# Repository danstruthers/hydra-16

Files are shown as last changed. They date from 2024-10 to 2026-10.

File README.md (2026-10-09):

## **Hydra 16**

A multitasking 65C02 computer and its operating system, HydraOS.

The Hydra-16's hardware gives each of 16 tasks its own 32K of RAM, zero page and stack included, with its own RAM and ROM bank selections, so a task switch is one register write.  HydraOS runs on it, Plan 9's way:
* **One kernel** in the BIOS ROM: a preemptive scheduler, one interrupt path, notes, memory and banks, and a jump table made from a specification.  Everything else is a module of the paged ROM, run in place in a task of its own.
* **A base to build on:** the kernel, a serial console driver, the kernel's devices and Woz's monitor are the base (`base/`), which HydraOS is built on and which boots on its own: [write an OS of your own](base/docs/os.md) on it.
* **Everything a file:** devices are file servers (the console's windows, the disks and HydraFS, sound, GPIO and I2C, the clock, the Vera X, and `/pc`, a folder on the PC over the serial line), and each task has a namespace of its own, built by binds and mounts.
* **Shells and languages:** rc, Plan 9's shell, and the core tools; HyForth (Forth 2012), the login shell; hylang (danlang, a lisp); BASIC (Microsoft's); SDKs for C (cc65) and assembly, and `as`, an assembler on the Hydra itself.
* **Tools:** a screen editor (`edit`), a debugger (`db`), a song player that plays ZSM songs and compiles scores as it plays.

The code is built with **cc65** (https://cc65.github.io/), and the board is designed in **KiCad 9** (https://www.kicad.org).

### **Quick start**

```
cd base
node build.js                      the base alone: the kernel, ser, kdev, the monitor (bin/bios.bin, bin/prom0.bin)
node sim/run.js -i                 its monitor in your terminal (Ctrl-A x quits)

cd ../reborn
node build.js                      build HydraOS (needs Node.js and cc65): bin/bios.bin, bin/prom0.bin ...
node sim/run.js -i                 use the Hydra in your terminal, in the emulator (Ctrl-A x quits)
node sim/web.js                    the emulator in a browser: one file, obj/web/hydra-16.html, to open
node sim/test.js                   the regression tests
```

The ROM images are in Git (`reborn/bin/`) and on each GitHub release, so the chips can be programmed without a toolchain.

### **Documentation**

| | |
| :-- | :-- |
| [The guide](reborn/docs/hydra-16.md) | The whole system in one place, hardware and software, with links to the rest ([as a PDF](reborn/docs/hydra-16.pdf): the guide, the tutorial, the guides, the programmer's guide and the hardware reference as one book, to print) |
| [The base](base/README.md) | The kernel, its console and devices, the monitor: building, running and testing it, [the monitor](base/docs/monitor.md), [writing an OS on it](base/docs/os.md) |
| [HydraOS](reborn/README.md) | Building, running and testing it, and its tree |
| [The first hour](reborn/docs/tutorial.md) | A tutorial: switching it on, the shell, files, windows, the languages, sound, a program of your own |
| [The guides](reborn/docs/using/README.md) | rc, the tools, HyForth, hylang, BASIC |
| [The programmer's guide](reborn/docs/programming/README.md) | Calls, memory, tasks and notes, files and namespaces, servers and drivers, modules, video |
| [Status](reborn/docs/status.md) | Where it stands, what was measured, what's next |
| [The hardware reference](reborn/docs/hardware.md) | The board (V1), its cards and the Vera X, in detail |
| [The plan and the design notes](reborn/docs/design/README.md) | How HydraOS was designed, and the plans |

### **Repository**

| Folder | What |
| :----- | :--- |
| `base/` | The base: the kernel (the BIOS ROM), the system calls' specification, the console driver `ser`, the kernel's devices `kdev`, the monitor `wozmon`, the assembly SDK's core, the board's emulator and the tests' runner |
| `reborn/` | HydraOS, on the base: its modules, the SDKs, the ROM disk, its tests, and every document (`reborn/docs`: the guide, the hardware reference, the plan and the design notes) |
| `board/` | KiCad schematics and PCBs: main board, memory daughter card, bus breakout card |
| `old/` | The old system (the 1.8C line: `os_rom/`, its programs, emulator, build and documents), frozen at HydraOS 1.0; `node old/build.js test` still builds and tests it |

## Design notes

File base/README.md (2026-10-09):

## **The Hydra-16 base**

The base is the part of the Hydra-16's software that every system on the board shares: the kernel in the BIOS ROM and
its system calls, the IRQ handling, a serial console driver, the kernel's device server, and a monitor.  It is the
base HydraOS 1.0 runs on (`../reborn`, which builds on this folder), and it is enough to write an operating system of
your own on: [writing an OS on the base](docs/os.md).

Booted on its own, it is three tasks and a monitor:

| Task | Module | What it is |
| :--- | :----- | :--- |
| 0 | the kernel | The BIOS ROM (`bin/bios.bin`, `kernel/`): the boot and POST, the scheduler and the tick, tasks, memory and banks, semaphores, shared segments, notes, the clock, files and the server protocol, namespaces, the loader; 192 system call slots at `$F800` |
| F | `ser` | The console driver: the serial port (`#c`: `cons`, `consctl`, `ser`, `serctl`), on the serial layer HydraOS's console shares (`lib/serial.inc`) |
| E | `kdev` | The kernel's devices: the modules (`#m`, which `SPAWN` reads), null and the kernel's messages (`#n`), the tasks (`#p`), pipes (`#|`), the environment (`#e`), named shared segments (`#s`), the ticks (`#t`), raw RAM (`#r`) |
| 1 | `wozmon` | The monitor, as init: [Woz's Apple 1 monitor](docs/monitor.md), with a disassembler |

The rest of the tasks, 2 to D, are free for whatever runs on it.

```
Hydra-16: kernel 0.1, ABI 1
POST ZP:0 ST:0 OS:0 HI:0 SH:S W:0
RAM U:0 F0:0/00/0000 F4:0/00/0000 F8:0/00/0000 FC:0/00/0000 00:0/00/0000 10:0/00/0000
POST ok
RAM modules: 02
task F: ser
task E: kdev
task 1: wozmon

Hydra-16 monitor (Woz's): XXXX examine, XXXX.YYYY a block, XXXX: BB store, XXXXR run;
L instructions, K bytes; Escape the line, Ctrl-C back here.
T1 00>
```

### **Building, running and testing it**

With Node.js 18 or later and cc65 (`ca65`, `ld65`: `$CC65_BIN`, `$CC65_HOME/bin`, `C:\source\cc65\win64_snapshot\bin`, or
the PATH):

```
node build.js            the kernel (bin/bios.bin), the modules (ser, kdev, wozmon), the paged ROM (bin/prom0.bin),
                         the assembly SDK's hydra.inc (sdk/asm), the budgets
node sim/run.js -i       the base in the emulator, its serial console in your terminal (Ctrl-A x quits, Ctrl-A h helps)
node sim/test.js         the base's tests (the boot, the monitor, the kernel's own tests)
```

The images are in Git (`bin/`), so `node sim/run.js -i` works without cc65.  On the board, `bin/bios.bin` goes into
the BIOS ROM's socket and `bin/prom0.bin` into the first paged ROM socket (U31), as for HydraOS (its BIOS ROM is this
one, byte for byte); a terminal at 9600 baud on the serial port is the console.  `node ../reborn/build.js` builds this
first, then HydraOS on it.

### **The tree**

| Folder | What's there |
| :----- | :--- |
| `kernel/` | The kernel: the BIOS ROM's 16 pages (`bios.cfg`), the reset stub and vectors on each, the COMMON block (the IRQ entry and exit, the far call), the scheduler, tasks, memory, semaphores, notes, the clock, files, namespaces, the loader, POST |
| `include/` | `hw.inc`, the board as the software sees it; `layout.inc`, where every piece of the kernel's state is |
| `spec/` | `api.def` (the system calls: the jump table, `hydra.inc` and the reference are made from it) and `errors.def` (the error codes and their texts) |
| `modules/` | The base's modules, a folder each: `ser`, `kdev`, `wozmon`; `rom.txt`, the paged ROM's list and its init; `module.cfg` ... `module8.cfg`, a module's link (one bank to eight) |
| `lib/` | Sources shared with HydraOS's modules: `serial.inc` (the serial port's layer: `ser`'s and `cons`'s), `dis.inc` and `w65c02.inc` (the disassembler and the W65C02S's instructions: `wozmon`'s and HydraOS's asm library's) |
| `sdk/asm/` | The assembly SDK's core: `hyx2.inc` and `hyx2.cfg` (a module's or a RAM program's header and link), `macros.inc`, `srvlib.inc` and `srvlib.s` (the server library a driver is built on), and `hydra.inc` (the calls, the error codes and the constants: made from `spec/` by the build, and in Git, so a program can be built against it without one) |
| `tools/` | `apigen.js` (the spec into the jump table, the error texts, `hydra.inc`, `api.json`), `romimg.js` (a paged ROM image: the module directory, the hardware test, the modules), `check.js` (only the kernel writes `T`, `V`, `W`), `budget.js` |
| `sim/` | The board's emulator, cycle by cycle (`lib/`: the W65C02S, `T`/`U`/`V`/`W`, the ACIA, the VIA, the YM2151, the DS1747, a Vera X card, SD cards), `run.js` (any system's images, live or for a while; the monitor, breaks, the call trace), `view.js` (the screen and sound in a browser), `test.js` (the tests' runner, HydraOS's too) |
| `tests/` | `tests.js`, the base's tests; `mod/`, their modules (and `testlib.inc`, HydraOS's test modules' too) |
| `bin/` | The images (in Git): `bios.bin`, `prom0.bin` |
| `docs/` | [The monitor](docs/monitor.md); [writing an OS on the base](docs/os.md) |

The bank-1 hardware test is the old system's, unchanged (`../old/os_rom/bin/paged_rom_C02.bin`'s bank 1); POST starts
it if T is typed during the boot.  The kernel's design and its calls are documented with HydraOS: [the
conventions](../reborn/docs/conventions.md), [calling the system](../reborn/docs/programming/calls.md), [modules and
servers](../reborn/docs/programming/modules.md), [the hardware reference](../reborn/docs/hardware.md); the plan for
this folder is [BASE.md](../reborn/docs/design/plans/BASE.md).

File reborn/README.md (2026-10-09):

# HydraOS

HydraOS is the Hydra-16's operating system, rebuilt from the ground up by the plan in
[docs/design/reimplementation-from-scratch.md](docs/design/reimplementation-from-scratch.md): one kernel in the BIOS ROM,
everything else modules in the paged ROM run in place in tasks of their own, one way to call the system (a
jump table made from a specification), one interrupt path, and every performance-critical mechanism measured
in the emulator before anything depends on it.  Its first release, 1.0, is the plan's parity release (October 2026);
the old system is beside it in [../old](../old), frozen since (`old/os_rom/`, its programs, emulator and documents).

The whole system, hardware and software, in one place: [docs/hydra-16.md](docs/hydra-16.md), the guide (and
[docs/hydra-16.pdf](docs/hydra-16.pdf), the guide, the tutorial, the guides, the programmer's guide and the hardware reference as one book, to print).  The board in full:
[docs/hardware.md](docs/hardware.md).  How it was designed: [docs/design](docs/design/README.md), the plan and the notes.
Where it stands, step by step against the plan, and the spikes' measurements: [docs/status.md](docs/status.md);
HyForth's, from step 6.6 on: [docs/forth-status.md](docs/forth-status.md).
Using it: [docs/tutorial.md](docs/tutorial.md) (the first hour) and [docs/using](docs/using/README.md) (rc, the tools,
HyForth, hylang, BASIC); writing for it: [docs/programming](docs/programming/README.md), the programmer's guide.
The rules every source here follows: [docs/conventions.md](docs/conventions.md).

## Build, run, test

Node.js 18 or later, and cc65 (`ca65`, `ld65`, and for the C programs `cc65`, `ar65` and its `include`, `asminc` and
`lib`): `$CC65_BIN`, `$CC65_HOME/bin`, `C:\source\cc65\win64_snapshot\bin`, or the PATH.

```
node build.js                       the BIOS ROM (bin/bios.bin), the paged ROM (bin/prom0.bin, prom1.bin ...: a 512K
                                    image for each socket it fills; the modules, the old hardware test in bank 1, the
                                    ROM disk), the budget report
node sim/run.js                     boot them in the emulator for a while, then report (the output, the tasks)
node sim/run.js -i                  the Hydra's serial console, live (Ctrl-A x quits, Ctrl-A h helps)
node sim/run.js -i --sd card.img    the same with a card in SD device 0 (an image: sim/tools/hydrafs.js)
node sim/run.js -i --sound          the same, its sound heard in a browser (http://localhost:8016, its Sound
                                    button: the YM2151, and with --vera the Vera X's PSG and PCM); --wav FILE
                                    keeps it in a file
node sim/run.js -i --pc-dir DIR     the same with the folder DIR at /pc (the emulator plays the PC tool:
                                    sim/tools/hydrapc.js on a real PC)
node sim/web.js                     the emulator in a browser: obj/web/hydra-16.html, one file with the page, the
                                    emulator and the images in it, to open in Chrome, Edge, Firefox or Safari (or
                                    --serve: at http://localhost:8017).  The serial console is a terminal in the
                                    page; the Vera X's screen, keyboard and mouse, the sound, the clock chip, the RAM
                                    modules and SD cards (kept in the browser) its Setup.  --check boots it in Node
node sim/run.js --trace-calls       each system call a program makes, by name, and what it gives back; --break K_OPEN
                                    (or rc:main ...) stops there; with -i, Ctrl-A b is a monitor (step, registers,
                                    memory, breaks, watches): the top of sim/run.js has them all
danlang sim/dl/run.dl -i            the serial console in the danlang emulator (Ctrl-] x quits, Ctrl-] h helps;
                                    Ctrl-C is the Hydra's); --input "\phylang\r" starts hylang at the first prompt
node build.js prog DIR              a program of your own, DIR/*.s into DIR/NAME.hyx (sdk/asm/README.md), or
                                    DIR/*.c (and *.s), a C program (sdk/c/README.md)
node sim/test.js                    the regression tests, with their time budgets: as many at a time as the CPU has
                                    cores, each in a process of its own (-j N: N at a time; -j 1, one after another)
node sim/test.js irq -v             one test, with its output
node sim/test.js --dl               the same tests in the danlang emulator (sim/dl: danlang's Release build, ../danlang
                                    or $DANLANG), judged the same way
node tools/docpdf.js                docs/hydra-16.pdf, the documents as one book to print (Edge or Chrome prints it):
                                    after changing one of them, made again and committed with it
```

`build.js --clock 2` builds for a 7.16 MHz board (jumper J8); `--acia wdc` for a WDC W65C51N in the serial
port.  The ROM images in `bin/` (`bios.bin`, `prom0.bin` ...) are in Git, for programming the chips without a
toolchain: rebuild and commit them with a change to what's in them (and a merge's conflict in one: rebuild).  The
rest of `bin/`, and `obj/`, are the build's (`bin/sdk/asm` and `bin/sdk/c` are the SDKs, whole, to take away).

## The tree

| Folder | What's there |
|---|---|
| `../base/` | The base HydraOS is built on ([its README](../base/README.md)): the kernel (`kernel/`), `include/` (`hw.inc`, `layout.inc`), `spec/api.def` and `errors.def`, the console driver `ser` and the kernel's devices `kdev` (`modules/`), `lib/serial.inc` (`cons`'s serial layer), `lib/dis.inc` and `w65c02.inc` (the asm library's), the assembly SDK's core (`hyx2.inc`, `hyx2.cfg`, `macros.inc`, `srvlib`), the modules' links (`module*.cfg`), `tools/` (`apigen.js`'s kernel half, `romimg.js`, `check.js`, `budget.js`), the board's emulator (`sim/lib`, `run.js`, `view.js`, `test.js`) and the kernel's tests.  `build.js` runs its build first, and its BIOS ROM is ours |
| `spec/` | `numbers.def` and `asm.def` (the libraries' entries); and, in `../base/spec`, `api.def`, the system calls (each call's group, slot, registers, errors and words), and `errors.def`, the error codes: the one source for the jump table, `hydra.inc`, the reference and the emulator's names; `numbers.def` and `asm.def`, the libraries' calls (their jump tables, `numbers.inc` and `asmlib.inc`, C's `numdefs.h` and `asmdefs.h`) |
| `include/` | `hw.inc`, the board as the software sees it (facts only); `layout.inc`, where every piece of the kernel's state lives |
| `kernel/` | The kernel: the BIOS ROM's 16 pages (`bios.cfg`), the reset stub and vectors on each, the COMMON block (and the far call), interrupts, the scheduler, calls between tasks and kcopy, tasks and modules, notes, the console calls (to fds 0 and 1, or the bring-up console), the small calls (page 0); the kernel task's side of tasks, the boot, memory, TASKINFO, TASKREAD and TASKMEM (a task's state and memory, for /proc), the clock and the DS1747 (page 1); files, names, the server calls and the environments (page 2); namespaces, `SPAWN` and the loader (page 3); POST, and the debugger's steps (`TASKSTEP`: page 4) |
| `modules/` | The paged ROM's modules, a folder each (`init`, `hello`, `cons`: the console driver and `/pc`, a module of two banks (`vt.s`: each window's screen in its RAM banks, written by a VT100), `storage`: the SPI bus, the disks and HydraFS, a module of two banks, `kdev`: the kernel's devices, `snd`: the sound driver (`#a`: the YM2151's channels 0-7, and with a Vera X its PSG's voices as 8-23), `gpio`: the VIA's port A (`#g`) and the I2C bus on it (`#i`), `vid`: the Vera X's driver (`#v`: its screen and terminal, VRAM, the palette, sprites, the font, its PSG and its PCM), `rc`: the shell, of two banks, `wstart`: the shell in each window the user asks for (`/lib/shell`'s, else rc), the core tools: `ls`, `cp`, `mv`, `rm`, `ps`, `top`, `wc`, `more` ..., and `ed`, the line editor, `as`, the assembler (the asm library's, its command line), `play`, the song player (ZSM songs, scores, WAV files), `date`, `xmodem`, `forth`, HyForth's core (and a shell: `forth -l`, the login shell), `basic`, BASIC, `hylang`, the lisp, `hysnap`, hylang's start-up snapshot, and the libraries: `numbers` and `math`, the number system, and `asm`, the W65C02S's instructions as `as` writes them, its assembler as's and BASIC's ASM blocks', its disassembler db's, HyForth's and dis's, one table for both); `module.cfg`, their link (`module2.cfg` to `module8.cfg`, a module of two to eight banks; a folder's own `NAME.cfg`, for one with library modules of its own); `rom.txt`, which go in the ROM and which is init |
| `forthlib/` | HyForth's libraries, a word set each (`NAME.s`, built into `/lib/forth/NAME.fl` on the ROM disk), and `forthlib.inc` and `forthlib.cfg`, a library's definitions and its link |
| `programs/` | The ROM disk's programs (`/rom/bin`: RAM programs, a folder each: `mkfs`, `fsck`, `label`, and `grep`, `sort`, `db`, the debugger, `dis`, the disassembler, and `edit`, the screen editor, in C), and `diskctl.s`, what the disk tools share |
| `sdcard/` | The SD card's files (`bin/sdcard.img`, `tools/sdcard.js` makes it: a 16 MB HydraFS in a partition): `sdcard.txt`, its manifest (the samples, built, and their sources; the songs; the benchmarks), `songs/` (`test.zsm`, `vera.mml`) and `bench/` (hylang's, HyForth's and BASIC's: `sim/bench.js`); in SD device 0, `/sd/0`.  `sim/tools/sdwrite.js` writes the image to a card on the PC |
| `romfs/` | The ROM disk's files (`/rom`: `README`, `lib/namespace`, `lib/profile`, `lib/shell`; the languages' and tools' files in `lib/forth`, `lib/hylang`, `lib/basic`, `lib/as`, `lib/edit` and `lib/font`; `songs/scom.zsm`; its `doc/api.md` and `bin` come from the build) and `romfs.txt`, its manifest; bytes for the Hydra, with LF line ends (`.gitattributes`: not text to Git) |
| `sdk/asm/` | For programs in assembly: `hyx2.inc` (the module header), `hyx2.cfg` (a RAM program's link), `macros.inc`, `srvlib.inc` and `srvlib.s` (the server library), `nslib.s` (a task's default namespace: Plan 9's `newns`), `toollib.inc` and `toollib.s` (what the tools share), `samples/` (on the SD card, `/sd/0/sample`: bin/sdcard.img), and `README.md`, the SDK's guide; with `obj/sdk/hydra.inc`, made from `spec/` |
| `sdk/c/` | For programs in C (cc65): `include/hydra.h`, `hydra.cfg` (the link), `lib/` (the library's sources: the start-up, files and buffered stdio, the environment, `system`, `signal`, conio ...; built with cc65's `none.lib` into `obj/sdk/c/hydra.lib`), `samples/` (`/sd/0/sample/c`, `ctest` the library's test), and `README.md`, its guide; with `obj/sdk/c/hydracalls.h`, made from `spec/` |
| `tools/` | `apigen.js` (the specification's outputs: the jump table, `hydra.inc`, the C header, the reference, HyForth's sys- words and `hydra.fs`), `decfont.js` (the DEC Special Graphics as the console's fonts' first 32 glyphs), `forthlib.js` (HyForth's libraries: the core's labels and id, each library's file), `romimg.js` (the paged ROM image), `romfs.js` (the ROM disk: its HydraFS volume, made with `sim/tools/hydrafs.js`, and its files read back from the image), `budget.js` (sizes and room left), `check.js` (only the kernel writes T, V and W), `hysnap.js` (hylang's start-up snapshot, the module `hysnap`: its heap with its library loaded, made by running hylang in the emulator), `hyvmxt.js` (hylang's native code's templates, `modules/hylang/vmxt.inc`), `docpdf.js` (`docs/hydra-16.pdf`, the documents as one book: printed by Edge or Chrome, headless) |
| `sim/` | `run.js` and `test.js` over `lib/`, `consbench.js` (the console's costs: `--vs` another tree), `lib/vt.js` (a VT100's screen, the tests' model of a terminal), the emulator (a copy of the old system's, `../old/sim/lib`, with a receive-latency counter added to the ACIA, IRQs-off stretches ended where an interrupt is taken, an I2C bus on port A: `i2c.js`, and nothing allocated for an instruction run, which makes it about six times as fast: some 20 MHz of the Hydra's cycles), `lib/pchost.js`, the PC tool's part of `/pc` (its file server: `sim/tools/pcfs.js`), `lib/vera.js` (a Vera X card), and the sound: `lib/ym2151.js` with `lib/opm.js` (ymfm's YM2151) and `lib/audio.js` (the chips' sound mixed); `view.js` (the screen and the sound in a browser: `run.js -i --view`, `--sound`), `web.js` and `web/` (the whole emulator in a browser: one HTML file, the machine in a Web Worker, `lib/vt.js` its terminal), `bench.js` (hylang's, HyForth's and BASIC's benchmarks, side by side), `speed.js` (the numbers' costs by stretch, `tests/speed/`'s programs, against another build or a table saved before); `tools/`, the PC's tools: `hydrapc.js` (the PC tool, the terminal and `/pc`'s server: `npm install` here for its serial port), `pcfs.js` (its file server), `hydrafs.js` (card images), `sdwrite.js` (an image onto a card in the PC's reader: `--list` the disks, then IMAGE DISK; it refuses the system's disk, and one that isn't removable without `--force`, and reads it back), `hysong.js` (the score language to ZSM), `numfmt.js` (the stored format of numbers, the libraries' reference: docs/design/plans/NUMBERS.md), `numref.js` (the number system in JavaScript, danlang's, the numbers library's reference), `numxcheck.js` (numref.js against danlang: random numbers and expressions), `hyxcheck.js` (hylang against danlang: random number expressions, the math functions), `nprof.js` (a profiler by stretch: a program's marks, its cycles by module and label, by library call and by routine) |
| `sim/dl/` | The emulator again, in danlang (`../danlang`, its `feature/speed` branch): `cpu.dl` (the W65C02S: its code, the ROMs' and RAM's, decoded into blocks, kept), `machine.dl` (the memory map, the IRQ lines, the run loop), `devices.dl` (the ACIA, the VIA, the YM2151), `spi.dl` (SD cards, echo devices), `i2c.dl`, `rtc.dl` (the DS1747); `hydra.dl`, a test run from the spec `bridge.js` writes (`sim/test.js --dl`: the PC's end of `/pc` and XMODEM stays in JS, over danlang's stdin and stdout; `$HYDRA_DL` runs a copy of these files); `run.dl`, a run on its own, or the serial console live (`-i`, as `run.js`'s, from danlang's `key?`, `key` and `on-note`); `image.js`, a test's paged ROM image |
| `tests/` | `tests.js`, the tests and their budgets; `mod/`, the test modules (each runs as init) and `testlib.inc`; `ram/`, the test RAM programs (put on an emulated card by the load test); `forth/`, the Forth 2012 test suite (its README); `hylang/`, danlang's regression suite, which hylang passes (the hysuite tests; its README); `hyhydra/`, hylang's own checks of its Hydra layer; `basic/`, BASIC's suite (the bsuite test) |
| `docs/` | `hydra-16.md` (the guide: the whole system in one place) and `hydra-16.pdf` (the guide, the tutorial, the guides, the programmer's guide and the hardware reference as one book, to print: `tools/docpdf.js` makes it), `hardware.md` (the board, its cards and the Vera X), `design/` (the plan HydraOS was built to, and the design notes), `tutorial.md` (the first hour), `using/` (the guides: rc, the tools, HyForth, hylang, BASIC), `programming/` (the programmer's guide: calls, memory, tasks and notes, files and namespaces, servers and drivers, modules, video), `conventions.md`, `status.md`, `hylang.md` (hylang, phase 7: the language, danlang's, and its design on the Hydra), `basic.md` (BASIC's design: its compiler, its stack machine, its banks), `hyforth.md` (HyForth's additions, 6.6-6.21: the old HyForth's pieces back, HyForth as a shell, hylang's Hydra words and device libraries, compile-only words, the word lists' index, the standard's other word sets, faster loading, the storage driver's walk cache), `forth-status.md` (where HyForth stands from 6.6 on) |

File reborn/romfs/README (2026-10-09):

The Hydra-16's ROM disk
=======================

This is /rom: files kept in the paged ROM, read only, there with no card in the
machine.  It's a HydraFS volume, as a card's is, in the paged ROM's banks after
the modules (the disk x: mount '#f' /rom x).

  README          this
  lib/namespace   the default namespace: what's bound and mounted where.
                  init runs it as it starts, and a card's /lib/namespace
                  after it
  lib/profile     what each shell runs as it starts (and a card's
                  /lib/profile after it)
  lib/forth       HyForth's libraries (REQUIRE finds them): its word sets,
                  pre-compiled (REQUIRE tools.fl): coreext.fl, exception.fl,
                  file.fl, facility.fl, string.fl, search.fl, tools.fl,
                  double.fl, and hydra.fl (the sys- words, SH, RUN, banks);
                  hydra.fs, the system's constants and error codes; and
                  startup.fs, what forth loads as it starts
  lib/hylang      hylang's library (load finds a bare name there):
                  danlang's, globals.hl (in hylang as it starts, from its
                  snapshot in the paged ROM), dice.hl and screen.hl
  doc/api.md      the system calls, their registers and their errors
  bin             programs read into RAM to run: mkfs, fsck, label, and
                  grep and sort (in C); scom, a song (an rc script); bound
                  at /bin after the RAM disks'
  songs           songs for play: ZSM files, the Commander X16's (play
                  /sd/0/songs/test.zsm)
  sample          the SDKs' samples: hi, upper and tick in assembly; in
                  sample/c, hello, upper, code, keys, tones, jukebox and
                  ctest in C

The modules in the paged ROM (the drivers, init, the programs) are under
/dev/mod (#m), a file each.  Cards are under /sd (/sd/0 ... /sd/f), the RAM
disks at /ram (each shell's own area) and /sram (shared).

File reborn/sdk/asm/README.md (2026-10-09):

# The assembly SDK

Programs for the Hydra-16 in 65C02 assembly, with the cc65 tools (`ca65`, `ld65`).  A program is a HYX2 file: a
48-byte header, then its code and data, which `SPAWN` reads into a task's RAM at `$0800` and starts.  Put it on a
card or a RAM disk, and rc runs it by its path, or by its name from `.` or `/bin`.

The SDK is this folder; `node build.js` also copies it, with the generated `hydra.inc` and the samples, to
`bin/sdk/asm`, to take elsewhere.

| File | What it is |
|---|---|
| `hydra.inc` | The system calls (their addresses in the jump table), the error codes and the constants.  In the base (`base/sdk/asm/hydra.inc`), made from `base/spec/api.def` by the build and kept in Git; never edit it |
| `hyx2.inc` | The header: `HYX2_PROGRAM "name", main` |
| `hyx2.cfg` | The link for a program in a file: header, code and data from `$0800`, the BSS after them |
| `macros.inc` | `CALL name` (a system call), `CHECK label` (on to label if the call failed), `LDR reg, value` (a call register = a 16-bit value), `MOVR to, from` (one register = another), `PRINT label` or `PRINT "text"` (a string to fd 1); `CR`, `LF`, `TAB` |
| `toollib.inc`, `toollib.s` | What the system's tools share: flags, errors and exit statuses as Plan 9's, buffered output, input a file at a time, directories, paths, numbers (the comment at its top lists them) |
| `srvlib.inc`, `srvlib.s` | A file server's library (the system's drivers use it) |
| `nslib.s` | A task's default namespace, from the namespace file (Plan 9's `newns`) |
| `numbers.inc` | The number libraries' calls (hylang's, HyForth's, BASIC's and C's numbers: exact integers of any size, fixed decimals, rationals, complex numbers; their arithmetic, text in every base, the math functions): each entry's address (`NUM_ADD`, `MATH_SQRT` ...), the constants, and the macros `NUMCALL` and `MATHCALL` that call them.  Made from `spec/numbers.def` by the build (`sdk/asm/numbers.inc`, kept in Git), whose comments say each entry's registers; never edit it |
| `numlib.s` | `num_open`: the number libraries found and readied (a RAM bank of the program's made theirs), for `NUMCALL` and `MATHCALL` |
| `asmlib.inc` | The asm library's calls (the W65C02S's instructions as `as` writes them: `ASM_DIS`, one disassembled; `ASM_FILE`, a source assembled as `as` does it; `ASM_BEGIN` ... `ASM_DONE`, a source a line at a time), its constants (`DIS_MAX`, `DF_PAD`, the kinds `DK_`, `ASM_RAM`, the flags `AF_`) and the macro `ASMCALL` (`r14` from `asm_mod`, the library's bank: `MODINFO` finds the module `asm`).  Made from `spec/asm.def` by the build (`sdk/asm/asmlib.inc`, kept in Git) |
| `samples/` | `hi` (arguments, task, directory, environment), `upper` (a filter on `toollib`), `tick` (a note handler), `counter` (a server: a driver, a module that runs in place, on `srvlib`), `nsum` (numbers: the sum of its arguments, and its square root) |

The calls are described in `/rom/doc/api.md` on the Hydra (the build's `obj/gen/api.md`), and the rules the
system keeps in `docs/conventions.md`.

The Hydra assembles the same sources itself: `as file.s` (`docs/using/tools.md`, "The assembler"), with this
folder's `.inc` and `.s` files in `/lib/as`, makes the same program ca65 and ld65 make with `hyx2.cfg`.

## A program

```
.include "hydra.inc"
.include "hyx2.inc"
.include "macros.inc"

            HYX2_PROGRAM "hello", main

.code
main:                                       ; r0: the arguments
            PRINT       "Hello"
            lda         #LF
            CALL        PUTC
            lda         #0                  ; (Returning: EXITS with code 0)
            rts
```

* `main` gets `r0` pointing at its arguments: zero-terminated strings one after another, an empty one after the
  last (`hello a b`: `"a", 0, "b", 0, 0`).  Its name is the header's (11 characters at most).
* Returning ends the task with code 0.  `EXITS` ends it with a code (`.A`) and a message (`r0`, or 0): rc's
  `$status` is the message if there is one, else the code (true is 0).
* A call is a `jsr` to its name (`CALL name` says the same).  Arguments and results are `.A`, `.X`, `.Y` and the
  call registers `r0`-`r15` (`$02`-`$21`); a call may change all of them.  C = 0 is success; C = 1 is failure,
  with the error in `.A` (`ERRSTR` gives its text: `"not found"`); `CHECK label` goes on to label on a failure.
* The program's own zero page is `$22`-`$7F` (`.zeropage`: no call touches it); its RAM is `$0800` up to its
  break (`BREAK` moves it), and pages above (`PAGES_ALLOC`), to `$7FFF`.  It has its own RAM banks at
  `$8000`-`$9FFF` too (16 a RAM module: `BANKS`), and its stack.
* Its fds 0, 1 and 2 are its window's console, or what rc gave it (`<`, `>`, `|`); `PUTC`, `PUTS` and `GETC`
  write and read them a byte or a string at a time; `OPEN`, `READ`, `WRITE` and `CLOSE` do the rest.  Names go
  through its namespace, as rc's do.
* A note (Ctrl-C at its window: `NOTE_INTERRUPT`) ends it, unless it has a handler (`NOTIFY`: `tick`).
* Its environment (`ENV_GET`, `ENV_PUT`) is a copy of rc's: rc's variables, `$window`, `$path` ...
* Numbers: `.include "numbers.inc"` at its top and `numlib.s` at its end; `num_open` readies the libraries, then
  `NUMCALL NUM_ADD` (`MATHCALL MATH_SQRT` for the math library's) is a call, its registers as `numbers.inc` says:
  the operands' addresses in `r0` and `r1`, the result's place and room in `r2` and `r3`, its length back in
  `.A`/`.X` (C = 1: `.A` an error, `NE_DIV0` ...).  A number is its bytes in the stored format (`NUM_MAX` at most);
  `NUM_PARSE` reads one from text and `NUM_DISPLAY` writes one, in the base (`NUM_SET_BASE`).  The sample `nsum`
  is one.

## Building it

In this repository, a program in a folder of its own (its `.s` files):

```
node build.js prog path/to/hello          # path/to/hello/hello.hyx
```

With the cc65 tools and `bin/sdk/asm` alone:

```
ca65 --cpu 65C02 -D HYX2_RAM -I sdk/asm -o hello.o hello.s
ld65 -C sdk/asm/hyx2.cfg -o hello.hyx hello.o
```

(`-D HYX2_RAM`: a program in a file.  Without it, `hyx2.inc` makes a module of the paged ROM, run in place, linked
with `module.cfg` (`module2.cfg` to `module8.cfg` for one of two to eight banks); those are the system's, built into the ROM with
`modules/rom.txt`.  A server is one: a
driver, `HYX2_DRIVER`, which registers a device letter and answers its clients' requests through `srvlib`.  The
sample `counter` is one; the build makes it a module, and the tools test puts it in its ROM.  A module may have
library modules of its own, `HYX2_LIBRARY`, linked by its own config: `docs/conventions.md`.)

## Running it

Copy it to a card, or to the RAM disk, and type its path (`/sd/0/hello`), or its name if it's in `.` or a `bin`
(`$path` is `(. /bin)`; a card's `/bin` is part of `/bin`).  In the emulator, from `reborn/`:

```
node sim/tools/hydrafs.js mkfs card.img 8 MINE           # an empty card image, 8 MB
node sim/tools/hydrafs.js put card.img path/to/hello/hello.hyx hello
node sim/run.js -i --sd card.img                            # then, at the % prompt: /sd/0/hello
```

The samples are on the SD card (`bin/sdcard.img`, in SD device 0): `/sd/0/sample/hi Ann Bob`, `echo hi | /sd/0/sample/upper`, `/sd/0/sample/nsum 1/3 0.5 2`, `/sd/0/sample/tick`
(Ctrl-C to stop it).

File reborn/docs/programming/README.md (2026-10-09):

# The programmer's guide

How to write programs for the rebuilt Hydra-16 (`reborn/`): what the system gives a program, how it's called, and how
the parts fit.  It's for someone who knows 65C02 assembly or C and wants to write for this system; the SDKs' guides
([../../sdk/asm/README.md](../../sdk/asm/README.md), [../../sdk/c/README.md](../../sdk/c/README.md)) cover building
and running, and `/rom/doc/api.md` on the Hydra (the build's `obj/gen/api.md`, made from `base/spec/api.def`) is every
call's reference.  The rules every part of the system keeps are [../conventions.md](../conventions.md); this guide
is the gentler way in.  The whole system in one place is [../hydra-16.md](../hydra-16.md), and the board in full
[../hardware.md](../hardware.md).

| Chapter | What it covers |
| :--- | :--- |
| [The system in one page](#the-system-in-one-page) | Below: the parts, and where a program fits |
| [calls.md](calls.md) | Calling the system: the jump table, registers, errors, the SDK's macros |
| [memory.md](memory.md) | A task's 64K, its break and pages, its banks, shared segments, semaphores |
| [tasks.md](tasks.md) | Starting and ending programs, waiting, notes (signals), time, `/proc` |
| [files.md](files.md) | Files and directories, the namespace, devices, the environment |
| [servers.md](servers.md) | Writing a server or a driver: srvlib, requests, waiting, interrupts |
| [modules.md](modules.md) | The HYX2 format, programs in RAM and in the ROM, modules of several banks, libraries and `XCALL` |
| [numbers.md](numbers.md) | The Hydra's numbers: their stored format, the number libraries and calling them, bases and text, each language's |
| [video.md](video.md) | The screen, the Vera X: `/dev/vid`'s files, the console's terminal, claiming the chip, VRAM, the registers |

## The system in one page

**The hardware a program sees.**  A 65C02 at 3.58 MHz (7.16 with a jumper).  Sixteen tasks, each with its own
`$0000-$7FFF` (zero page, stack and 32K of RAM) and its own bank registers: `$00` picks one of its RAM banks for
`$8000-$9FFF`, `$01` one of the paged ROM's banks for `$A000-$DFFF`.  `$E000-$FFFF` is the BIOS ROM, where the kernel
and the jump table live; the I/O area is `$FF00-$FFEF`, and belongs to the drivers.

**The kernel** is in the BIOS ROM, a task of its own (task 0): the scheduler (round robin, preemptive, 200 ticks a
second), the IRQ path, calls between tasks, memory, notes, files' channels and namespaces.  Its state is in task 0's
RAM, out of other tasks' reach.

**Modules** are everything else, in the paged ROM, each running in place in a task of its own: the drivers (`cons` the
console and `/pc`, `storage` the SPI bus and every disk, `kdev` the kernel's devices, `snd` the YM2151 and the Vera
X's PSG, `gpio` the VIA's port A and I2C, `vid` the Vera X: its screen, its PSG and its PCM), init, the shells and the
tools.  A program in a file (on a card, a RAM disk, `/pc`) is read into a task's RAM at `$0800` and runs there.

**Files**, Plan 9's way: every device is a file server, a tree of files; a program opens, reads and writes them with
the same calls whatever's behind them, and controls a device by writing commands to its `ctl` file.  Each task has a
namespace, the tree it sees, built from binds and mounts (`/rom/lib/namespace`), shared with its children until one
changes it.

**The console** is windows on the serial terminal, and on the Vera X's screen if there's one: each a whole console
with its own `cons`, line editor and shell.
The login shell is HyForth over rc; rc is the shell of scripts and `system()`.

```
 task 0  kernel      the scheduler, IRQs, calls, memory, notes, channels, namespaces
 task 1  init        the namespace, the RAM disks, window 0's shell, wstart
 task 2+ programs    the shells, the tools, yours: in place from the paged ROM, or in RAM from $0800
 task A  vid         #v  /dev/vid: the Vera X (with no card it ends as it starts)
 task B  gpio        #g  /dev/gpio, #i  /dev/i2c
 task C  snd         #a  /dev/snd, sndctl, bell, psg
 task D  kdev        #/ #n #t #m #p #| #e #s #r: the root, null, ticks, modules, /proc, pipes, /env, segments
 task E  storage     #S  /dev/spi, #d  /dev/sd, #f  HydraFS: /rom, /ram, /sram, /sd/N
 task F  cons        #c  /dev/cons ..., #P  /pc
```

## A first program

`sdk/asm/samples/hi/hi.s` greets its arguments and says where it runs: its arguments come at `r0`, it prints with
`PUTS` and `PUTC` (fd 1), asks the kernel its task (`GETPID`) and its directory (`GETCWD`), and reads its environment
(`ENV_GET`); returning from `main` ends it with code 0.  [calls.md](calls.md) walks through it.  Build it with `node
build.js prog DIR` (the folder of its `.s` files), and run it from a card, a RAM disk or `/pc`: [../tutorial.md](../tutorial.md),
step 8.

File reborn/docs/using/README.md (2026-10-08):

# Using the Hydra-16

The guides for using HydraOS (`reborn/`), the Hydra-16's operating system.  The first hour is [the
tutorial](../tutorial.md); the whole system, hardware and software, is [the guide](../hydra-16.md); and these are the
guides for each part:

| Guide | What it covers |
| :---- | :--- |
| [The tutorial](../tutorial.md) | Switching it on (in the emulator or on the board), the shell, files and disks, windows, the languages, a program of your own |
| [rc](rc.md) | The shell underneath everything: commands, quoting, variables, pipelines, redirection, control flow, scripts |
| [The tools](tools.md) | Every program in `/bin`: files, text, the editors, tasks, the debugger, the assembler, disks, and the rest |
| [HyForth](hyforth.md) | The Forth, and the login shell: its words, libraries, the shell rule, files, devices, sound |
| [hylang](hylang.md) | The lisp (danlang on the Hydra): its REPL and scripts, the system library, the Hydra's built-ins, devices |
| [BASIC](basic.md) | The Hydra's BASIC, in QuickBASIC's way: exact numbers in any base, procedures and records, files, sound, graphics, the system's calls, the prompt and the shell |

For writing programs: [../programming/README.md](../programming/README.md), the programmer's guide, and the SDKs'
own guides, [../../sdk/asm/README.md](../../sdk/asm/README.md) (assembly) and [../../sdk/c/README.md](../../sdk/c/README.md)
(C).  The system calls' reference is `/rom/doc/api.md` on the Hydra (made from `spec/api.def` at the build:
`obj/gen/api.md`).

## The system in a paragraph

The Hydra-16 runs 16 tasks, each with its own 32K of RAM and its own RAM banks.  The kernel is in the BIOS ROM;
everything else, the drivers and the programs, are modules in the paged ROM that run in place.  Almost everything is
a file, Plan 9's way: a device is a directory of files (the console's at `/dev`, the disks' at `/dev/sd`, the tasks'
at `/proc`), controlled by writing commands to its `ctl`.  Each task has a namespace, the tree of names it sees,
built by binds and mounts, so `/bin` is a union of the RAM disk's, the cards', the ROM disk's and the ROM's
programs.  The console is windows, rio's way on a serial terminal: each window is a whole console, shown one at a
time, in groups (a group a shell session: Ctrl-] c; Ctrl-] n and p between groups, Ctrl-] Tab between its windows,
Ctrl-] and a digit to one, Ctrl-] w a list of them; Ctrl-] s and v split one into tiles shown together; Ctrl-] [ the
scrollback, Ctrl-] y a paste of `/dev/snarf`, Ctrl-] ? the keys).  With a Vera X, they're on its screen too, and its
keyboard types into them as the serial terminal does (`echo seats >/dev/consctl` gives each its own window), and a
click of its mouse focuses one.  The login shell is HyForth over rc (`forth -l`): a line is Forth if its
first word is a Forth word or a number, else an rc command line.

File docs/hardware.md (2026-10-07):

## **Hydra-16 Hardware Reference**

This is the Hydra-16 main board (V1) as its schematic describes it (`board/hydra-16.kicad_sch` and its sheets), with the two companion cards in `board/`.  Reference designators (U25, J18, ...) are the schematic's.  For how the software uses the hardware, see the [Programmer's Guide](../old/docs/programming/README.md).

To test a board, run the [hardware test](../old/docs/using/wozmon.md#the-hardware-test) (HyForth's `hwtest`, or `T` typed during POST).

### **Contents**
1. [Overview](#overview)
2. [The CPU view: memory map](#the-cpu-view-memory-map)
3. [The pseudo-registers T, U, V, W](#the-pseudo-registers-t-u-v-w)
4. [Task RAM and the bank registers ($00, $01)](#task-ram-and-the-bank-registers)
5. [The paged RAM window ($8000-$9FFF)](#the-paged-ram-window)
6. [The paged ROM ($A000-$DFFF)](#the-paged-rom)
7. [The BIOS ROM ($E000-$FFFF)](#the-bios-rom)
8. [I/O space ($FF00-$FFFF)](#io-space)
9. [Interrupts](#interrupts)
10. [Clocks](#clocks)
11. [Reset, power and bus control](#reset-power-and-bus-control)
12. [On-board devices](#on-board-devices): VIA, ACIA (serial), YM2151 (sound), SPI
13. [Expansion slots](#expansion-slots)
14. [Companion cards](#companion-cards): the memory daughter card, the bus breakout card
15. [Connectors and jumpers](#connectors-and-jumpers)
16. [V1 errata](#v1-errata)
17. [Parts by function](#parts-by-function)

---

### **Overview**

The Hydra-16 is a W65C02S computer built for multitasking.  Its address decoding gives each of **16 tasks** its own 32K of RAM, including zero page and the stack, and its own RAM and ROM bank selections.  So switching tasks is a single write to one register, `T`.

| | |
| :-- | :-- |
| **CPU** | WDC W65C02S (U1), 3.58 MHz as built (jumper: 0.89, 1.79, 3.58 or 7.16 MHz) |
| **Task RAM** | 512K (U7, HM628512): 32K at `$0000-$7FFF` for each of 16 tasks |
| **Paged RAM** | Seen through an 8K window at `$8000-$9FFF`.  **Task banks:** up to 15 modules of 2 MB on memory daughter cards; each task sees 16 banks of 8K per module.  **Shared banks:** 2 MB on the board (U25, U27-U29), the same for all tasks: 256 banks of 8K, 16 at a time |
| **Paged ROM** | 4 MB (U30-U37, 8 x SST39SF040), seen in 16K banks at `$A000-$DFFF` |
| **BIOS ROM** | U6, SST39SF010/020/040 (128-512K): 8K pages at `$E000-$FFFF`, selected by `W` |
| **I/O** | 15 ports of 16 bytes at `$FF00-$FFEF`, plus the system port at `$FFF0-$FFFF` |
| **Interrupts** | 16 prioritised IRQ lines, each with its own vector (a 16-entry vector RAM at `$FFFE`) |
| **Devices** | 65C22 VIA (timers, SPI, I2C, GPIO), 65C51 ACIA (RS-232 on a DE-9), YM2151 + YM3012 (stereo FM sound) |
| **Expansion** | 6 slots (62-pin edge connectors, 8-bit bus), 8 SPI device headers, a GPIO/I2C header, memory card connectors |
| **Power** | ATX-24 supply (+5 V, +3.3 V, +12 V, -12 V) |

---

### **The CPU view: memory map**

What the CPU sees at each address, and what selects it:

| Addresses | What | Selected by |
| :--- | :--- | :--- |
| `$0000` | RAM bank register (writes); task RAM (reads) | per task (see below) |
| `$0001` | ROM bank register (writes); task RAM (reads) | per task |
| `$0002-$7FFF` | Task RAM (zero page, stack, program RAM) | `T` |
| `$8000-$9FFF` | Paged RAM: a task bank (`$00-$EF`) or a shared bank (`$F0-$FF`) | `$00`; `T` for task banks, `U` for shared banks |
| `$A000-$DFFF` | Paged ROM, 16K banks | `$01` |
| `$E000-$FEFF` | BIOS ROM | `W` |
| `$FF00-$FFEF` | I/O ports 0-14, 16 bytes each | |
| `$FFF0-$FFF3` | Pseudo-registers `T`, `U`, `V`, `W` | |
| `$FFF4-$FFF9` | Not decoded (reads float) | |
| `$FFFA-$FFFD` | BIOS ROM: the NMI and RESET vectors | `W` |
| `$FFFE-$FFFF` | IRQ/BRK vector RAM (16 entries) | the highest-priority active IRQ, or `V` |

Every task has its own `$0000-$7FFF` and its own `$00`/`$01` values.  All tasks share the I/O space, the shared RAM banks, the ROMs, and the pseudo-registers themselves.

---

### **The pseudo-registers T, U, V, W**
*(Sheet `FFF_Registers`)*

Four 8-bit registers in the system port.  Each is a 74F573 latch, written with the CPU's write strobe, and read back through a 74F541 buffer.  So a read gives the whole byte last written, all 8 bits.

| Address | Register | Latch / read-back | Bits used by the hardware |
| :--- | :--- | :--- | :--- |
| `$FFF0` | `T`, task | U48 / U49 | T0-T3: which task's RAM (task RAM A15-A18; the modules' task lines) |
| `$FFF1` | `U`, shared macro-page | U50 / U51 | U0-U3: shared RAM A13-A16 |
| `$FFF2` | `V`, vector select | U52 / U53 | V0-V3: the vector RAM index when no IRQ is active.  V4-V7 aren't wired: the software keeps a software interrupt number there |
| `$FFF3` | `W`, BIOS ROM page | U54 / U55 | W0-W5: BIOS ROM A13-A18 (64 pages with an SST39SF040; 16 with the '010) |

The latches have no reset, so they power up random; the reset code sets them.  Nothing on the board resets them when the reset button is pressed.  Bits 4-7 of `T` and `U`, and 6-7 of `W`, are stored but go nowhere.

---

### **Task RAM and the bank registers**

**Task RAM** is one HM628512 (U7, 512K) on the main board.  CPU A0-A14 go straight to it, CPU A15 is its chip enable (low for `$0000-$7FFF`), and `T0-T3` drive its A15-A18.  So each value of `T` selects a different 32K, and a task switch is a single write to `$FFF0`.  Zero page and the stack page are part of it, so every task has its own zero page and stack.

**A DS1747 in U7** gives the Hydra a clock that keeps the time while it's off.  The DS1747 (the 5 V part; the DS1747W is 3.3 V) is a 512K battery-backed RAM with a clock, pin compatible with the HM628512, in a 600-mil module.  Its clock registers are the chip's top 8 bytes, `$7FFF8-$7FFFF`, so they're **task F's `$7FF8-$7FFF`** (`T0-T3` reach U7's A15-A18 through U48 and U21 in order).  The ROM keeps off those bytes in every task, finds the chip at boot, and sets its clock from it ([HyForth](../old/docs/using/hyforth.md#files-and-devices)).  The rest of the chip is task RAM as before, kept while the power's off.  A new DS1747 comes with its battery disconnected until it first gets power, and its oscillator may be stopped: setting the time starts it.

**The bank registers `$00` and `$01`** *(sheet `ZPMirrorRAM`)* are four 74LS219 (16 x 4-bit RAM) chips, addressed by `T0-T3`:

| Register | Chips | Drives |
| :--- | :---- | :----- |
| `$00`: RAM bank | IC1 (bits 0-3), IC2 (bits 4-7) | `RAMB0-7`: which bank is at `$8000-$9FFF` |
| `$01`: ROM bank | IC3 (bits 0-3), IC4 (bits 4-7) | `ROMB0-7`: which paged ROM bank is at `$A000-$DFFF` |

* A write to `$0000` or `$0001` stores the byte in the current task's entry.  The address decoding (U8-U10 on sheet `AddressDecode`) spots a write to `$000x`, and U16 picks the register with A0.
* The write also goes to task RAM as usual, and a **read** of `$00`/`$01` comes from task RAM: the registers themselves are write-only, and task RAM mirrors them.
* The outputs are always enabled, so the bank lines follow `T` at once.  A task switch selects the new task's RAM bank and ROM bank without further writes.
* On V1, bits 2 and 3 of both registers are crossed on their way to the bank lines (see [V1 errata](#v1-errata)).

---

### **The paged RAM window**
*(`$8000-$9FFF`; sheets `ZPMirrorRAM`, `SharedMem`, `AddressDecode`)*

`$8000-$9FFF` shows one 8K bank.  The **bank ID** is the current task's `$00` value:

| Bank ID | What |
| :--- | :--- |
| `$m0-$mF` (m = `$0-$E`) | Task RAM module m: 16 banks for **each task** (the module's chips also get `T0-T3`) |
| `$F0-$FF` | Shared RAM: 16 banks, the same for every task, from shared macro-page `U` |

* **Module select.** The bank ID's upper nibble (`RAMB4-7`) goes to a 74LS154 (U23), qualified by the window's select (`nBRA_S`, `$8000-$9FFF` in PHI2).  Its outputs `nBRC0-nBRC14` go to the memory card connector (J1), one per module; `nBRC15` selects the shared RAM on the board.
* **Memory card connector.** The lower nibble and `T` are buffered to it by U21 (74F541), as `RAMB_M0-3` and `T_M0-3`, along with the read/write strobes (`RWB_M`, `!RWB_M`).  J2 carries D0-D7, A0-A12 and +5 V.
* **Task RAM modules** are [memory daughter cards](#memory-daughter-card): 4 x HM628512 per card, set to a module number with a jumper.  In a module:
  * `T_M0-3` go to the chips' A13-A16, so each task has its own 16 banks.
  * `RAMB_M0-1` go to A17-A18.
  * `RAMB_M2-3` pick the chip.
  * A module is 2 MB: 16 tasks x 16 banks x 8K.
* **Shared RAM** is four HM628512 on the main board: U25, U27, U28 and U29.
  * `RAMB_M2-3` pick the chip, through a 74F139 (U26) enabled by `nBRC15`.
  * `RAMB_M0-1` go to the chips' A17-A18, and `U0-U3` to A13-A16.
  * So the 16 bank IDs `$F0-$FF` are seen in 16 macro-pages (`U` = 0-F): 256 shared banks of 8K, 2 MB.
  * The software numbers them as **shared bank ID** = `U << 4 | (bank & $0F)`.

| Bank IDs (`$00`) | Shared RAM chip (V1) | Shared bank IDs |
| :--- | :--- | :--- |
| `$F0-$F3` | U25 | `$x0-$x3` for each `U` = x |
| `$F4-$F7` | U28 (V1: bits 2/3 crossed) | `$x4-$x7` |
| `$F8-$FB` | U27 (V1) | `$x8-$xB` |
| `$FC-$FF` | U29 | `$xC-$xF` |

A bank with no chip behind it (a missing module) reads whatever floats on the bus; the ROM's POST and module probe detect this.

HM628512 pins, for tracing a bad line (the POST prints bad lines by number):

| Signal | Pin | Signal | Pin |
| :----- | :-- | :----- | :-- |
| A0-A7 | 12, 11, 10, 9, 8, 7, 6, 5 | D0-D2 | 13, 14, 15 |
| A8, A9, A10, A11, A12 | 27, 26, 23, 25, 4 | D3-D7 | 17, 18, 19, 20, 21 |
| A13-A16 (`U0-U3` on shared RAM) | 28, 3, 31, 2 | ~CE, ~OE, ~WE | 22, 24, 29 |
| A17, A18 (`RAMB_M0`, `RAMB_M1`) | 30, 1 | VCC, GND | 32, 16 |

---

### **The paged ROM**
*(`$A000-$DFFF`; sheets `BankedROM`, `ZPMirrorRAM`)*

Eight SST39SF040 (512K each, U30-U37) give 4 MB, seen as 256 banks of 16K.  The bank is the current task's `$01` value:

* `ROMB0-4` go to the chips' A14-A18 (32 banks per chip).
* `ROMB5-7` pick the chip through a 74F138 (U24), qualified by the window's select (`nBRO_S`: `$A000-$DFFF` in PHI2):

| `$01` bits 5-7 | Chip | Banks |
| :--- | :--- | :---- |
| 0 | U31 | `$00-$1F` |
| 1 | U32 | `$20-$3F` |
| 2 | U34 | `$40-$5F` |
| 3 | U36 | `$60-$7F` |
| 4 | U30 | `$80-$9F` |
| 5 | U33 | `$A0-$BF` |
| 6 | U35 | `$C0-$DF` |
| 7 | U37 | `$E0-$FF` |

* **The halves are swapped.** CPU A13 goes to the chips' A13 unchanged, but in the window `$A000-$BFFF` has A13 = 1 and `$C000-$DFFF` has A13 = 0.  So CPU `$A000` reads chip offset `$2000` of the bank, and `$C000` reads offset `$0000`.  The build writes `paged_rom_C02.bin` in chip order for this, so burn it at offset 0 of U31.
* **V1: bits 2 and 3, and 6 and 7, trade places.**  On the V1 board `ROMB2`/`ROMB3` and `ROMB6`/`ROMB7` are swapped on their way to the chips (as are the RAM bank bits; the schematic shows the board as built), so the bank the CPU selects as `b` is the chips' bank `swap(b)`.  Banks whose two bits match (`$00-$03`, `$0C-$0F`, ...) aren't affected.  The build writes the image in the chips' order (`sim/tools/mkromdisk.js`), and the emulator reads it that way.
* **`nBROMD`** (a slot pin, pulled up) disables the whole paged ROM when a card pulls it low, so the card can answer `$A000-$DFFF` itself.
* The chips' ~OE is the inverted R/W; there's no write path in circuit (program the chips in a programmer).

---

### **The BIOS ROM**
*(U6, root sheet)*

An SST39SF0x0 in a 32-pin socket: the '010 (128K, 16 pages), '020 (256K, 32 pages) or '040 (512K, 64 pages).

* CPU A0-A12 go to the chip's A0-A12, and `W0-W5` to its A13-A18: each `W` value selects an 8K page.
* It's selected for `$E000-$FEFF` and for `$FFFA-$FFFD` (the NMI and RESET vectors).  I/O space and the vector RAM take the rest of `$FF00-$FFFF`.
* The build produces `os_rom_C02.bin`, 128K, for the '010.

**Changing `W` changes the code being run.**  The next instruction is fetched from the new page, at the same address.  The software handles this by keeping identical code at the same address on every page: the COMMON block at `$FD00`, and the reset entry at `$E000` (see [ROM layout](../old/docs/programming/rom-layout.md)).  Because `W` isn't reset, **every page must start with the reset code**: the RESET vector on every page points to `$E000`, which sets `W` to 0.

---

### **I/O space**
*(Sheet `AddressDecode`)*

`$FF00-$FFFF` is decoded when A8-A15 are all 1 (U14, a 74F30), qualified by PHI2 (`nIO_S`).  A 74LS154 (U19) splits it by A4-A7 into 16 ports of 16 bytes, `nIOP0_S-nIOP15_S`.  Ports 0-14 are for devices; port 15 is the system port.

| Port | Addresses | Use |
| :--- | :--- | :-- |
| 0 | `$FF00-$FF0F` | VIA (65C22, U2) |
| 1 | `$FF10-$FF1F` | ACIA (65C51, U3): 4 registers, repeated every 4 bytes |
| 2 | `$FF20-$FF2F` | Slot 0, select A (intended for video) |
| 3 | `$FF30-$FF3F` | Slot 0, select B (intended for video) |
| 4 | `$FF40-$FF4F` | YM2151 (U38): `$FF40` address/status, `$FF41` data (repeated) |
| 5-9 | `$FF50-$FF9F` | Slots 1-5, select A |
| 10-14 | `$FFA0-$FFEF` | Slots 1-5, select B |
| 15 | `$FFF0-$FFFF` | System port (below) |

**The system port** is decoded by a 74F138 (U20) on A0-A2, enabled by `nIOP15_S` and by A3 differing from A2 (U12):

| Address | Select | Use |
| :--- | :----- | :-- |
| `$FFF0-$FFF3` | `nIOB0-3` | `T`, `U`, `V`, `W` |
| `$FFF4-$FFF9` | none | Not decoded (reads float; reserved) |
| `$FFFA-$FFFD` | (BIOS ROM) | NMI and RESET vectors, from the current BIOS ROM page |
| `$FFFE`, `$FFFF` | `nIOB14`, `nIOB15` | The vector RAM, low and high bytes |

Slot port selects (`nIOA_S`, `nIOB_S` on each slot) and each slot's two IRQ lines follow the same numbering: see [Expansion slots](#expansion-slots).  A card can also decode its own addresses from the whole I/O space with `nIO_S` and A0-A7.

---

### **Interrupts**
*(Sheet `IRQ_Priorty_Encoder`)*

Sixteen active-low IRQ lines, `nIRQ0-nIRQ15`, each pulled up (RN2, RN3).  Line 0 has the highest priority.

| Line | Source | Line | Source |
| ---: | :----- | ---: | :----- |
| 0 | VIA | 8 | Slot 4, A |
| 1 | ACIA | 9 | Slot 5, A |
| 2 | Slot 0, A | 10 | Slot 1, B |
| 3 | Slot 0, B | 11 | Slot 2, B |
| 4 | YM2151 | 12 | Slot 3, B |
| 5 | Slot 1, A | 13 | Slot 4, B |
| 6 | Slot 2, A | 14 | Slot 5, B |
| 7 | Slot 3, A | 15 | Not connected: used for software interrupts |

**How it works:**
* Two cascaded 74LS148 priority encoders (U17 for lines 0-7, U18 for 8-15) find the highest-priority active line.
* Any active line asserts the CPU's ~IRQ (U44, then U22).  The IRQ input is level-triggered: a device holds its line until the handler clears it.
* A 74F157 (U45) forms a 4-bit index `q0-q3`:
  * while any IRQ line is active, the index is the encoder's output;
  * otherwise it's `V0-V3`.
* The index addresses the **vector RAM**, four 74LS219 (IC5-IC8), a 16-entry table of 16-bit vectors.  The CPU reads its IRQ/BRK vector from `$FFFE/$FFFF`, so it gets the entry for the active line, and each line has its own handler.

**The index is the line number XOR 7.**  The '148s encode active-low inputs with the highest-priority input as 7, so line n gives index `n ^ 7`: line 0 is entry 7, line 7 entry 0, line 8 entry 15, line 15 entry 8.  The ROM's `IRQ_NUMBER(n)` macro is `n ^ 7` for this reason.

**Writing vectors.**  A write to `$FFFE` / `$FFFF` stores the low / high byte of entry `q`.  That's `V0-V3` when no IRQ line is active.  So set `V` to the entry wanted, then write the vector, with no IRQ pending.  The ROM does this once at boot with interrupts off.

**BRK and software interrupts.**  `BRK` also reads `$FFFE/$FFFF`.  With no IRQ line active, that's entry `V0-V3`.  So a software interrupt is: set `V` to `IRQ_NUMBER(15)` (line 15 has no hardware), then `brk`.  The ROM keeps the software interrupt number in `V4-V7`.

**NMI** (`NMIB`, pulled up, on every slot) uses the ROM's `$FFFA` vector.  Nothing on the board drives it.

---

### **Clocks**
*(Sheet `Clocks`)*

A 14.31818 MHz crystal (Y1) with a 74ACT14 (U39) oscillator, divided by a 74F191 counter (U40):

| Clock | Frequency | Goes to |
| :---- | :--- | :--- |
| `HS_CLK` | 14.318 MHz | Slots (e.g. for video) |
| Q0 | 7.159 MHz | CPU clock jumper J8 |
| `SND_CLK` (Q1) | 3.580 MHz | YM2151 master clock; slots; CPU clock jumper J7 |
| `SER_CLK` (Q2) | 1.790 MHz | ACIA clock (XTAL1); slots; CPU clock jumper J6 |
| Q3 | 0.895 MHz | CPU clock jumper J5 |

**The CPU clock** (`PHI2`) is whichever of J5-J8 is fitted: fit exactly one.  As built, it's **J7, 3.58 MHz**.  The CPU's PHI0 input is `PHI2` gated by `DMAB` (U11), so a card asserting `DMAB` stops the CPU clock (the W65C02S is fully static).  `PHI1` (inverted `PHI2`) qualifies the address decoding.

The ROM's timing (the scheduler's tick, sound note lengths, serial timeouts) is built for one clock: `CPU_CLOCK_MULT` in `os_rom/include/hw.inc` (1 = 3.58 MHz, 2 = 7.16 MHz).  At 7.16 MHz the YM2151 is too slow for the bus: there are no wait states on V1, so don't use the sound chip at that speed.  The 0.89 and 1.79 MHz settings aren't supported by the ROM's timing.

---

### **Reset, power and bus control**

**Power** comes from an ATX-24 connector (J11):
* +5 V for the logic, +3.3 V, and ±12 V for the audio op-amps and the slots.
* +5 V standby is brought out as `+5VA`.
* The slots also have a -5 V pin, which the board doesn't supply: ATX no longer has -5 V.

**Front panel** (J10, 2x6):

| Pin | Signal |
| :-- | :----- |
| 7 | `RESB`: a push button from here to ground (pins 5, 6, 9 or 10) resets the machine |
| 8 | +5 V |
| 11 | ATX `PS_ON#`: connect to ground (a latching switch) to turn the supply on |
| 12 | Power LED: from the supply's `PWR_OK`, through R2 (470 Ω) |
| 5, 6, 9, 10 | Ground |
| 1-4 | Not connected |

**Reset** (`RESB`):
* A DM1813 supervisor (U43) holds reset low at power-up and during brown-outs.
* The front panel button and the slots (open-collector) can pull it low too.
* It resets the CPU, VIA, ACIA, YM2151 and YM3012.  It doesn't reset the pseudo-registers, the bank registers or RAM.

**Bus control:**
* **`RDY`:** pulled up through jumper **J4**, which must be fitted.  The W65C02S drives RDY low itself during `WAI`, so RDY must never be driven high directly.
* **`BE`** (bus enable): pulled up, and on the slots.
* **DMA:** a card pulls **`DMAB`** low to take the bus.
  * It stops the CPU clock, and turns off the address buffers (U58, U60, 74F541), the data transceiver (U59, 74F245) and the R/W buffer (U61, 74F125).
  * The card then drives the address and data buses itself.
* **`SYNC`** from the CPU is on the slots, for single-stepping or debugging hardware.
* `MLB`, `VPB` are unused.  `SOB` is tied high.

---

### **On-board devices**

#### **VIA (65C22, U2): port 0, IRQ line 0**
*(Registers at `$FF00-$FF0F`.)*

**Port A** is general purpose I/O, on header **J27** (2x6), with ESD protection (J28, SP720):

| J27 pin | Signal | J27 pin | Signal |
| :--- | :----- | :--- | :----- |
| 1 | GND | 2 | +5 V |
| 3 | PA0: `I2C_SCL` | 4 | PA1: `I2C_SDA` |
| 5 | PA2 | 6 | PA3 |
| 7 | PA4 | 8 | PA5 |
| 9 | PA6 | 10 | PA7 |
| 11 | CA1 | 12 | CA2 |

* PA0/PA1 are the I2C bus (bit-banged; the SDA and SCL pull-ups are in RN1), which also goes to every slot.  No I2C driver exists yet.
* **The pins, CA1 and CA2 are files:** `/dev/gpio` ([io.md](../old/docs/programming/io.md#gpio-devgpio)); CA1 can interrupt (IRQ line 0, `/dev/gpio/ca1`).
* **Port B is the SPI bus** (below).
* **Timer 1** is the scheduler's tick: free-running, 200 interrupts a second.
* **Timer 2** paces serial output when the ROM is built for a WDC ACIA.
* CB1/CB2 aren't brought out.

#### **ACIA (65C51, U3): port 1, IRQ line 1**
*(Registers at `$FF10-$FF13`.)*

**Chip and clock:**
* The board has a Rockwell R65C51 socket.  A WDC W65C51N works if the ROM is built for it: its transmitter status and interrupt don't work, so the ROM paces sending with VIA timer 2 (`SER_ACIA` in `hw.inc`).
* **The ACIA's clock is `SER_CLK`, 1.790 MHz**, not the 1.8432 MHz its baud rate table is made for.  So every rate is 2.9% slow (9600 gives about 9,320 baud), which terminals and USB serial adapters accept.
* DCD and DSR are tied active.

**Serial settings:** 9600 baud, 8 data bits, no parity, 1 stop bit at boot, with RTS/CTS.  The ROM can change the rate (300 to 19200, and 115200: the ACIA clock / 16), the data bits (5-8), the parity and the stop bits afterwards (`/dev/ser/ctl`, [io.md](../old/docs/programming/io.md#the-serial-port-settings)).

**115200 is paced.**  Sent back to back at 115200, long output (a WOZMON dump) loses and garbles characters on the board: the rate is 2.9% slow and the MAX232 is near its limit, so the receiver has little margin.  A second stop bit helps but isn't enough.  So at 115200 the ROM sends each byte from VIA timer 2 rather than the Rockwell ACIA's TDRE interrupt, with at least `SER_PACE_GAP` (2) idle bits after each character, about 4.5 with the interrupt's own time (with 1, a few characters in a whole-memory WOZMON dump were lost).  That's about 7,000 characters a second.  If long output still loses characters, raise `SER_PACE_GAP` in `os_rom/include/hw.inc` (each bit costs about 7%).  The other rates are sent back to back, as before.

**The DE-9 connector** (J3, male) is driven by a MAX232 (U5), and wired like a modem (DCE):

| DE-9 pin | Signal | Direction |
| :--- | :----- | :--- |
| 2 | Hydra transmits (ACIA TxD) | out |
| 3 | Hydra receives (ACIA RxD) | in |
| 5 | Ground | |
| 7 | ACIA ~CTS (from the terminal's RTS) | in |
| 8 | ACIA ~RTS (to the terminal's CTS) | out |

**Cable:** a PC or USB serial adapter connects with a **straight-through** cable with two female ends, not a null-modem cable.  The ACIA only transmits while its ~CTS is asserted, so the cable must carry pin 7.  Terminal programs assert RTS by default.

#### **YM2151 sound (U38): port 4, IRQ line 4**
*(Sheet `Sound`.)*

**The chip:**
* A Yamaha YM2151 (OPM, 8 FM channels), clocked by `SND_CLK` (3.58 MHz).
* `$FF40` selects a register (and reads the status: bit 7 = busy), and `$FF41` writes it.
* After a data write the chip is busy for 64 of its clocks (about 18 µs); writes while it's busy are lost.
* **CT1/CT2**, its two general-purpose outputs, are on header J9.
* **Timer B on the board:** re-armed every song tick (its flag reset through `$14`, which on the board seems to restart it), it didn't keep its period: songs timed by it ran up to twice as fast, by a different amount each run.  So the song player times songs by the system's tick (the VIA's timer 1) instead; the hardware test's timer checks (one period from a clean start) pass.

**The audio path:**
* A YM3012 DAC (U41) converts its serial output, buffered and filtered by a TL074 (U42).
* A mixer (IC9, LF353, ±12 V) adds, for each channel:
  * the YM3012's output;
  * each slot's audio lines (`SND_CL0-5`, `SND_CR0-5`), so a sound card in a slot is mixed in;
  * a line input on header J29.
* **Output:** stereo, on the 3.5 mm jack J26.  The schematic has the tip on the right channel and the ring on the left, the reverse of the usual convention (see [V1 errata](#v1-errata)).

#### **SPI bus (VIA port B)**
SPI is bit-banged on the VIA's port B (the VIA's shift register uses CB1/CB2, which aren't brought out, so it can't drive these lines); a 74F138 (U4) decodes the device select:

| Port B bit | Signal |
| :--- | :----- |
| PB0 | `SPI_CLK` (SCLK) |
| PB1 | `nSPI_CS`: low selects the device given by PB3-PB6 |
| PB2 | `SPI_MOSI` |
| PB3-PB5 | `SPI_A0-A2`: device 0-7 |
| PB6 | `SPI_A3`: 0 = the board's devices 0-7 (U4); 1 = devices 8-15, for cards to decode (the slots carry `nSPI_CS` and `SPI_A0-A3`) |
| PB7 | `SPI_MISO` |

**The eight SPI device headers** are J18-J25, for devices 0-7.  Each is a 1x6 header:

| Pin | Signal |
| :-- | :----- |
| 1 | ~CS |
| 2 | SCLK |
| 3 | MOSI |
| 4 | MISO |
| 5 | +5 V |
| 6 | GND |

The ROM runs SPI in mode 0 for SD cards, and its storage server serves an SD card on any device (`/dev/sd/N`); device 0 (J18) is the usual place for an SD card adapter.  Any other device is a file, `/dev/spi/N` (modes 0 and 3: [io.md](../old/docs/programming/io.md#spi-devices-devspi)).  The headers supply +5 V, so the adapter must regulate and level-shift to 3.3 V for the card (common SD card modules do).

---

### **Expansion slots**
*(Sheet `Connectors`: J12-J17, "Hydra bus 8-bit", 62-pin card edge.)*

Six slots, all carrying the same bus except for each slot's two port selects, two IRQ lines and its audio pair:

| Slot | Connector | `nIOA_S` (pin 51) | `nIOB_S` (pin 49) | `IRQA` (pin 55) | `IRQB` (pin 53) | Audio (`SND_CL/CR`) |
| :--- | :--- | :--- | :--- | :--- | :--- | :--- |
| 0 | J12 | port 2 `$FF20` | port 3 `$FF30` | line 2 | line 3 | pair 0 |
| 1 | J13 | port 5 `$FF50` | port 10 `$FFA0` | line 5 | line 10 | pair 1 |
| 2 | J14 | port 6 `$FF60` | port 11 `$FFB0` | line 6 | line 11 | pair 2 |
| 3 | J15 | port 7 `$FF70` | port 12 `$FFC0` | line 7 | line 12 | pair 3 |
| 4 | J16 | port 8 `$FF80` | port 13 `$FFD0` | line 8 | line 13 | pair 4 |
| 5 | J17 | port 9 `$FF90` | port 14 `$FFE0` | line 9 | line 14 | pair 5 |

Slot 0's A lines (port 2, IRQ 2) have the highest priority of the slots; the B lines of slots 1-5 the lowest.

**Pinout** (the same on every slot; `~` = active low):

| Pin | Signal | Pin | Signal |
| :-- | :----- | :-- | :----- |
| 1 | GND | 2 | ~`nBROMD` (disable the paged ROM) |
| 3 | ~`RESB` | 4 | D7 |
| 5 | +5 V | 6 | D6 |
| 7 | ~`NMIB` | 8 | D5 |
| 9 | -5 V (not supplied) | 10 | D4 |
| 11 | `BE` | 12 | D3 |
| 13 | -12 V | 14 | D2 |
| 15 | `SER_CLK` (1.79 MHz) | 16 | D1 |
| 17 | +12 V | 18 | D0 |
| 19 | GND | 20 | `RDY` |
| 21 | R/~W | 22 | `SND_CLK` (3.58 MHz) |
| 23 | ~`DMAB` | 24 | `SND_CR` (audio in, right) |
| 25 | ~`nIO_S` (any I/O port) | 26 | `SND_CL` (audio in, left) |
| 27 | `SYNC` | 28 | `I2C_SDA` |
| 29 | `SPI_SCLK` | 30 | `I2C_SCL` |
| 31 | `SPI_MOSI` | 32 | A15 |
| 33 | `SPI_MISO` | 34 | A14 |
| 35 | ~`nSPI_CS` | 36 | A13 |
| 37 | `PHI1` | 38 | A12 |
| 39 | `PHI2` | 40 | A11 |
| 41 | `SPI_A3` | 42 | A10 |
| 43 | `SPI_A2` | 44 | A9 |
| 45 | `SPI_A1` | 46 | A8 |
| 47 | `SPI_A0` | 48 | A7 |
| 49 | ~`nIOB_S` | 50 | A6 |
| 51 | ~`nIOA_S` | 52 | A5 |
| 53 | ~`IRQB` | 54 | A4 |
| 55 | ~`IRQA` | 56 | A3 |
| 57 | +5 V | 58 | A2 |
| 59 | `HS_CLK` (14.318 MHz) | 60 | A1 |
| 61 | GND | 62 | A0 |

A card's IRQ outputs should be open-collector: the board pulls each line up.  The address and data buses are buffered on the board; a DMA card drives them after asserting ~`DMAB`.

---

### **Companion cards**

#### **Memory daughter card**
*(`board/MemoryDaughterCard`: through-hole and surface-mount versions.)*

One task RAM module: 4 x HM628512, 2 MB.

* **Connectors:** it plugs into the main board's memory connectors J1 (1x32) and J2 (1x24).
* **Module number:** a 2x15 jumper block (J3) connects the card's select to one of `nBRC0-nBRC14`.  That's its module number m, so it answers bank IDs `$m0-$mF`.
* **Addressing:**
  * a 74LS139 (U1) picks one of the four chips with `RAMB_M2-3`;
  * `RAMB_M0-1` go to the chips' A17-A18, and `T_M0-3` to A13-A16;
  * A0-A12 come from J2.

Main board J1 (memory card connector):

| Pins | Signals |
| :--- | :--- |
| 1-3 | A13, A14, A15 (the card doesn't use them) |
| 5-8 | `T_M0-3` |
| 9-12 | `RAMB_M0-3` |
| 13, 14 | `RWB_M`, `!RWB_M` |
| 15-17 | GND |
| 18-32 | `nBRC0_S-nBRC14_S` (module selects) |

J2: D0-D7 (pins 1-8), +5 V (9-11), A0-A12 (12-24).

The ROM finds the installed modules at boot (`MMU_PROBE_MODULES`), tests each one's first bank in POST, and only allocates banks on modules that are present.

#### **Bus breakout card**
*(`board/HydraBusBreakoutCard`.)*  A slot card that brings every bus signal out to headers, for a logic analyzer, a scope or prototyping:

| Header | Signals |
| :----- | :--- |
| J2 | Data bus |
| J3 | Address bus |
| J4 | SPI (A0-A3, ~CS, MISO, MOSI, SCLK) |
| J5 | NMI, `nIO_S`, the slot's port selects and IRQs |
| J6 | Clocks |
| J7 | Bus control (`nBROMD`, BE, RDY, R/W, SYNC) |
| J8 | Reset |
| J9 | Audio |
| J10 | I2C |
| J11 | Power |

---

### **Connectors and jumpers**

| Ref | What | Notes |
| :-- | :--- | :---- |
| J1, J2 | Memory daughter card | Task RAM modules |
| J3 | DE-9 male: serial console | DCE wiring; straight-through F-F cable |
| J4 | RDY pull-up jumper | **Fit** |
| J5-J8 | CPU clock jumpers: 0.89 / 1.79 / 3.58 / 7.16 MHz | Fit **one**: J7 (3.58 MHz) for the standard ROM |
| J9 | YM2151 CT1/CT2 outputs | |
| J10 | Front panel | Reset, power switch, power LED |
| J11 | ATX-24 power | |
| J12-J17 | Expansion slots 0-5 | |
| J18-J25 | SPI devices 0-7 | SD card adapter on J18 (device 0) |
| J26 | Audio out, 3.5 mm stereo | |
| J27 | VIA port A: GPIO, I2C, CA1/CA2 | |
| J28 | SP720 ESD protection for J27 and the SPI lines | (a part, not a connector) |
| J29 | Line input to the audio mixer | |

---

### **V1 errata**

* **Bank register bits 2 and 3 are crossed.**
  * In the bank registers (sheet `ZPMirrorRAM`), data bit 2 drives `RAMB3`, and bit 3 drives `RAMB2`: IC1 for the RAM bank, IC3 for the ROM bank.
  * So a bank ID's bits 2 and 3 trade places before they reach the hardware.  For example, shared bank IDs `$F4-$F7` are on U28 and `$F8-$FB` on U27, module 4 and module 8 trade places, and so do paged ROM banks `$04-$07` and `$08-$0B`.
  * IDs whose bits 2 and 3 are equal aren't affected, and the software never needs to care: an ID always reaches the same memory.  It matters when you map a bank ID to a chip, for example to act on a POST report.
  * **Bits 6 and 7** are crossed too, on the V1 board as built (`RAMB6`/`RAMB7`, `ROMB6`/`ROMB7`).  The ROM's tools and the emulator assume both swaps for the paged ROM (`sim/tools/mkromdisk.js`, `os_rom/tools/romsum.js`).
* **No wait states.**  RDY only has a pull-up, so slow devices can't stretch a bus cycle.  This is why the YM2151 can't be used above 3.58 MHz.  Board V2 is planned to have programmable RDY wait states (see [plans/IDEAS.md](plans/IDEAS.md)).
* **Audio jack channels.**  J26 has the right channel on the tip and the left on the ring, per the schematic; the usual convention is the reverse, so left and right may come out swapped.
* **ACIA clock.**  The ACIA runs from 1.790 MHz instead of 1.8432 MHz, so its baud rates are 2.9% slow (see [ACIA](#acia-65c51-u3-port-1-irq-line-1)).

---

### **Parts by function**

| Function | Parts |
| :--- | :---- |
| CPU | U1 W65C02S |
| Bus buffers | U58, U60 74F541 (address); U59 74F245 (data); U61 74F125 (R/W) |
| Address decoding | U8, U9 74LS260; U10 74F20; U11 74F08; U12 74F86; U13, U16 74F32; U14 74F30; U15 74F00; U19 74LS154 (I/O ports); U20 74F138 (system port); U21 74F541 (memory card buffer); U22 74F240 |
| Pseudo-registers | U48, U50, U52, U54 74F573; U49, U51, U53, U55 74F541; U56 74F32; U57 74F02 |
| Bank registers | IC1-IC4 74LS219; U23 74LS154 (module select); U24 74F138 (paged ROM chip select) |
| Interrupts | U17, U18 74LS148; U44 74F00; U45 74F157; IC5-IC8 74LS219 (vector RAM); RN2, RN3 pull-ups |
| Task RAM | U7 HM628512 |
| Shared RAM | U25, U27, U28, U29 HM628512; U26 74F139 |
| Paged ROM | U30-U37 SST39SF040 |
| BIOS ROM | U6 SST39SF010/020/040 |
| Clocks | Y1 14.31818 MHz; U39 74ACT14; U40 74F191 |
| Reset | U43 DM1813 |
| VIA, SPI | U2 R65C22; U4 74F138 (SPI device select) |
| Serial | U3 R65C51; U5 MAX232 |
| Sound | U38 YM2151; U41 YM3012; U42 TL074; IC9 LF353 |

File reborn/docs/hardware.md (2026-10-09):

# The Hydra-16: hardware reference

This is the Hydra-16 main board (V1) as its schematic describes it (`board/hydra-16.kicad_sch` and its sheets), with the two companion cards in `board/`, and the Vera X video card that goes in slot 0.  Reference designators (U25, J18, ...) are the schematic's.  How HydraOS uses the hardware is [the guide](hydra-16.md)'s and [the programmer's guide](programming/README.md)'s; the registers' names are `base/include/hw.inc`'s (made from this document).

To test a board, run the hardware test: `hwtest` at the shell, or a `T` typed during POST.  It's the old system's, kept unchanged in paged ROM bank 1 ([its guide](../../old/docs/using/wozmon.md#the-hardware-test)), with the checksums of HydraOS's images.

## Contents
1. [Overview](#overview)
2. [The CPU view: memory map](#the-cpu-view-memory-map)
3. [The pseudo-registers T, U, V, W](#the-pseudo-registers-t-u-v-w)
4. [Task RAM and the bank registers ($00, $01)](#task-ram-and-the-bank-registers)
5. [The paged RAM window ($8000-$9FFF)](#the-paged-ram-window)
6. [The paged ROM ($A000-$DFFF)](#the-paged-rom)
7. [The BIOS ROM ($E000-$FFFF)](#the-bios-rom)
8. [I/O space ($FF00-$FFFF)](#io-space)
9. [Interrupts](#interrupts)
10. [Clocks](#clocks)
11. [Reset, power and bus control](#reset-power-and-bus-control)
12. [On-board devices](#on-board-devices): VIA, ACIA (serial), YM2151 (sound), SPI
13. [Expansion slots](#expansion-slots)
14. [Companion cards](#companion-cards): the memory daughter card, the bus breakout card, the Vera X (slot 0)
15. [Connectors and jumpers](#connectors-and-jumpers)
16. [V1 errata](#v1-errata)
17. [Parts by function](#parts-by-function)
18. [In the emulator](#in-the-emulator)

---

## Overview

The Hydra-16 is a W65C02S computer built for multitasking.  Its address decoding gives each of **16 tasks** its own 32K of RAM, including zero page and the stack, and its own RAM and ROM bank selections.  So switching tasks is a single write to one register, `T`.

| | |
| :-- | :-- |
| **CPU** | WDC W65C02S (U1), 3.58 MHz as built (jumper: 0.89, 1.79, 3.58 or 7.16 MHz) |
| **Task RAM** | 512K (U7, HM628512): 32K at `$0000-$7FFF` for each of 16 tasks |
| **Paged RAM** | Seen through an 8K window at `$8000-$9FFF`.  **Task banks:** up to 15 modules of 2 MB on memory daughter cards; each task sees 16 banks of 8K per module.  **Shared banks:** 2 MB on the board (U25, U27-U29), the same for all tasks: 256 banks of 8K, 16 at a time |
| **Paged ROM** | 4 MB (U30-U37, 8 x SST39SF040), seen in 16K banks at `$A000-$DFFF` |
| **BIOS ROM** | U6, SST39SF010/020/040 (128-512K): 8K pages at `$E000-$FFFF`, selected by `W` |
| **I/O** | 15 ports of 16 bytes at `$FF00-$FFEF`, plus the system port at `$FFF0-$FFFF` |
| **Interrupts** | 16 prioritised IRQ lines, each with its own vector (a 16-entry vector RAM at `$FFFE`) |
| **Devices** | 65C22 VIA (timers, SPI, I2C, GPIO), 65C51 ACIA (RS-232 on a DE-9), YM2151 + YM3012 (stereo FM sound) |
| **Expansion** | 6 slots (62-pin edge connectors, 8-bit bus), 8 SPI device headers, a GPIO/I2C header, memory card connectors |
| **Video** | The Vera X in slot 0 (the X16's VERA: VGA, two layers, sprites, a 16-voice PSG and PCM): [below](#the-vera-x-slot-0) |
| **Power** | ATX-24 supply (+5 V, +3.3 V, +12 V, -12 V) |
| **As built** | 3.58 MHz; three task RAM modules (48 banks of 8K for each task); the Vera X card is there, its carrier card still to be made |

---

## The CPU view: memory map

What the CPU sees at each address, and what selects it:

| Addresses | What | Selected by |
| :--- | :--- | :--- |
| `$0000` | RAM bank register (writes); task RAM (reads) | per task (see below) |
| `$0001` | ROM bank register (writes); task RAM (reads) | per task |
| `$0002-$7FFF` | Task RAM (zero page, stack, program RAM) | `T` |
| `$8000-$9FFF` | Paged RAM: a task bank (`$00-$EF`) or a shared bank (`$F0-$FF`) | `$00`; `T` for task banks, `U` for shared banks |
| `$A000-$DFFF` | Paged ROM, 16K banks | `$01` |
| `$E000-$FEFF` | BIOS ROM | `W` |
| `$FF00-$FFEF` | I/O ports 0-14, 16 bytes each | |
| `$FFF0-$FFF3` | Pseudo-registers `T`, `U`, `V`, `W` | |
| `$FFF4-$FFF9` | Not decoded (reads float) | |
| `$FFFA-$FFFD` | BIOS ROM: the NMI and RESET vectors | `W` |
| `$FFFE-$FFFF` | IRQ/BRK vector RAM (16 entries) | the highest-priority active IRQ, or `V` |

Every task has its own `$0000-$7FFF` and its own `$00`/`$01` values.  All tasks share the I/O space, the shared RAM banks, the ROMs, and the pseudo-registers themselves.

---

## The pseudo-registers T, U, V, W
*(Sheet `FFF_Registers`)*

Four 8-bit registers in the system port.  Each is a 74F573 latch, written with the CPU's write strobe, and read back through a 74F541 buffer.  So a read gives the whole byte last written, all 8 bits.

| Address | Register | Latch / read-back | Bits used by the hardware |
| :--- | :--- | :--- | :--- |
| `$FFF0` | `T`, task | U48 / U49 | T0-T3: which task's RAM (task RAM A15-A18; the modules' task lines) |
| `$FFF1` | `U`, shared macro-page | U50 / U51 | U0-U3: shared RAM A13-A16 |
| `$FFF2` | `V`, vector select | U52 / U53 | V0-V3: the vector RAM index when no IRQ is active.  V4-V7 aren't wired: the software keeps a software interrupt number there |
| `$FFF3` | `W`, BIOS ROM page | U54 / U55 | W0-W5: BIOS ROM A13-A18 (64 pages with an SST39SF040; 16 with the '010) |

The latches have no reset, so they power up random; the reset code sets them.  Nothing on the board resets them when the reset button is pressed.  Bits 4-7 of `T` and `U`, and 6-7 of `W`, are stored but go nowhere.

---

## Task RAM and the bank registers

**Task RAM** is one HM628512 (U7, 512K) on the main board.  CPU A0-A14 go straight to it, CPU A15 is its chip enable (low for `$0000-$7FFF`), and `T0-T3` drive its A15-A18.  So each value of `T` selects a different 32K, and a task switch is a single write to `$FFF0`.  Zero page and the stack page are part of it, so every task has its own zero page and stack.

**A DS1747 in U7** gives the Hydra a clock that keeps the time while it's off.  The DS1747 (the 5 V part; the DS1747W is 3.3 V) is a 512K battery-backed RAM with a clock, pin compatible with the HM628512, in a 600-mil module.  Its clock registers are the chip's top 8 bytes, `$7FFF8-$7FFFF`, so they're **task F's `$7FF8-$7FFF`** (`T0-T3` reach U7's A15-A18 through U48 and U21 in order).  Task F is the console driver's, whose RAM stops below `$7FF8`, so nothing else writes them; the kernel finds the chip at boot and sets the system's clock from it, and `/dev/time` (`date`) sets both ([the tools](using/tools.md#the-system)).  The rest of the chip is task RAM as before, kept while the power's off.  A new DS1747 comes with its battery disconnected until it first gets power, and its oscillator may be stopped: setting the time starts it.

**The bank registers `$00` and `$01`** *(sheet `ZPMirrorRAM`)* are four 74LS219 (16 x 4-bit RAM) chips, addressed by `T0-T3`:

| Register | Chips | Drives |
| :--- | :---- | :----- |
| `$00`: RAM bank | IC1 (bits 0-3), IC2 (bits 4-7) | `RAMB0-7`: which bank is at `$8000-$9FFF` |
| `$01`: ROM bank | IC3 (bits 0-3), IC4 (bits 4-7) | `ROMB0-7`: which paged ROM bank is at `$A000-$DFFF` |

* A write to `$0000` or `$0001` stores the byte in the current task's entry.  The address decoding (U8-U10 on sheet `AddressDecode`) spots a write to `$000x`, and U16 picks the register with A0.
* The write also goes to task RAM as usual, and a **read** of `$00`/`$01` comes from task RAM: the registers themselves are write-only, and task RAM mirrors them.
* The outputs are always enabled, so the bank lines follow `T` at once.  A task switch selects the new task's RAM bank and ROM bank without further writes.
* On V1, bits 2 and 3 of both registers are crossed on their way to the bank lines (see [V1 errata](#v1-errata)).

---

## The paged RAM window
*(`$8000-$9FFF`; sheets `ZPMirrorRAM`, `SharedMem`, `AddressDecode`)*

`$8000-$9FFF` shows one 8K bank.  The **bank ID** is the current task's `$00` value:

| Bank ID | What |
| :--- | :--- |
| `$m0-$mF` (m = `$0-$E`) | Task RAM module m: 16 banks for **each task** (the module's chips also get `T0-T3`) |
| `$F0-$FF` | Shared RAM: 16 banks, the same for every task, from shared macro-page `U` |

* **Module select.** The bank ID's upper nibble (`RAMB4-7`) goes to a 74LS154 (U23), qualified by the window's select (`nBRA_S`, `$8000-$9FFF` in PHI2).  Its outputs `nBRC0-nBRC14` go to the memory card connector (J1), one per module; `nBRC15` selects the shared RAM on the board.
* **Memory card connector.** The lower nibble and `T` are buffered to it by U21 (74F541), as `RAMB_M0-3` and `T_M0-3`, along with the read/write strobes (`RWB_M`, `!RWB_M`).  J2 carries D0-D7, A0-A12 and +5 V.
* **Task RAM modules** are [memory daughter cards](#memory-daughter-card): 4 x HM628512 per card, set to a module number with a jumper.  In a module:
  * `T_M0-3` go to the chips' A13-A16, so each task has its own 16 banks.
  * `RAMB_M0-1` go to A17-A18.
  * `RAMB_M2-3` pick the chip.
  * A module is 2 MB: 16 tasks x 16 banks x 8K.
* **Shared RAM** is four HM628512 on the main board: U25, U27, U28 and U29.
  * `RAMB_M2-3` pick the chip, through a 74F139 (U26) enabled by `nBRC15`.
  * `RAMB_M0-1` go to the chips' A17-A18, and `U0-U3` to A13-A16.
  * So the 16 bank IDs `$F0-$FF` are seen in 16 macro-pages (`U` = 0-F): 256 shared banks of 8K, 2 MB.
  * The software numbers them as **shared bank ID** = `U << 4 | (bank & $0F)`.

| Bank IDs (`$00`) | Shared RAM chip (V1) | Shared bank IDs |
| :--- | :--- | :--- |
| `$F0-$F3` | U25 | `$x0-$x3` for each `U` = x |
| `$F4-$F7` | U28 (V1: bits 2/3 crossed) | `$x4-$x7` |
| `$F8-$FB` | U27 (V1) | `$x8-$xB` |
| `$FC-$FF` | U29 | `$xC-$xF` |

A bank with no chip behind it (a missing module) reads whatever floats on the bus; POST finds the modules that are there (`RAM modules: 03` at boot), and the kernel gives out banks only on those.

HM628512 pins, for tracing a bad line (the POST prints bad lines by number):

| Signal | Pin | Signal | Pin |
| :----- | :-- | :----- | :-- |
| A0-A7 | 12, 11, 10, 9, 8, 7, 6, 5 | D0-D2 | 13, 14, 15 |
| A8, A9, A10, A11, A12 | 27, 26, 23, 25, 4 | D3-D7 | 17, 18, 19, 20, 21 |
| A13-A16 (`U0-U3` on shared RAM) | 28, 3, 31, 2 | ~CE, ~OE, ~WE | 22, 24, 29 |
| A17, A18 (`RAMB_M0`, `RAMB_M1`) | 30, 1 | VCC, GND | 32, 16 |

---

## The paged ROM
*(`$A000-$DFFF`; sheets `BankedROM`, `ZPMirrorRAM`)*

Eight SST39SF040 (512K each, U30-U37) give 4 MB, seen as 256 banks of 16K.  The bank is the current task's `$01` value:

* `ROMB0-4` go to the chips' A14-A18 (32 banks per chip).
* `ROMB5-7` pick the chip through a 74F138 (U24), qualified by the window's select (`nBRO_S`: `$A000-$DFFF` in PHI2):

| `$01` bits 5-7 | Chip | Banks |
| :--- | :--- | :---- |
| 0 | U31 | `$00-$1F` |
| 1 | U32 | `$20-$3F` |
| 2 | U34 | `$40-$5F` |
| 3 | U36 | `$60-$7F` |
| 4 | U30 | `$80-$9F` |
| 5 | U33 | `$A0-$BF` |
| 6 | U35 | `$C0-$DF` |
| 7 | U37 | `$E0-$FF` |

* **The halves are swapped.** CPU A13 goes to the chips' A13 unchanged, but in the window `$A000-$BFFF` has A13 = 1 and `$C000-$DFFF` has A13 = 0.  So CPU `$A000` reads chip offset `$2000` of the bank, and `$C000` reads offset `$0000`.  HydraOS's build writes the chips' view (`base/tools/romimg.js`), a 512K image for each chip it fills: `bin/prom0.bin` for U31 (chip select 0), `prom1.bin` for U32, `prom2.bin` for U34, `prom3.bin` for U36; burn each whole, at offset 0.
* **V1: bits 2 and 3, and 6 and 7, trade places.**  On the V1 board `ROMB2`/`ROMB3` and `ROMB6`/`ROMB7` are swapped on their way to the chips (as are the RAM bank bits; the schematic shows the board as built), so the bank the CPU selects as `b` is the chips' bank `swap(b)`.  Banks whose two bits match (`$00-$03`, `$0C-$0F`, ...) aren't affected.  The build writes the image in the chips' order (`base/tools/romimg.js`), and the emulator reads it that way (`base/sim/lib/machine.js`).
* **`nBROMD`** (a slot pin, pulled up) disables the whole paged ROM when a card pulls it low, so the card can answer `$A000-$DFFF` itself.
* The chips' ~OE is the inverted R/W; there's no write path in circuit (program the chips in a programmer).

---

## The BIOS ROM
*(U6, root sheet)*

An SST39SF0x0 in a 32-pin socket: the '010 (128K, 16 pages), '020 (256K, 32 pages) or '040 (512K, 64 pages).

* CPU A0-A12 go to the chip's A0-A12, and `W0-W5` to its A13-A18: each `W` value selects an 8K page.
* It's selected for `$E000-$FEFF` and for `$FFFA-$FFFD` (the NMI and RESET vectors).  I/O space and the vector RAM take the rest of `$FF00-$FFFF`.
* HydraOS's build makes `bin/bios.bin`, 128K: 16 pages, for the '010.

**Changing `W` changes the code being run.**  The next instruction is fetched from the new page, at the same address.  The software handles this by keeping identical code at the same address on every page: the COMMON block at `$FD00` (the IRQ entry and exit, the kernel's far call), and the reset stub at `$E000` (`base/kernel/bios.cfg`; [the kernel's pages](conventions.md#the-kernels-pages)).  Because `W` isn't reset, **every page must start with the reset code**: the RESET vector on every page points to `$E000`, which sets `W` to 0.

---

## I/O space
*(Sheet `AddressDecode`)*

`$FF00-$FFFF` is decoded when A8-A15 are all 1 (U14, a 74F30), qualified by PHI2 (`nIO_S`).  A 74LS154 (U19) splits it by A4-A7 into 16 ports of 16 bytes, `nIOP0_S-nIOP15_S`.  Ports 0-14 are for devices; port 15 is the system port.

| Port | Addresses | Use |
| :--- | :--- | :-- |
| 0 | `$FF00-$FF0F` | VIA (65C22, U2) |
| 1 | `$FF10-$FF1F` | ACIA (65C51, U3): 4 registers, repeated every 4 bytes |
| 2 | `$FF20-$FF2F` | Slot 0, select A (intended for video) |
| 3 | `$FF30-$FF3F` | Slot 0, select B (intended for video) |
| 4 | `$FF40-$FF4F` | YM2151 (U38): `$FF40` address/status, `$FF41` data (repeated) |
| 5-9 | `$FF50-$FF9F` | Slots 1-5, select A |
| 10-14 | `$FFA0-$FFEF` | Slots 1-5, select B |
| 15 | `$FFF0-$FFFF` | System port (below) |

**The system port** is decoded by a 74F138 (U20) on A0-A2, enabled by `nIOP15_S` and by A3 differing from A2 (U12):

| Address | Select | Use |
| :--- | :----- | :-- |
| `$FFF0-$FFF3` | `nIOB0-3` | `T`, `U`, `V`, `W` |
| `$FFF4-$FFF9` | none | Not decoded (reads float; reserved) |
| `$FFFA-$FFFD` | (BIOS ROM) | NMI and RESET vectors, from the current BIOS ROM page |
| `$FFFE`, `$FFFF` | `nIOB14`, `nIOB15` | The vector RAM, low and high bytes |

Slot port selects (`nIOA_S`, `nIOB_S` on each slot) and each slot's two IRQ lines follow the same numbering: see [Expansion slots](#expansion-slots).  A card can also decode its own addresses from the whole I/O space with `nIO_S` and A0-A7.

---

## Interrupts
*(Sheet `IRQ_Priorty_Encoder`)*

Sixteen active-low IRQ lines, `nIRQ0-nIRQ15`, each pulled up (RN2, RN3).  Line 0 has the highest priority.

| Line | Source | Line | Source |
| ---: | :----- | ---: | :----- |
| 0 | VIA | 8 | Slot 4, A |
| 1 | ACIA | 9 | Slot 5, A |
| 2 | Slot 0, A | 10 | Slot 1, B |
| 3 | Slot 0, B | 11 | Slot 2, B |
| 4 | YM2151 | 12 | Slot 3, B |
| 5 | Slot 1, A | 13 | Slot 4, B |
| 6 | Slot 2, A | 14 | Slot 5, B |
| 7 | Slot 3, A | 15 | Not connected: used for software interrupts |

**How it works:**
* Two cascaded 74LS148 priority encoders (U17 for lines 0-7, U18 for 8-15) find the highest-priority active line.
* Any active line asserts the CPU's ~IRQ (U44, then U22).  The IRQ input is level-triggered: a device holds its line until the handler clears it.
* A 74F157 (U45) forms a 4-bit index `q0-q3`:
  * while any IRQ line is active, the index is the encoder's output;
  * otherwise it's `V0-V3`.
* The index addresses the **vector RAM**, four 74LS219 (IC5-IC8), a 16-entry table of 16-bit vectors.  The CPU reads its IRQ/BRK vector from `$FFFE/$FFFF`, so it gets the entry for the active line, and each line has its own handler.

**The index is the line number XOR 7.**  The '148s encode active-low inputs with the highest-priority input as 7, so line n gives index `n ^ 7`: line 0 is entry 7, line 7 entry 0, line 8 entry 15, line 15 entry 8.  `base/include/hw.inc`'s `IRQ_INDEX(line)` is `line ^ 7` for this reason.

**Writing vectors.**  A write to `$FFFE` / `$FFFF` stores the low / high byte of entry `q`.  That's `V0-V3` when no IRQ line is active.  So set `V` to the entry wanted, then write the vector, with no IRQ pending.  HydraOS's boot does this once, with interrupts off (`base/kernel/reset.s`): every line's entry is the kernel's one IRQ path.

**BRK.**  `BRK` also reads `$FFFE/$FFFF`.  With no IRQ line active, that's entry `V0-V3`.  HydraOS sets `V` to line 15's entry (`IRQ_INDEX(15)`: line 15 has no hardware) as it starts and leaves it, so a `BRK` comes to the kernel by that vector: a program's stray `BRK` is a note to it, and the debugger's breakpoints are `BRK`s.

**NMI** (`NMIB`, pulled up, on every slot) uses the ROM's `$FFFA` vector.  Nothing on the board drives it.

---

## Clocks
*(Sheet `Clocks`)*

A 14.31818 MHz crystal (Y1) with a 74ACT14 (U39) oscillator, divided by a 74F191 counter (U40):

| Clock | Frequency | Goes to |
| :---- | :--- | :--- |
| `HS_CLK` | 14.318 MHz | Slots (e.g. for video) |
| Q0 | 7.159 MHz | CPU clock jumper J8 |
| `SND_CLK` (Q1) | 3.580 MHz | YM2151 master clock; slots; CPU clock jumper J7 |
| `SER_CLK` (Q2) | 1.790 MHz | ACIA clock (XTAL1); slots; CPU clock jumper J6 |
| Q3 | 0.895 MHz | CPU clock jumper J5 |

**The CPU clock** (`PHI2`) is whichever of J5-J8 is fitted: fit exactly one.  As built, it's **J7, 3.58 MHz**.  The CPU's PHI0 input is `PHI2` gated by `DMAB` (U11), so a card asserting `DMAB` stops the CPU clock (the W65C02S is fully static).  `PHI1` (inverted `PHI2`) qualifies the address decoding.

HydraOS's timing (the tick, the serial port's pacing, sound) is built for one clock: `node build.js --clock 2` builds for 7.16 MHz (J8), the default for 3.58 MHz.  At 7.16 MHz the YM2151 is too slow for the bus: there are no wait states on V1, so don't use the sound chip at that speed.  The 0.89 and 1.79 MHz settings aren't supported.

---

## Reset, power and bus control

**Power** comes from an ATX-24 connector (J11):
* +5 V for the logic, +3.3 V, and ±12 V for the audio op-amps and the slots.
* +5 V standby is brought out as `+5VA`.
* The slots also have a -5 V pin, which the board doesn't supply: ATX no longer has -5 V.

**Front panel** (J10, 2x6):

| Pin | Signal |
| :-- | :----- |
| 7 | `RESB`: a push button from here to ground (pins 5, 6, 9 or 10) resets the machine |
| 8 | +5 V |
| 11 | ATX `PS_ON#`: connect to ground (a latching switch) to turn the supply on |
| 12 | Power LED: from the supply's `PWR_OK`, through R2 (470 Ω) |
| 5, 6, 9, 10 | Ground |
| 1-4 | Not connected |

**Reset** (`RESB`):
* A DM1813 supervisor (U43) holds reset low at power-up and during brown-outs.
* The front panel button and the slots (open-collector) can pull it low too.
* It resets the CPU, VIA, ACIA, YM2151 and YM3012.  It doesn't reset the pseudo-registers, the bank registers or RAM.

**Bus control:**
* **`RDY`:** pulled up through jumper **J4**, which must be fitted.  The W65C02S drives RDY low itself during `WAI`, so RDY must never be driven high directly.
* **`BE`** (bus enable): pulled up, and on the slots.
* **DMA:** a card pulls **`DMAB`** low to take the bus.
  * It stops the CPU clock, and turns off the address buffers (U58, U60, 74F541), the data transceiver (U59, 74F245) and the R/W buffer (U61, 74F125).
  * The card then drives the address and data buses itself.
* **`SYNC`** from the CPU is on the slots, for single-stepping or debugging hardware.
* `MLB`, `VPB` are unused.  `SOB` is tied high.

---

## On-board devices

### VIA (65C22, U2): port 0, IRQ line 0
*(Registers at `$FF00-$FF0F`.)*

**Port A** is general purpose I/O, on header **J27** (2x6), with ESD protection (J28, SP720):

| J27 pin | Signal | J27 pin | Signal |
| :--- | :----- | :--- | :----- |
| 1 | GND | 2 | +5 V |
| 3 | PA0: `I2C_SCL` | 4 | PA1: `I2C_SDA` |
| 5 | PA2 | 6 | PA3 |
| 7 | PA4 | 8 | PA5 |
| 9 | PA6 | 10 | PA7 |
| 11 | CA1 | 12 | CA2 |

* PA0/PA1 are the I2C bus (bit-banged; the SDA and SCL pull-ups are in RN1), which also goes to every slot.  HydraOS's GPIO driver serves it: `/dev/i2c` (its `ctl`, and a file each device).
* **The pins, CA1 and CA2 are files:** `/dev/gpio` (`0`-`7`, `port`, `ctl`, `ca1`: [the devices](programming/files.md#devices)); CA1 can interrupt (IRQ line 0, `/dev/gpio/ca1`).
* **Port B is the SPI bus** (below).
* **Timer 1** is the scheduler's tick: free-running, 200 interrupts a second.
* **Timer 2** paces the serial port's sending (the console driver's, at every rate, on either ACIA).
* CB1/CB2 aren't brought out.

### ACIA (65C51, U3): port 1, IRQ line 1
*(Registers at `$FF10-$FF13`.)*

**Chip and clock:**
* The board has a Rockwell R65C51 socket.  A WDC W65C51N works if HydraOS is built for it (`node build.js --acia wdc`): its transmitter status and interrupt don't work, and the console driver paces sending with VIA timer 2 on either chip.
* **The ACIA's clock is `SER_CLK`, 1.790 MHz**, not the 1.8432 MHz its baud rate table is made for.  So every rate is 2.9% slow (9600 gives about 9,320 baud), which terminals and USB serial adapters accept.
* DCD and DSR are tied active.

**Serial settings:** 9600 baud, 8 data bits, no parity, 1 stop bit at boot, with RTS/CTS.  `/dev/serctl` changes the rate: `b300`, `b600`, `b1200`, `b2400`, `b4800`, `b9600`, `b19200`, `b115200` (the ACIA clock / 16): `echo b115200 >/dev/serctl`.

**Sending is paced.**  Sent back to back at 115200, long output loses and garbles characters on the board (the old system found it: a WOZMON dump): the rate is 2.9% slow and the MAX232 is near its limit, so the receiver has little margin.  A second stop bit helps but isn't enough.  So HydraOS's console driver sends each byte from VIA timer 2, not the ACIA's TDRE interrupt: a character's time and two idle bits at 115200, one at the other rates.

**The DE-9 connector** (J3, male) is driven by a MAX232 (U5), and wired like a modem (DCE):

| DE-9 pin | Signal | Direction |
| :--- | :----- | :--- |
| 2 | Hydra transmits (ACIA TxD) | out |
| 3 | Hydra receives (ACIA RxD) | in |
| 5 | Ground | |
| 7 | ACIA ~CTS (from the terminal's RTS) | in |
| 8 | ACIA ~RTS (to the terminal's CTS) | out |

**Cable:** a PC or USB serial adapter connects with a **straight-through** cable with two female ends, not a null-modem cable.  The ACIA only transmits while its ~CTS is asserted, so the cable must carry pin 7.  Terminal programs assert RTS by default.

### YM2151 sound (U38): port 4, IRQ line 4
*(Sheet `Sound`.)*

**The chip:**
* A Yamaha YM2151 (OPM, 8 FM channels), clocked by `SND_CLK` (3.58 MHz).
* `$FF40` selects a register (and reads the status: bit 7 = busy), and `$FF41` writes it.
* After a data write the chip is busy for 64 of its clocks (about 18 µs); writes while it's busy are lost.
* **CT1/CT2**, its two general-purpose outputs, are on header J9.
* **Timer B on the board:** re-armed every song tick (its flag reset through `$14`, which on the board seems to restart it), it didn't keep its period: songs timed by it ran up to twice as fast, by a different amount each run.  So the song player times songs by the system's tick (the VIA's timer 1) instead; the hardware test's timer checks (one period from a clean start) pass.

**The audio path:**
* A YM3012 DAC (U41) converts its serial output, buffered and filtered by a TL074 (U42).
* A mixer (IC9, LF353, ±12 V) adds, for each channel:
  * the YM3012's output;
  * each slot's audio lines (`SND_CL0-5`, `SND_CR0-5`), so a sound card in a slot is mixed in;
  * a line input on header J29.
* **Output:** stereo, on the 3.5 mm jack J26.  The schematic has the tip on the right channel and the ring on the left, the reverse of the usual convention (see [V1 errata](#v1-errata)).

### SPI bus (VIA port B)
SPI is bit-banged on the VIA's port B (the VIA's shift register uses CB1/CB2, which aren't brought out, so it can't drive these lines); a 74F138 (U4) decodes the device select:

| Port B bit | Signal |
| :--- | :----- |
| PB0 | `SPI_CLK` (SCLK) |
| PB1 | `nSPI_CS`: low selects the device given by PB3-PB6 |
| PB2 | `SPI_MOSI` |
| PB3-PB5 | `SPI_A0-A2`: device 0-7 |
| PB6 | `SPI_A3`: 0 = the board's devices 0-7 (U4); 1 = devices 8-15, for cards to decode (the slots carry `nSPI_CS` and `SPI_A0-A3`) |
| PB7 | `SPI_MISO` |

**The eight SPI device headers** are J18-J25, for devices 0-7.  Each is a 1x6 header:

| Pin | Signal |
| :-- | :----- |
| 1 | ~CS |
| 2 | SCLK |
| 3 | MOSI |
| 4 | MISO |
| 5 | +5 V |
| 6 | GND |

HydraOS's storage driver runs SPI in mode 0 for SD cards, and serves an SD card on any device (`/dev/sd/N`, N the device in hex; its file system at `/sd/N`); device 0 (J18) is the usual place for an SD card adapter.  Any device is a file too, `/dev/spi/N` (a write and a read are a transaction; modes 0 and 3: [the devices](programming/files.md#devices)).  The headers supply +5 V, so the adapter must regulate and level-shift to 3.3 V for the card (common SD card modules do).

---

## Expansion slots
*(Sheet `Connectors`: J12-J17, "Hydra bus 8-bit", 62-pin card edge.)*

Six slots, all carrying the same bus except for each slot's two port selects, two IRQ lines and its audio pair:

| Slot | Connector | `nIOA_S` (pin 51) | `nIOB_S` (pin 49) | `IRQA` (pin 55) | `IRQB` (pin 53) | Audio (`SND_CL/CR`) |
| :--- | :--- | :--- | :--- | :--- | :--- | :--- |
| 0 | J12 | port 2 `$FF20` | port 3 `$FF30` | line 2 | line 3 | pair 0 |
| 1 | J13 | port 5 `$FF50` | port 10 `$FFA0` | line 5 | line 10 | pair 1 |
| 2 | J14 | port 6 `$FF60` | port 11 `$FFB0` | line 6 | line 11 | pair 2 |
| 3 | J15 | port 7 `$FF70` | port 12 `$FFC0` | line 7 | line 12 | pair 3 |
| 4 | J16 | port 8 `$FF80` | port 13 `$FFD0` | line 8 | line 13 | pair 4 |
| 5 | J17 | port 9 `$FF90` | port 14 `$FFE0` | line 9 | line 14 | pair 5 |

Slot 0's A lines (port 2, IRQ 2) have the highest priority of the slots; the B lines of slots 1-5 the lowest.

**Pinout** (the same on every slot; `~` = active low):

| Pin | Signal | Pin | Signal |
| :-- | :----- | :-- | :----- |
| 1 | GND | 2 | ~`nBROMD` (disable the paged ROM) |
| 3 | ~`RESB` | 4 | D7 |
| 5 | +5 V | 6 | D6 |
| 7 | ~`NMIB` | 8 | D5 |
| 9 | -5 V (not supplied) | 10 | D4 |
| 11 | `BE` | 12 | D3 |
| 13 | -12 V | 14 | D2 |
| 15 | `SER_CLK` (1.79 MHz) | 16 | D1 |
| 17 | +12 V | 18 | D0 |
| 19 | GND | 20 | `RDY` |
| 21 | R/~W | 22 | `SND_CLK` (3.58 MHz) |
| 23 | ~`DMAB` | 24 | `SND_CR` (audio in, right) |
| 25 | ~`nIO_S` (any I/O port) | 26 | `SND_CL` (audio in, left) |
| 27 | `SYNC` | 28 | `I2C_SDA` |
| 29 | `SPI_SCLK` | 30 | `I2C_SCL` |
| 31 | `SPI_MOSI` | 32 | A15 |
| 33 | `SPI_MISO` | 34 | A14 |
| 35 | ~`nSPI_CS` | 36 | A13 |
| 37 | `PHI1` | 38 | A12 |
| 39 | `PHI2` | 40 | A11 |
| 41 | `SPI_A3` | 42 | A10 |
| 43 | `SPI_A2` | 44 | A9 |
| 45 | `SPI_A1` | 46 | A8 |
| 47 | `SPI_A0` | 48 | A7 |
| 49 | ~`nIOB_S` | 50 | A6 |
| 51 | ~`nIOA_S` | 52 | A5 |
| 53 | ~`IRQB` | 54 | A4 |
| 55 | ~`IRQA` | 56 | A3 |
| 57 | +5 V | 58 | A2 |
| 59 | `HS_CLK` (14.318 MHz) | 60 | A1 |
| 61 | GND | 62 | A0 |

A card's IRQ outputs should be open-collector: the board pulls each line up.  The address and data buses are buffered on the board; a DMA card drives them after asserting ~`DMAB`.

---

## Companion cards

### Memory daughter card
*(`board/MemoryDaughterCard`: through-hole and surface-mount versions.)*

One task RAM module: 4 x HM628512, 2 MB.

* **Connectors:** it plugs into the main board's memory connectors J1 (1x32) and J2 (1x24).
* **Module number:** a 2x15 jumper block (J3) connects the card's select to one of `nBRC0-nBRC14`.  That's its module number m, so it answers bank IDs `$m0-$mF`.
* **Addressing:**
  * a 74LS139 (U1) picks one of the four chips with `RAMB_M2-3`;
  * `RAMB_M0-1` go to the chips' A17-A18, and `T_M0-3` to A13-A16;
  * A0-A12 come from J2.

Main board J1 (memory card connector):

| Pins | Signals |
| :--- | :--- |
| 1-3 | A13, A14, A15 (the card doesn't use them) |
| 5-8 | `T_M0-3` |
| 9-12 | `RAMB_M0-3` |
| 13, 14 | `RWB_M`, `!RWB_M` |
| 15-17 | GND |
| 18-32 | `nBRC0_S-nBRC14_S` (module selects) |

J2: D0-D7 (pins 1-8), +5 V (9-11), A0-A12 (12-24).

POST finds the installed modules and tests each one (`RAM modules: 03`), and the kernel gives out banks only on modules that are present.

### Bus breakout card
*(`board/HydraBusBreakoutCard`.)*  A slot card that brings every bus signal out to headers, for a logic analyzer, a scope or prototyping:

| Header | Signals |
| :----- | :--- |
| J2 | Data bus |
| J3 | Address bus |
| J4 | SPI (A0-A3, ~CS, MISO, MOSI, SCLK) |
| J5 | NMI, `nIO_S`, the slot's port selects and IRQs |
| J6 | Clocks |
| J7 | Bus control (`nBROMD`, BE, RDY, R/W, SYNC) |
| J8 | Reset |
| J9 | Audio |
| J10 | I2C |
| J11 | Power |

Two of its labels are wrong: the card's connector symbol and the main board's slot disagree, and the slot carries what
the main board's says.  **J11 pin 3, "+5VA", is -5 V** (slot pin 9), and **J7 pin 5, "!RWB", is `/DMAB`** (slot pin
23), not an inverted R/W.  Wiring the Vera X through it: [vera-wiring.md](vera-wiring.md).
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

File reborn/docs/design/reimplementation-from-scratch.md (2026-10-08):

## **Reimplementing the Hydra-16's software from scratch**

An evaluation of the Hydra-16's current software, and a step-by-step plan for building it again from the ground up, so that it ends at the same place (a 16-task, Plan 9-style computer with files, namespaces, pipes, a shell, storage, sound and, later, video) with a design that is consistent, easy to follow and easy to program for.

**Status:** a plan, written in October 2026 against branch `1.8C_0.6` (OS `1.8C_0.6`).  Nothing in the current tree is changed by it.

**Scope:**
* **Hardware:** the V1 board as built, errata included ([../hardware.md](../hardware.md#v1-errata)).  Changes that a V2 board could make to simplify the software are in [Appendix G](#appendix-g-v2-hardware-wishes).  The board and its schematics are a fixed reference here.
* **Replaced:** everything in `os_rom/` (the kernel, drivers, servers, the shell, HyForth, WOZMON, the self tests) and the program SDKs in `programs/`.
* **Kept, and built on:** the emulator, the regression test harness and the PC tools in `sim/`, the hardware test, the HydraFS on-disk format (so existing cards keep working), the ROM disk idea, the song tools and the ZSM format, and the `/pc` idea.
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

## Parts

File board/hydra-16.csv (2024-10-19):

Id | Designator | Footprint | Quantity | Designation | Supplier and ref
1 | J15 | Jack_3.5mm_CUI_SJ1-3523N_Horizontal | 1 | AudioJack3
2 | U20,U21,U22,U19 | DIP-32_W15.24mm_Socket_LongPads | 4 | HM628512LP-5
3 | U49,U47,U1 | DIP-20_W7.62mm_Socket_LongPads | 3 | 74F573
4 | IC2,IC1,IC3,IC4 | DIP-16_W7.62mm_Socket_LongPads | 4 | 74LS189
5 | C61,C60 | C_Disc_D5.0mm_W2.5mm_P2.50mm | 2 | 332
6 | U4 | DIP-40_W15.24mm_Socket_LongPads | 1 | W65C02S
7 | U51,U46,U14 | DIP-14_W7.62mm_Socket_LongPads | 3 | 74F32
8 | U34,U30,U29,U35,U31,U28,U33,U32 | DIP-32_W15.24mm_Socket_LongPads | 8 | AT29C040
9 | J21 | PinSocket_1x06_P2.54mm_Vertical | 1 | SPI Device 4
10 | U36 | DIP-14_W7.62mm_Socket_LongPads | 1 | 74ACT14
11 | J9 | TE_7-5530843-0 | 1 | SLOT 0
12 | U6 | DIP-28_W15.24mm_Socket_LongPads | 1 | 65C51
13 | C50,C24,C20,C38,C58,C18,C9,C19,C41,C39,C30,C25,C62,C29,C56,C42,C46,C53,C54,C34,C16,C13,C15,C7,C10,C63,C55,C12,C66,C33,C23,C21,C31,C14,C26,C52,C65,C51,C47,C43,C22,C6,C36,C27,C8,C32,C35,C64,C28,C17,C11,C57,C37 | C_Disc_D5.0mm_W2.5mm_P5.00mm | 53 | 104
14 | U23 | DIP-16_W7.62mm_Socket_LongPads | 1 | 74F139
15 | J18 | PinSocket_1x06_P2.54mm_Vertical | 1 | SPI Device 1
16 | C48,C68,C49,C69,C67 | CP_Radial_D6.3mm_P2.50mm | 5 | 107
17 | U24 | DIP-14_W7.62mm_Socket_LongPads | 1 | 74F20
18 | R1 | R_Axial_DIN0204_L3.6mm_D1.6mm_P5.08mm_Horizontal | 1 | 105
19 | J3 | DSUB-9_Male_Horizontal_P2.77x2.54mm_EdgePinOffset9.40mm | 1 | DE9_Plug
20 | IC5,IC8,IC6,IC7 | DIP-16_W7.62mm_Socket_LongPads | 4 | 74LS219
21 | U39 | DIP-24_W15.24mm_Socket_LongPads | 1 | YM2151
22 | J7 | PinHeader_2x01_P2.54mm_Vertical | 1 | 1.78977MHz
23 | U25,U16 | DIP-14_W7.62mm_Socket_LongPads | 2 | 74LS260
24 | RN2,RN3,RN1 | R_Array_SIP9 | 3 | 332
25 | U48,U2,U50 | DIP-20_W7.62mm_Socket_LongPads | 3 | 74F541
26 | J13 | TE_7-5530843-0 | 1 | SLOT 4
27 | J16 | PinSocket_1x06_P2.54mm_Vertical | 1 | SPI Device 0
28 | U17,U10,U26 | DIP-24_W15.24mm_Socket_LongPads | 3 | 74LS154
29 | J8 | PinHeader_2x01_P2.54mm_Vertical | 1 | 3.57955MHz
30 | U41 | TO-92_Inline_Wide | 1 | DM1813-10
31 | U11 | DIP-14_W7.62mm_Socket_LongPads | 1 | 74F00
32 | U40 | DIP-16_W7.62mm_Socket_LongPads | 1 | YM3012
33 | U18 | DIP-14_W7.62mm_Socket_LongPads | 1 | 74F02
34 | J4 | PinHeader_2x01_P2.54mm_Vertical | 1 | 7.15909MHz
35 | U9,U27 | DIP-16_W7.62mm_Socket_LongPads | 2 | 74F138
36 | U8 | DIP-32_W15.24mm_Socket_LongPads | 1 | Task RAM
37 | J11 | TE_7-5530843-0 | 1 | SLOT 2
38 | J1 | PinSocket_1x32_P2.54mm_Vertical | 1 | Conn_01x32
39 | U12 | DIP-14_W7.62mm_Socket_LongPads | 1 | 74F86
40 | Y1 | Crystal_HC18-U_Vertical | 1 | 14.31818MHz
41 | C3,C2,C1,C4,C5 | C_Disc_D5.0mm_W2.5mm_P2.50mm | 5 | 105
42 | U3 | DIP-28_W15.24mm_Socket_LongPads | 1 | AT28C64B
43 | U15 | DIP-14_W7.62mm_Socket_LongPads | 1 | 74F30
44 | U38 | CERDIP-14_W7.62mm_SideBrazed_LongPads_Socket | 1 | TL074
45 | J10 | TE_7-5530843-0 | 1 | SLOT 1
46 | U7 | DIP-16_W7.62mm_Socket_LongPads | 1 | MAX232
47 | J14 | TE_7-5530843-0 | 1 | SLOT 5
48 | J12 | TE_7-5530843-0 | 1 | SLOT 3
49 | J22 | PinSocket_1x06_P2.54mm_Vertical | 1 | SPI Device 5
50 | C40 | C_Disc_D4.3mm_W1.9mm_P5.00mm | 1 | 104
51 | J25 | PinHeader_2x06_P2.54mm_Vertical | 1 | VIA Port A
52 | J19 | PinSocket_1x06_P2.54mm_Vertical | 1 | SPI Device 2
53 | J24 | PinSocket_1x06_P2.54mm_Vertical | 1 | SPI Device 7
54 | U42,U43 | DIP-16_W7.62mm_Socket_LongPads | 2 | 74F157
55 | R2 | R_Axial_DIN0204_L3.6mm_D1.6mm_P5.08mm_Horizontal | 1 | 471
56 | J20 | PinSocket_1x06_P2.54mm_Vertical | 1 | SPI Device 3
57 | U5 | DIP-40_W15.24mm_Socket_LongPads | 1 | 65C22
58 | U13 | DIP-14_W7.62mm_Socket_LongPads | 1 | 74F08
59 | U37 | DIP-16_W7.62mm_Socket_LongPads | 1 | 74F191
60 | R3 | R_Axial_DIN0204_L3.6mm_D1.6mm_P5.08mm_Horizontal | 1 | 101
61 | J26 | DIP-16_W7.62mm_Socket_LongPads | 1 | SP720APP
62 | C45,C44 | C_Disc_D5.0mm_W2.5mm_P2.50mm | 2 | 330
63 | J23 | PinSocket_1x06_P2.54mm_Vertical | 1 | SPI Device 6
64 | J2 | PinSocket_1x24_P2.54mm_Vertical | 1 | Conn_01x24
65 | J5 | Molex_Mini-Fit_Jr_5566-24A2_2x12_P4.20mm_Vertical | 1 | ATX-24
66 | J6 | PinHeader_2x01_P2.54mm_Vertical | 1 | 0.89489MHz
67 | U44,U45 | DIP-16_W7.62mm_Socket_LongPads | 2 | 74LS148
68 | J17 | PinHeader_2x06_P2.54mm_Vertical | 1 | Front Panel

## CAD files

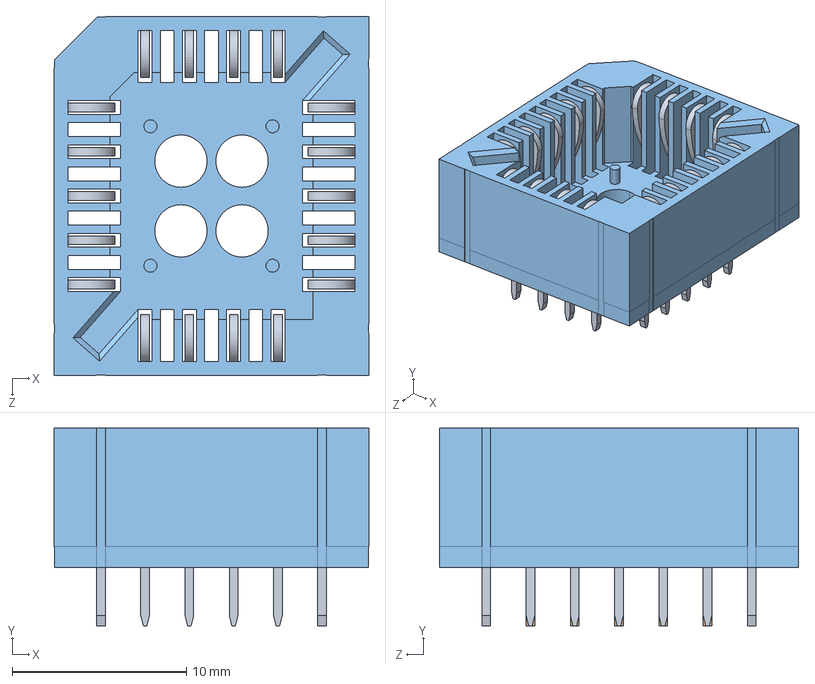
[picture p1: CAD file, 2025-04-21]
board/res/ACCS032ZT.STEP
18.1 x 11.4 x 20.6 mm

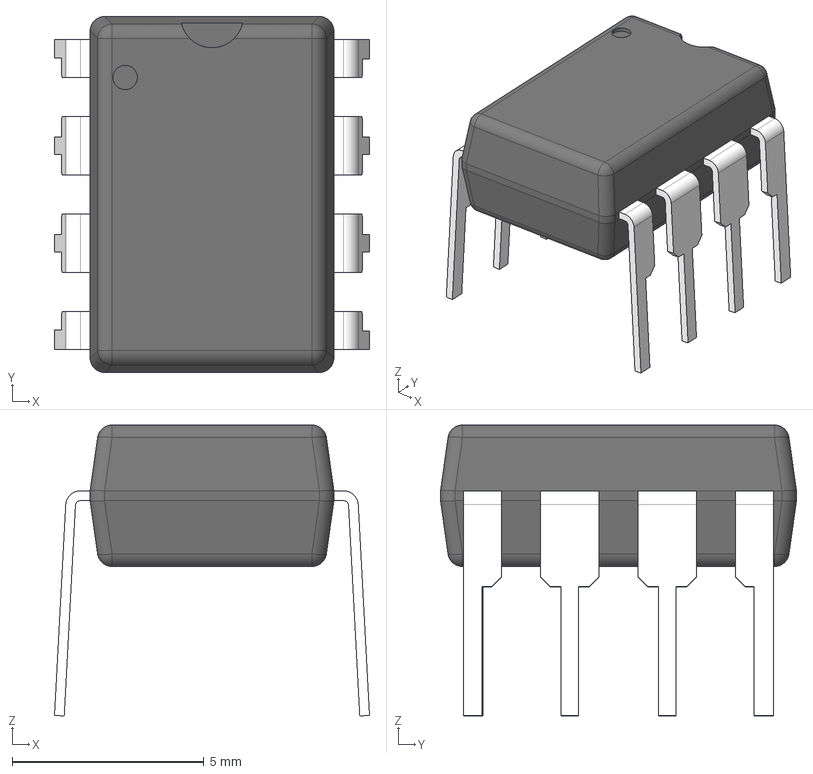
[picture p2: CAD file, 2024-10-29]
board/res/LF353P.stp
8.20 x 9.27 x 7.58 mm
BODY_P0008A
LEAD_P0008A x 4
LD_LHALF_P0008A x 2
LD_RHALF_P0008A x 2

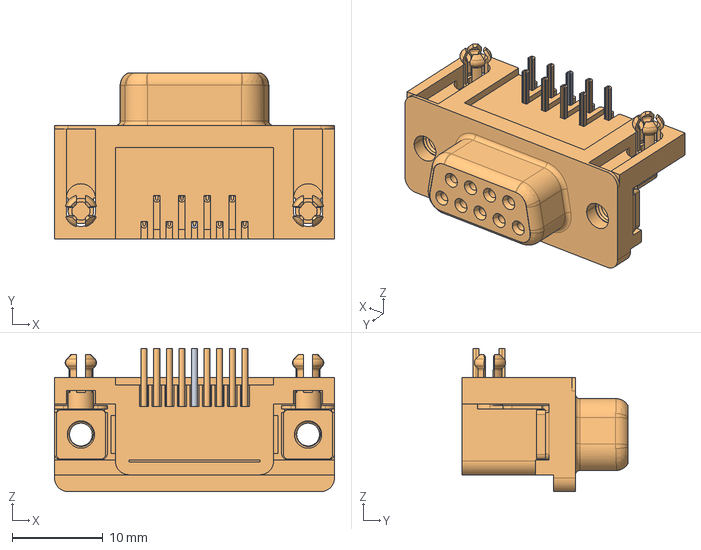
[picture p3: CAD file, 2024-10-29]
board/res/L77SDE09SA4CH3R.stp
30.8 x 18.3 x 15.8 mm

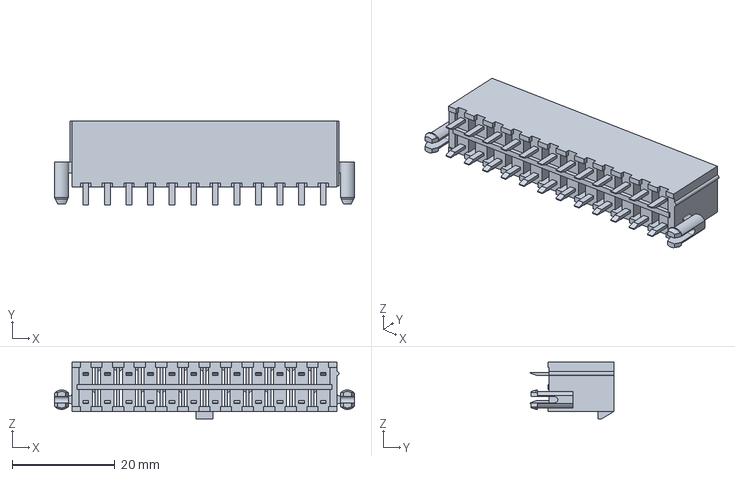
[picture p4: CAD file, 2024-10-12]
board/res/ATX-PCB-Power-vert-with-pegs.stp
58.4 x 16.3 x 11.0 mm

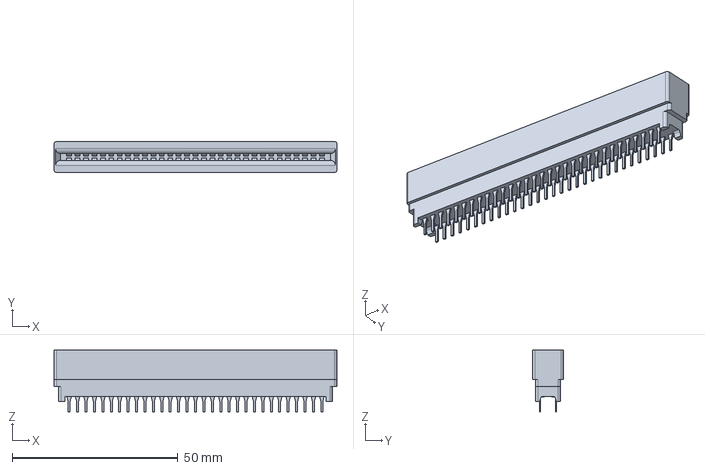
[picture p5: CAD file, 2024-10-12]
board/res/8Bit-ISA-Bus-Socket.step
85.3 x 9.35 x 18.7 mm

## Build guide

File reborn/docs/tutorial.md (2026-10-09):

# First steps with the Hydra-16

A tutorial for a first hour with HydraOS: switching it on, the shell, files and disks, tasks and windows, the
languages, sound, and a program of your own in assembly and in C.  It needs no board: the emulator runs
the same ROM images the board does, and everything here works the same on one.

You need [Node.js](https://nodejs.org) (18 or later) and a clone of the repository; for the programs at the end,
[cc65](https://cc65.github.io/) too (the build looks in `$CC65_BIN`, `$CC65_HOME/bin`, then the PATH).

## 1. Switch it on

From `reborn/` in the repository:

```
node build.js
node sim/run.js -i
```

The first builds the BIOS ROM and the paged ROM's chips (`bin/`); the second boots them in the emulator, its
terminal the Hydra's serial console, in real time.  (On the board, the same images go into the BIOS ROM's socket and
the paged ROM's, and a terminal at 9600 baud is the console.)  The boot shows POST, the drivers starting, and then
the shell's prompt:

```
Hydra-16: kernel 0.1, ABI 1
POST ZP:0 ST:0 OS:0 HI:0 SH:S W:0
...
task 1: init
HydraOS 1.0 for the Hydra-16
init: up in task 01
...
HyForth (Forth 2012), bye to end
/>
```

The prompt is the current directory and `>`.  In the emulator, Ctrl-A x quits, Ctrl-A r presses the reset button,
and Ctrl-A h lists the rest.  `node sim/run.js -i --vera --view` gives it a Vera X card too: its screen, which shows
the console as the terminal does, is at http://localhost:8016.

Or with no terminal at all: `node sim/web.js` makes `obj/web/hydra-16.html`, the emulator as one web page (the page,
the emulator and the ROM images in one file).  Open it in a browser: the serial console is a terminal in the page,
with the Vera X's screen beside it, a Sound button, and SD cards kept in the browser (its Setup).

## 2. The shell

The login shell is HyForth over rc: a line whose first word is a Forth word or a number is Forth; any other line is
an rc command line, run by rc.  So both of these work at the same prompt:

```
/> 2 3 + .
5
/> : sq dup * ;
/> 7 sq .
49
/> echo hello | wc
      1       1       6
```

The console edits the line as you type: Backspace, the arrows, Home and End, Ctrl-U, and Up and Down for the lines
before.  Ctrl-C stops what's running.

## 3. Files

Everything is a file in one tree of names.  `ls /` shows its top:

```
/> ls /
bin/
dev/
env/
lib/
mnt/
pc/
proc/
ram/
rom/
sd/
sram/
tmp/
/> cd /rom
/rom> ls
README
bench/
bin/
doc/
lib/
sample/
songs/
/rom> cat README
The Hydra-16's ROM disk
...
```

`/rom` is the ROM disk, read only, there with no card.  `/ram` is your own area of the RAM disk (each shell has
one), `/sram` the shared RAM disk, `/sd/0` the card in SD device 0, `/dev` the devices, `/proc` the tasks.  `cd`
alone goes back to `/`.

Make a file with `edit`, the screen editor: `edit /ram/todo`, then type its lines (Enter after each), Ctrl-O and
Enter to save it, Ctrl-X to leave.  The two lines at the bottom name the other keys (`^K` cut, `^U` paste, `^W`
find ...), and Ctrl-G shows them all ([using/tools.md](using/tools.md#the-screen-editor)).  `ed` is the line
editor, ed's way.

```
/> edit /ram/todo
/> cat /ram/todo
buy a card
fix the clock
```

Redirection and pipes are rc's: `echo hi >/ram/f`, `cat /ram/f | wc -c`, `ls /rom/bin | sort -r`.  The tools are
[using/tools.md](using/tools.md).

## 4. A card

In the emulator, a card is an image file.  `sim/tools/hydrafs.js` makes one and puts files on it:

```
node sim/tools/hydrafs.js mkfs card.img 8 MYCARD
node sim/run.js -i --sd card.img
```

The card is `/sd/0`; what's written there is in `card.img`, which `hydrafs.js ls card.img` lists:

```
/> echo a note >/sd/0/note.txt
/> ls -l /sd/0
--rw-rw-rw- f0        7 2000-01-01 00:00 note.txt
```

A card's `bin` and `lib` join `/bin` and `/lib`, so programs and libraries on it run by name.  `df` shows the
disks, `mkfs`, `fsck` and `label` work on them.  The clock starts at 2000-01-01 with no DS1747; `date` shows it,
and `echo 2026-10-06 12:00:00 >/dev/time` sets it.

## 5. Tasks and windows

Each program runs in a task of its own (16 in all).  `ps` lists them; `&` runs one in the background:

```
/> sleep 100 &
/> ps
task  state   parent     cpu group  name
   0  ready   -         10.1     0  kernel
   1  wait    -          0.1     1  init
   2  wait     1         0.3     2  forth
   ...
   5  sleep    4         0.0     4  sleep
   ...
/> kill 5
```

`/proc/5` has a task's state as files: `status`, `args`, `fd` (its open files), `regs`, `mem`, and `ctl`, which
takes `stop`, `start`, `kill`.

The console has windows, as rio has on Plan 9: each is a whole console, kept whole while it isn't shown.  Windows
come in groups, a group a shell session: Ctrl-] c starts one (and shows it), with a shell; a program's own windows
(`echo new >/dev/wctl`) join its window's group.  Ctrl-] and a digit shows that window, Ctrl-] n and Ctrl-] p the
next and previous group, Ctrl-] Tab (or Ctrl-Tab, where the terminal sends it) the group's next window, and Ctrl-] x
hangs up the window shown.  A window that isn't shown runs on; its output is kept, and shown again when you come
back.  `echo $window` says which one you're in, and `cat /dev/wctl` lists them: number, group, size, `*` the one
shown.  `new-window top` runs a program in a window of its own, in this group (it goes when the program ends);
`new-window -g` starts another shell session.  Ctrl-] w lists the windows to choose from (a window's key, or the
arrows and Enter).  The keys can be changed: `echo key prefix ctrl-a >/dev/wctl` makes Ctrl-A the prefix, as
screen's.  `/dev/snarf` is the console's cut buffer, one for every window: `echo date >/dev/snarf`, then Ctrl-] y
in any window types it there.  Ctrl-] [ (or Shift-PgUp) looks back through a window's scrollback: the arrows and
PgUp move, Space marks a line, Enter copies the lines from it to the cursor into `/dev/snarf`, q goes back.
`echo history 128 >/dev/wctl` keeps 128 more lines in that window.  Ctrl-] s (or v) splits the window: a new
shell below it (or beside it), both shown at once; Ctrl-] and an arrow moves between them, Ctrl-] z shows one alone
and back, and `echo layout grid >/dev/wctl` (or `rows`, `columns`, `tabs`) arranges the group's windows.  Ctrl-] ?
lists the keys.

**Tasks working together.**  The C SDK's multitasking demos start four or five copies of themselves, each in a task
of its own, and draw what they do as they do it: memory they share (a shared segment), and semaphores to take turns
and wait for each other.  Put them in `/bin` first, then run them one at a time (each needs the tasks):

```
/> bind -a /sd/0/sample/c /bin
/> race                lost updates on a shared counter, then none with a mutex
/> chorus              four tasks print on one console: tangled, then whole lines, then in turn
/> philo               the dining philosophers (Ctrl-C ends it); philo -d deadlocks, and says so
/> prodcons            producers and consumers through a ring: counting semaphores
/> round               a four-voice round, each voice a task keeping its own time
```

[The C SDK's guide](../sdk/c/README.md#the-multitasking-demos) says what each shows, and their sources are in
`sdk/c/samples`.

## 6. The languages

HyForth is the shell already: definitions, `.s`, `words`, files with `include`, and libraries with `require`
(`require tools.fl`).  [using/hyforth.md](using/hyforth.md) is its guide.

hylang is the lisp, danlang on the Hydra:

```
/> hylang
hylang (danlang on the Hydra-16)
Type 'exit' to Exit

hylang> (+ 1/3 1/6)
=> 1/2
hylang> (map (fn {n} {* n n}) {1 2 3})
=> {1 4 9}
hylang> (ls "/rom")
=> {"README" "bench" "bin" "doc" "lib" "sample" "songs"}
hylang> exit
```

[using/hylang.md](using/hylang.md) is its guide.  BASIC is QuickBASIC's kind, the Hydra's own: a line typed runs at
once, a line with a number first goes into the program, and `RUN` runs it (or `basic prog.bas` a file, where line
numbers are optional and `SUB`s and `FUNCTION`s have variables of their own):

```
/> basic
> PRINT 1 / 3 + 1 / 6; 2 ^ 70; SQR(-4)
 1/2  1180591620717411303424  2i
> 10 FOR i = 1 TO 3: PRINT i; i / 4: NEXT
> RUN
 1  1/4
 2  1/2
 3  3/4
> SYSTEM
```

[using/basic.md](using/basic.md) is its guide.  The numbers are the same in every language, and in C: exact, of any
size, in any base.  `calc` works one out at rc: `calc 2/3 + 0.5` is `7/6`, `calc -b x 255` is `FF`.  And rc itself,
for an rc session: `rc` ([using/rc.md](using/rc.md)).

## 7. Sound

`scom` plays a short song on the YM2151 (in the emulator, hear it with `node sim/run.js -i --sound`, then the
Sound button at http://localhost:8016): `play
/sd/0/songs/test.zsm` plays a ZSM file, the format the Commander X16's tools (and Furnace) export.  `play -m 0 't180 o4
l8 c d e f g'` plays a line of the score language (its notes, lengths and octaves: [using/tools.md](using/tools.md),
"Scores"), and `echo note 0 60 >/dev/sndctl` a note (`echo off 0 >/dev/sndctl` ends it).  With a Vera X, channels
8-23 are its PSG's voices (`echo note 8 69 >/dev/sndctl`), and `play` plays a WAV file on its PCM.

## 8. A program of your own

The SDKs are in `reborn/sdk`: `asm` for assembly and `c` for C.  Copy a sample to a folder of your own and build it:

```
mkdir hi
cp sdk/asm/samples/hi/hi.s hi/
node build.js prog hi
```

That makes `hi/hi.hyx`, a program for the Hydra.  To run it, give the emulator the folder as `/pc` (what the PC tool,
`sim/tools/hydrapc.js`, does for a board over the serial line):

```
node sim/run.js -i --pc-dir hi
```

```
/> /pc/hi.hyx one two
Hello, one!
Hello, two!
I'm task 5, in /, in window 0.
/> cp /pc/hi.hyx /ram/bin/hi
/> hi three
Hello, three!
I'm task 5, in /, in window 0.
```

`/ram/bin` is the first member of `/bin`'s union, so a program there runs by its name.  The Hydra assembles one itself
too: `as /sd/0/sample/as/hi.s /ram/bin/hi` makes the same program (the SDK's include files and three of its samples are in
`/lib/as`; [using/tools.md](using/tools.md#the-assembler)), and `edit` is there for a source of your own.  A C program
is the same: a folder of `.c` files (`cp sdk/c/samples/hello/hello.c myc/`, then `node build.js prog myc`):

```
/> /pc/hello.hyx
hello from C
```

[../sdk/asm/README.md](../sdk/asm/README.md) and [../sdk/c/README.md](../sdk/c/README.md) are the SDKs' guides, and
[programming/README.md](programming/README.md) the programmer's guide: the system calls, memory, tasks and notes,
files and namespaces, and writing a server or a driver.

## Where next

* [hydra-16.md](hydra-16.md): the guide to the whole system, hardware and software, with links to the rest.
* [using/README.md](using/README.md): the guides for rc, the tools, HyForth, hylang and BASIC.
* `/rom/doc/api.md` on the Hydra: every system call, its registers and errors.
* [programming/README.md](programming/README.md): the programmer's guide, for programs of your own.
* [hardware.md](hardware.md): the board, its cards and the Vera X, in full.
* [status.md](status.md): where the system stands, and what each part measured.

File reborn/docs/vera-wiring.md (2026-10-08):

# Wiring the Vera X to the Hydra-16 through a bus breakout card

How to connect the VERA X 6.1 (Joe Burks's, the 2x13 header) to the Hydra-16 with a **HydraBusBreakoutCard** in
**slot 0**, two glue chips on a small protoboard, and wires; and, for a keyboard and mouse, the X16's input
controller beside them ([below](#the-keyboard-and-mouse-the-x16s-smc)).  Until the carrier card (the plan's
option A: [design/plans/VIDEO.md](design/plans/VIDEO.md); the card in [hardware.md](hardware.md#the-vera-x-slot-0))
exists, this is how the driver (`vid`) meets the real chip.

Everything here comes from the board's own schematics (`board/`, read only): netlists exported with KiCad 9's
`kicad-cli` from `board/HydraBusBreakoutCard/HydraBusBreakoutCard.kicad_sch` and `board/hydra-16.kicad_sch`, the
VERA's gateware (`c:\source\vera-module`, `fpga/source/top.v`), the OtterX's VERA connector and bus decoder (which
hosts the same card), and the W65C02S data sheet.

## What you need

* The VERA X 6.1, a VGA monitor, and its cable.
* A HydraBusBreakoutCard.
* A small protoboard with a **2x13 female header** (0.1") for the VERA X, and:
  * **U1: 74AHCT138** (a 3-to-8 decoder): the VERA's chip select.
  * **U2: 74ACT00** (four 2-input NANDs): its read and write strobes.
  * (Optional) **U3: 74AHCT245** (an 8-bit bus transceiver): full 5 V data levels (below).
  * A 0.1 µF capacitor at each chip, and 10 µF across the VERA's power pins.
* Dupont or wire-wrap wire, kept short (15 cm or less for the bus).

## The plan

* **Slot 0** (the main board's J12).  Its two I/O port selects are ports 2 and 3, `$FF20-$FF3F`, the VERA's 32
  registers; its IRQ A is IRQ line 2, which `vid` owns; its audio pair goes into the mixer's left and right.  In
  any other slot the address, the interrupt line and the mixer channel would all be different.
* **No buffers on the bus side.**  The breakout card is only headers: each slot pin to a header pin.  The slot's data
  lines are on the system data bus itself.
* **Glue logic.**  The VERA wants `CS#`, `RD#` and `WR#` (active low).  The bus has `R/W` (`RWB`) and `PHI2`, and an
  I/O page select; the strobes are made from them as the X16 and the OtterX make them.

## First: two labels on the breakout card are wrong

The breakout card's connector symbol and the main board's slot symbol disagree on two pins.  The main board drives
what its own schematic says:

| Breakout header | Its label | What slot 0 really carries | So |
| :--- | :--- | :--- | :--- |
| **J11 pin 3** | `+5VA` | **-5 V** (slot pin 9) | **Never use it as a 5 V supply** |
| **J7 pin 5** | `!RWB` | **/DMAB** (slot pin 23) | It's not an inverted R/W: don't use it for the strobes |

The other differences between the two symbols are only their point of view (an output of the board is an input of
the card).

## The breakout card's headers, as slot 0 drives them

Only the pins this wiring uses:

| Header | Pin | Signal | | Header | Pin | Signal |
| :--- | :--- | :--- | --- | :--- | :--- | :--- |
| J2 (Data Bus) | 1 | D7 | | J3 (Address Bus) | 9 | A7 |
| | 2 | D6 | | | 10 | A6 |
| | 3 | D5 | | | 11 | A5 |
| | 4 | D4 | | | 12 | A4 |
| | 5 | D3 | | | 13 | A3 |
| | 6 | D2 | | | 14 | A2 |
| | 7 | D1 | | | 15 | A1 |
| | 8 | D0 | | | 16 | A0 |
| J5 (Interrupts & I/O) | 2 | `nIO_S`: the `$FFxx` page, low only while PHI2 is high | | J6 (Clocks) | 4 | PHI2 |
| | 3 | `nIOB_S`: port 3, `$FF30-$FF3F` | | J7 (Bus Control) | 4 | RWB (high: a read) |
| | 4 | `nIOA_S`: port 2, `$FF20-$FF2F` | | J8 (Reset) | 1 | RESB (low: reset) |
| | 6 | IRQA: IRQ line 2 (3.3K pull-up on the board) | | J9 (Audio) | 2 | SND_CR: mixer right |
| J11 (Power) | 4 | +5 V | | | 3 | SND_CL: mixer left |
| | 5 | GND | | | | |

(J3 pin 1 is A15, down to A0 at pin 16.  `nIO_S` is the main board's `$FFxx` decode ORed with PHI1, so it's low
only in the second half of a cycle, while PHI2 is high; the board's 74LS154, U19, splits it into 16-byte ports by
A4-A7.)

## The glue logic

**U1, 74AHCT138: `CS#`** for `$FF20-$FF3F`.  Enabled by `nIO_S`, it decodes A5-A7: output Y1 is low for A7 A6 A5 =
0 0 1.

| U1 pin | Function | Connect to |
| :--- | :--- | :--- |
| 1 | A0 | J3 pin 11 (A5) |
| 2 | A1 | J3 pin 10 (A6) |
| 3 | A2 | J3 pin 9 (A7) |
| 4 | /E1 | J5 pin 2 (`nIO_S`) |
| 5 | /E2 | GND |
| 6 | E3 | +5 V |
| 8 | GND | GND |
| 14 | /Y1 | VERA pin 13 (`CS#`) |
| 16 | VCC | +5 V, 0.1 µF to GND |

Leave the other outputs (7, 9-13, 15) unconnected.

**U2, 74ACT00: `RD#` and `WR#`**.  `RD#` = NOT (PHI2 AND RWB): low while PHI2 is high in a read.  `WR#` = NOT (PHI2
AND NOT RWB): low while PHI2 is high in a write.  Gate 2 is the inverter.

| U2 pin | Function | Connect to |
| :--- | :--- | :--- |
| 1 | 1A | J6 pin 4 (PHI2) |
| 2 | 1B | J7 pin 4 (RWB) |
| 3 | 1Y | VERA pin 18 (`RD#`) |
| 4 | 2A | J7 pin 4 (RWB) |
| 5 | 2B | J7 pin 4 (RWB) |
| 6 | 2Y | U2 pin 10 (NOT RWB) |
| 7 | GND | GND |
| 8 | 3Y | VERA pin 15 (`WR#`) |
| 9 | 3A | J6 pin 4 (PHI2) |
| 10 | 3B | U2 pin 6 |
| 11 | 4Y | unconnected |
| 12, 13 | 4A, 4B | GND (an unused CMOS input never floats) |
| 14 | VCC | +5 V, 0.1 µF to GND |

Use the ACT/AHCT families as listed: their inputs take the TTL-level signals of the board's LS and F parts, and
they're fast, which the write strobe needs (Timing, below).

## The VERA X's 2x13 header, pin by pin

Pin 1 is SCL; odd pins on one row, even on the other (the OtterX's VERA connector, VIDEO.md's table).

| VERA pin | Signal | Connect to |
| :--- | :--- | :--- |
| 1 | SCL | unconnected (the VERA doesn't need it) |
| 2 | SDA | unconnected |
| 3 | +5 V | J11 pin 4 (+5 V) |
| 4 | GND | J11 pin 5 (GND) |
| 5 | D7 | J2 pin 1 |
| 6 | D6 | J2 pin 2 |
| 7 | D5 | J2 pin 3 |
| 8 | D4 | J2 pin 4 |
| 9 | D3 | J2 pin 5 |
| 10 | D2 | J2 pin 6 |
| 11 | D1 | J2 pin 7 |
| 12 | D0 | J2 pin 8 |
| 13 | `CS#` | U1 pin 14 |
| 14 | `RES#` | J8 pin 1 (RESB) |
| 15 | `WR#` | U2 pin 8 |
| 16 | `IRQ#` | J5 pin 6 (IRQA; or through an open-collector buffer, below) |
| 17 | A4 | J3 pin 12 |
| 18 | `RD#` | U2 pin 3 |
| 19 | A2 | J3 pin 14 |
| 20 | A3 | J3 pin 13 |
| 21 | A0 | J3 pin 16 |
| 22 | A1 | J3 pin 15 |
| 23 | GND | GND |
| 24 | GND | GND |
| 25 | Audio left | J9 pin 3 (SND_CL) |
| 26 | Audio right | J9 pin 2 (SND_CR) |

So the VERA's registers 0-31 are `$FF20-$FF3F`, `VERA_BASE` in `include/hw.inc`; the reset makes its FPGA configure
itself again (`vid` looks for the card for 0.3 s after one).

## Optional: 5 V data levels (U3, 74AHCT245)

The VERA X takes 5 V inputs (the X16's VERA module does it with an SN74CBTD3861 bus switch) but drives 3.3 V highs.
The W65C02S's data inputs are specified high at 0.7 VDD, **3.5 V**, so a 3.3 V high is 0.2 V short of the data
sheet.  The X16 and the OtterX run this way, as a CMOS input's real threshold is near 2.5 V, so try without it
first; if the card is found unreliably or reads come back wrong, put a 74AHCT245 between the VERA's data pins and
the bus (its TTL inputs take the 3.3 V, its outputs give 5 V):

| U3 pin | Function | Connect to |
| :--- | :--- | :--- |
| 1 | DIR | J7 pin 4 (RWB: high, A to B, the VERA to the bus) |
| 2-9 | A1-A8 | VERA pins 12, 11, 10, 9, 8, 7, 6, 5 (D0-D7) |
| 10 | GND | GND |
| 11-18 | B8-B1 | J2 pins 1-8 (D7 at pin 11, down to D0 at pin 18) |
| 19 | /OE | U1 pin 14 (`CS#`) |
| 20 | VCC | +5 V, 0.1 µF to GND |

With it, the VERA's data pins go to U3's A side only, not to J2.

## Power, grounds, wires

* **Power**: J11 pin 4 (+5 V) to VERA pin 3 and the chips; J11 pin 5 (GND) to VERA pins 4, 23 and 24 (all three)
  and the chips.  Use a heavier wire for the ground than for the signals: the whole data bus returns through it.
  10 µF and 0.1 µF across the VERA's pins 3 and 4, at the header.
* **Never J11 pin 3** (-5 V, whatever the card says).
* Keep the bus wires short and together; run a ground wire next to PHI2.  Plug and unplug with the power off.
* The VERA X's I2C pins stay unconnected; its VGA output goes to the monitor.  Its SD-card header is the VERA's own
  SPI controller, nothing to do with the bus: a card there (wired as the VERA X's notes say, at 3.3 V) is the storage
  driver's disk `v`, `/sd/v`.  Leave it empty and nothing's lost: `/sd/v` isn't there.

## Audio

The VERA's line outputs go into the mixer's slot 0 inputs: 10K resistors into an LF353 on ±12 V, wired as an
inverting summer (its inputs at a virtual ground), beside the YM2151.  A ground-centred line output connects
straight in.  Before wiring them, measure pins 25 and 26 against GND with the card running: if they sit at a DC
level (a DAC biased at half its supply) rather than about 0 V, put a 10 µF capacitor in series with each (its +
toward the VERA if the level is positive), or the mixer will amplify the offset too.

The mixer is a unity-gain summer (10K in, 10K feedback, for each of the slots' pairs and the YM2151's), so the VERA
comes out as loud as its line output is, which may be louder than the YM2151.  If so, a divider in each line evens
them (10K in series and 4.7K to GND at the mixer's side: about a third), as the carrier card's plan has it.

## The interrupt

Slot 0's IRQ A is its alone, with a 3.3K pull-up on the board into the 74LS148, so the VERA's `IRQ#` can drive it
directly: low for an interrupt, high (3.3 V) or let go otherwise.  The carrier card's plan puts an open-collector
buffer in the way, so the card only ever pulls the line low; on the bench a 74LS07 gate (VERA pin 16 to its input,
its output to J5 pin 6) does the same, if the line misbehaves.

## The keyboard and mouse: the X16's SMC

The input controller is the X16's own (VIDEO.md's step 6): its SMC, an **ATtiny861** with the X16 community's
firmware, `x16-smc` (github.com/X16Community/x16-smc), unchanged.  A PS/2 keyboard and a PS/2 mouse plug into it,
and it talks to the Hydra over the I2C bus at address `$42`, which every slot carries and the breakout card brings
to J10.  The `input` program reads it ([programming/video.md](programming/video.md#the-keyboard-and-the-mouse)).

* **What you need**: an ATtiny861 (the 20-pin DIP) programmed with an `x16-smc` release (its HEX file and fuses, as
  its README gives them; a TL866-class programmer does it), two 6-pin mini-DIN sockets (PS/2), a push button, a 10K
  resistor and a 0.1 µF capacitor.
* **Its pins** are the firmware's (`smc_pins.h`, the default build, not its `COMMUNITYX16_PINS` one; the firmware
  numbers its pins 0-7 for PA0-PA7 and 8-15 for PB0-PB7), on the chip's DIP pins:

| ATtiny861 pin | Port | The firmware's name | To |
| :--- | :--- | :--- | :--- |
| 1 | PB0 | `I2C_SDA_PIN` | J10 pin 1 (SDA) |
| 3 | PB2 | `I2C_SCL_PIN` | J10 pin 2 (SCL) |
| 18 | PA2 | `PS2_KBD_CLK` | The keyboard's socket, pin 5 (clock) |
| 4 | PB3 | `PS2_KBD_DAT` | The keyboard's socket, pin 1 (data) |
| 9 | PB6 | `PS2_MSE_CLK` | The mouse's socket, pin 5 |
| 8 | PB5 | `PS2_MSE_DAT` | The mouse's socket, pin 1 |
| 14 | PA4 | `POWER_BUTTON_PIN` | A push button to GND |
| 17 | PA3 | `PWR_OK` | +5 V through the 10K (the X16's power supply, "good") |
| 5, 15 | VCC, AVCC | | +5 V (J11 pin 4), the 0.1 µF to GND at the chip |
| 6, 16 | GND, AGND | | GND (J11 pin 5) |
| 10 | PB7 | (its RESET) | Nothing (the programmer's) |
| 20, 19, 2, 13, 12, 7, 11 | PA0, PA1, PB1, PA5, PA6, PB4, PA7 | `RESB_PIN`, `NMIB_PIN`, `IRQB_PIN`, `PWR_ON`, `ACT_LED`, the reset and NMI buttons | Nothing: they're the X16's |

The sockets' pin 3 is GND and pin 4 +5 V; pins 2 and 6 aren't used.

* **The I2C bus** has its pull-ups on the main board (RN1), so the SMC needs none.  Nothing else on the board
  answers at `$42`.  `IRQB_PIN` stays unconnected: the Hydra polls the SMC, as the X16 does, since the board's IRQ
  lines can't be masked (VIDEO.md says why).
* **Press the button once after switching on.**  The firmware is a power supply's controller first: its power-on,
  which the power button starts, is what starts the keyboard and mouse (their lines' pull-ups on, each reset), and it
  checks `PWR_OK`, held high here.  Till then it answers on I2C but has no keys.  (A build of `x16-smc` that powered
  on as it starts would do away with the button.)
* **Its version** is the first thing `input` reads: `ls /dev/i2c` lists `42` once the SMC's on the bus, and `ps`
  shows `input` running (with no SMC it ends at once).

## Timing (why the strobes are made so)

* **The VERA latches a write's data when its write strobe ends**: `bus_write = !CS# && !WR#`, data captured on its
  falling edge (`top.v`).  The 65C02S holds write data only **10 ns** after PHI2 falls (tDHW).  So `WR#` must end the
  write, promptly: it's PHI2 through one 74ACT00 gate, rising 3-9 ns after PHI2 falls.  (`CS#` comes through the
  board's decode and ends later: as the write's end it would miss the data.)
* **Reads**: the 65C02S needs data 10 ns before PHI2 falls (tDSR).  `CS#` falls some 15-20 ns after PHI2 rises
  (`nIO_S` from the board's 74F32, then U1), and the VERA's data follows within tens of ns.  PHI2 is high about
  140 ns at 3.58 MHz and 70 ns at 7.16 MHz: room at both.
* **No glitches**: `nIO_S` is low only while PHI2 is high, when the address is steady, so `CS#` can't pulse while it
  changes.
* **The slot's own port selects instead** (`CS#` = J5 pin 4 AND J5 pin 3, one gate of a 74AHCT08, in place of U1)
  also work, at 3.58 MHz: they come through the board's 74LS154, 25-35 ns more, which leaves too little of a 7.16
  MHz cycle.  U1 is as many chips and works at both speeds.

## Bringing it up

1. **The glue board alone** (no VERA on it), the breakout card in slot 0, the Hydra on at 3.58 MHz: check +5 V and
   GND at the VERA socket's pins 3 and 4.  With a logic probe or a scope, watch `CS#` (U1 pin 14), `RD#` (U2 pin 3)
   and `WR#` (U2 pin 8) while something touches `$FF20-$FF3F`: in BASIC, `10 POKE 65313,85: X=PEEK(65313): GOTO
   10`, `RUN` (Ctrl-C stops it).  `CS#` should pulse on every access, `WR#` on the POKE, `RD#` on the PEEK, each
   only while PHI2 is high.
2. **The VERA X**, power off, then on: the console comes up on the monitor (`vid` found the card; `cons` shows the
   windows on both the screen and the serial terminal).  `cat /dev/vid/ctl` starts `vera 47.0.2` (the gateware's
   version).
3. **Try it**: `echo border 4 >/dev/vid/ctl` (the border's colour), `cat /lib/font/cp437 >/dev/vid/font` (the PC's
   characters), `echo note 8 69 >/dev/sndctl` (an A from the PSG, through the mixer; `echo off 8 >/dev/sndctl`), `play`
   a WAV file (the PCM).
4. **No `/dev/vid`** (no card found): check +5 V, the data lines' order (VERA pin 5 is D7), A0-A4, `CS#`, `RD#` and
   `WR#` (each active low), and `RES#` (it must be high once the reset is over).  Then U3, for the 3.3 V highs.
5. **The keyboard and mouse** (the SMC): `ls /dev/i2c` lists `42`; press its button; then keys typed on the PS/2
   keyboard reach the shell, its Caps Lock lights, and `cat /dev/vid/mouse` prints a line each time the mouse moves,
   the pointer following it on the screen.
6. **Then 7.16 MHz**, once everything works at 3.58 (the board's faster clock, and a build with `--clock 2`).

[programming/video.md](programming/video.md) is the programmer's side: the driver's files, claims, the PSG and the
PCM, the keyboard and the mouse.

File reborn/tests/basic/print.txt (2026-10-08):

PRINT 1; 2; -3
PRINT "a"; "b"; 1; "c"
PRINT 1, 2, 3
PRINT "zone", "next"; "x", "y"
PRINT "abcdefghijklmnop", "q"
PRINT "end ;";
PRINT " same line"
PRINT "end ,",
PRINT "next zone"
PRINT
PRINT TAB(5); "at 5"; TAB(12); "at 12"
PRINT "abc"; TAB(2); "next line's 2"
PRINT SPC(3); "three"; SPC(0); "none"
PRINT "pos"; POS(0)
PRINT 1 / 3; -2 / 3; 10 / 4; 0.5; -0.25; 1.50; 100.0
PRINT 2 ^ 70; -(2 ^ 70)
PRINT 1 + 2i; -2i; 0.5 - 1 / 3 * 1i
PRINT 0; -0; 1E3; 1.25E-1
PRINT STR$(5); STR$(-5); STR$(1 / 3); "|"
? "the short form"; 7
WRITE 1, "two", 1 / 3, -4
WRITE "a, b", 5
PRINT USING "###"; 5; 42; 1234
PRINT USING "##.##"; 3.14159; -2.5; 0.005
PRINT USING "+##.#"; 2.25; -2.25
PRINT USING "##.#-"; -1.5; 1.5
PRINT USING "#,###,###"; 1234567
PRINT USING "$$###.##"; 12.5
PRINT USING "**###"; 42
PRINT USING "!"; "first"
PRINT USING "\  \"; "four letters"
PRINT USING "&!"; "all of it"; "x"
PRINT USING "_#: ##"; 7
PRINT USING "{} and {}"; 1 / 3, "text"
PRINT USING "{x} is {}"; 255, 255
PRINT USING "{#b} {c} {16r}"; 5, 4, 31
PRINT USING "#####"; 2 ^ 20
BASE "x"
PRINT 0FF; -10; 1 / 2; 1 / 3
PRINT STR$(0FF, "d"); "|"; STR$(0A, "b")
BASE "b"
PRINT 101; 0.1
BASE "d"
PRINT 255
WIDTH 20
PRINT "a", "b", "c", "d"
WIDTH 80
PRINT "done"

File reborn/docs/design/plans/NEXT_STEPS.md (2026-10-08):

## **Next steps: making the Hydra fun and useful**

What the Hydra-16 has, what's missing for hobbyists and programmers, and an order to do it in.  It builds on [IDEAS.md](IDEAS.md) (the running list), [VIDEO.md](VIDEO.md) (the Vera X card) and the [code review](CODE_REVIEW.md).

### **Contents**
1. [Where it stands](#where-it-stands)
2. [What a newcomer runs into](#what-a-newcomer-runs-into)
3. [The gaps, by theme](#the-gaps-by-theme)
4. [Milestones](#milestones)

---

### **Where it stands**

The Hydra already does more than most homebrew 65C02 machines:
* **The system:**
  * 16 hardware tasks, preemptive scheduling, per-task memory and shared memory;
  * Plan 9-style IO: files, pipes, namespaces, `/env`, `/proc`, exit statuses, background jobs, semaphores.
* **Files:** SD cards with a real filesystem (HydraFS: directories, sparse files, a checker, partitions), a clock chip, and files built into the ROM (`/rom`).
* **The shell and languages:**
  * a shell that's also a language (HyForth: pipelines, redirection, scripts, libraries from files);
  * a C toolchain (cc65, with a library for the Hydra's calls and a guide);
  * a line editor;
  * WOZMON with a disassembler.
* **Sound:** the YM2151, with a library, `/dev/snd`, a ZSM song player and a score language.
* **Tools:** an emulator that runs the real ROM, 80 regression tests, a hardware test, and documentation for every part.

What's missing is mostly **on-ramps** (ways to start without the author's setup) and **things to make** (a screen, input, games, hardware projects, languages beginners know).

---

### **What a newcomer runs into**

| A newcomer wants to ... | Today | What would help |
| :--- | :---- | :--- |
| Try it without building a board | Install Node and cc65, clone, build, run the emulator in a terminal | **A web emulator**: a page that boots the ROM, with a sample card |
| Build it on Linux or macOS | Windows `.bat` files only | **`build.js`** for any OS; CI; release images |
| Plug in a monitor and keyboard | A serial terminal is the only console | **Vera X** video and a keyboard ([VIDEO.md](VIDEO.md)) |
| Get programs onto it | Take the SD card out and copy with `hydrafs.js` | **A PC folder as a filesystem over serial** (`/pc`: built), then XMODEM |
| Type a first Forth program | `: x 65 . ;` silently breaks, and `.` prints hex | **HyForth fixes**: literals compiled, decimal output, history ([review](CODE_REVIEW.md#hyforth)) |
| Write BASIC | No BASIC | **hy-basic**, adapted to run as a program |
| Blink an LED, read a sensor | The VIA's port A and I2C are on a header, but there's no driver | **`/dev/i2c`, `/dev/spi`, `/dev/gpio`** |
| Make a game | No graphics, no joystick | Vera X sprites and tiles, pads, a small game library |
| Learn how it works | Complete references, which assume a lot | **Tutorials** first, then the references |

---

### **The gaps, by theme**

Sizes are rough: **S** a few days, **M** a few weeks, **L** longer.

#### **1. Easy to try and to build**

* **A web emulator (M).**  `hydrasim.js` is JavaScript already.  Separate its core from Node ([review](CODE_REVIEW.md#the-emulator)), and serve:
  * the ROM images and a sample card image in a static page, with xterm.js as the terminal;
  * later, the VERA's canvas.

  Host it with the project's GitHub Pages.  This is the single biggest way to reach people.
* **`build.js` and CI (S-M).**  One build script for any OS, finding cc65 by `CC65_HOME` or the `PATH`.  A GitHub Actions job builds and runs the tests on every push.  Tagged releases carry the ROM images, a card image, and the C library.
* **A starter card image (S).**  A HydraFS image with:
  * `boot.hys` and `PATH`/`HOME` set up;
  * the samples in `/bin`, libraries in `/lib` and songs in `/songs`;
  * the tutorials' files.

  Make it from a folder in the repository with `hydrafs.js import`, at every build.
* **Tutorials (M, ongoing).**  Before the references:
  * the first hour with HyForth;
  * a first C program, from the PC to the card to running it;
  * a first assembly program;
  * writing a small device server;
  * once Vera X exists, the first sprite.
* **A contributor's guide (S).**  `CONTRIBUTING.md`:
  * the code style: the column layout, `IN:`/`OUT:` headers, CRLF;
  * the recipes: how to add a thunk, a gate, a server, a HyForth word or a test;
  * the rules: `board/` is read-only, run the tests before a push.

  Much of it is in the Programmer's Guide already; this gathers the rules in one place.

#### **2. A standalone computer**

* **Video: the Vera X card (L).**  640x480 VGA, text and tiles, 128 sprites, the screen as the console ([VIDEO.md](VIDEO.md)).
* **Keyboard, mouse and game pads (M).**  Vera X's input controller on IRQ line 3, over I2C ([VIDEO.md](VIDEO.md#the-card)).  (Built, October 2026, for the keyboard and mouse: the X16's SMC, polled over I2C, not on line 3; VIDEO.md's step 6.)
* **Files from the PC without the card (M).**  Two ways, both worth having:
  * **XMODEM** ([IDEAS.md](IDEAS.md) item 6): send and receive single files with any terminal program.
  * **`/pc`**: *(Built: [PC.md](PC.md).)*  A small Node program on the PC serves a folder over the serial port, and the Hydra mounts it as a file server (9P-style requests, which is what the IO layer speaks inside).  Then `cc65` output is runnable at once (`/pc/bin/game`), with no copying.  The emulator can serve a folder the same way.  For a programmer this is the biggest workflow win.
* **A full-screen editor (M).**  `edit` is a line editor.  A small screen editor (nano-like: arrows, insert, search, save) using conio works on a terminal today and on the Vera X screen later.

#### **3. Languages and tools on the machine**

* **HyForth fixes (S-M):** *(Done: [CODE_REVIEW.md](CODE_REVIEW.md#what-was-done).)*
  * numbers compiled inside definitions;
  * decimal output (`decimal`, `hex`, `u.`);
  * line history and editing;
  * readable error messages;
  * `syscall` fixed ([review](CODE_REVIEW.md#bugs)).
* **BASIC: EhyBASIC (M).**  What most hobbyists expect, and there's one already: EhyBASIC ([burntcouch/ehybasic](https://github.com/burntcouch/ehybasic)), Microsoft BASIC from the mist64/msbasic and Ben Eater line with Applesoft touches, built today as a paged ROM image started from WOZMON (`A000R`) against the 1.8Ce ROM.  To be adapted to the system as it is now: its zero page into what a program has (`$E0-$FF`: Microsoft BASIC uses well over 100 bytes, `CHRGET` among them), its calls through the current thunks, and `EXIT` back to the shell.  As a `.hyx`:
  * `INPUT`/`PRINT` through stdio (so it works in pipelines and from scripts);
  * `LOAD`/`SAVE` on HydraFS files (and `/pc`'s, once it's there);
  * a `/rom/bin/basic`, so it's there with no card.

  Later, `SOUND`, `SPRITE` and `PLOT` statements that use `/dev/snd` and Vera X.
* **An assembler on the Hydra (M).**  A 65C02 assembler as a program (source file in, `.hyx` out), or as HyForth words (`code ... end-code`).  Then programs can be written without a PC at all.  WOZMON could get a one-line mini-assembler like the Apple II monitor's.
* **A debugger through `/proc` (M).**  Plan 9's way ([PROC.md](PROC.md)): `/proc/N/mem` (read and write a task's RAM), `/proc/N/regs` (its saved frame), `/proc/N/ctl` (`stop`, `start`, `step`, `break ADDR`).  A debugger is then just a program, in C or HyForth, and it debugs other tasks while the system runs.
* **Tools as programs (S each).**  [IDEAS.md](IDEAS.md) item 10, and more:
  * reading files: `more`, `head`, `tail`, `grep`, `xd` (a hex dump);
  * managing them: `cp -r`, `find`, `sort`, `diff`, `df`, `du`, `touch`;
  * the system: `date`, `which`, `top` (from `/dev/proc`).

  Most are small C programs.  They make good examples for newcomers and good `/rom/bin` residents.
* **More C (S-M):** `MM_ALLOC` from C (paged memory for bigger programs).  (`_stroserror` gives the OS's messages now.)

#### **4. Making things: hardware projects**

The board already has the connections: the VIA's port A on J27 (6 free pins and CA1/CA2), I2C on J27 and every slot, 8 SPI device headers, and 6 slots.  It needs drivers and examples, in this order:
* **`/dev/i2c` (M):** the bit-banged bus as a file per address (`/dev/i2c/50` an EEPROM, `/dev/i2c/68` a sensor), with reads and writes as transfers.  Vera X's input controller needs it anyway.
* **`/dev/spi` (S-M):** raw access to SPI devices 0-f (8-f are decoded by cards), for displays, ADCs and radio modules.  *(Built: `/dev/spi/N`, a transaction a write and the bytes that came back read after, modes 0 and 3: [io.md](../../../../old/docs/programming/io.md#spi-devices-devspi).)*
* **`/dev/gpio` (S):**  *(Built: [io.md](../../../../old/docs/programming/io.md#gpio-devgpio), and the [tutorial](../../../../old/docs/tutorial.md#7-an-led-and-a-button)'s LED and button.)*
  * `echo 1 > /dev/gpio/2` lights an LED;
  * `cat /dev/gpio/3` reads a button;
  * `/dev/gpio/ctl` sets directions;
  * CA1 can be an interrupt (`/dev/gpio/ca1`).
* **Networking (L).**  A WIZnet W5500 module (Ethernet with its own TCP/IP, on SPI) on one of the SPI headers, served as Plan 9's `/net` (`/net/tcp/clone`, `ctl`, `data`).  Then:
  * telnet into the Hydra (a shell per connection: the Hydra has 16 tasks);
  * fetch files over HTTP;
  * an IRC client.

  An ESP32 modem card (a serial port in a slot with AT commands) is a simpler alternative.
* **A prototyping guide (S):** how to build a slot card, using the breakout card, what the bus timing is, and the open-collector rule for IRQs.  The [hardware reference](../../hardware.md) has the facts; a guide turns them into a first project.

#### **5. Sound and music**

* **Importing music** from other machines (VGM, MIDI files, trackers) into ZSM: planned in [SOUND.md](SOUND.md).
* **The VERA's PSG and PCM** ([VIDEO.md](VIDEO.md)): 16 more voices, sampled sound, and X16 songs that play in full.
* **A tracker (M-L)** once there's a screen: write songs on the Hydra itself, saving ZSM.
* **MIDI (M):** a slot card with a UART at 31,250 baud, as `/dev/midi`; play the YM2151 from a keyboard, or record into the score language.

#### **6. Games and demos**

* **A game library (M)** for C and HyForth:
  * sprites, tiles, input and sound under one small API, in the manner of a fantasy console;
  * on Vera X, with `/dev/snd`;
  * a frame loop paced by the VERA's frame interrupt.
* **Samples to learn from and play:** Snake, Breakout, Tetris, a scrolling shooter, a Mandelbrot, a paint program, the music visualiser.  Each is a few hundred lines, and good in `/rom/bin`.
* **Multitasking is the Hydra's party trick:** a game runs while the music plays in another task and a shell stays at Ctrl-]'s reach.  Show it off in the demos.

#### **7. The OS**

From [IDEAS.md](IDEAS.md), still open:
* **Notes with handlers** (Plan 9's `notify`): a program catches Ctrl-C to clean up;
* **notices** when background tasks end, and `wait` for all of them;
* **`rename`** across directories.

New:
* **`/dev/sysname` and a version** (the build's stamp: [review](CODE_REVIEW.md#the-build));
* **`/dev/proc/N/ctl`** (`kill`, `stop`, `start`), on the way to the debugger above;
* **memory statistics** for `top`.

#### **8. Board V2**

[IDEAS.md](IDEAS.md) has the RDY wait states, and the V1 errata are listed in the [hardware reference](../../hardware.md#v1-errata).  For a V2 wish list:
* **wait states**, so the CPU can run at 7-14 MHz with the YM2151;
* **a 1.8432 MHz clock for the ACIA**, so the standard baud rates are exact;
* **the bank register bits** in order;
* **the audio jack's channels** the usual way round;
* **a PS/2 or USB keyboard controller on the board** (or keep it on Vera X);
* **a footprint or header for the VERA module** on slot 0's position, if the card proves itself.

---

### **Milestones**

Each milestone leaves the project in a state worth showing.

**1. Easy to start** (mostly software, no new hardware):
1. *(Done with the code review's fixes: [CODE_REVIEW.md](CODE_REVIEW.md#what-was-done).)*  HyForth's fixes and `syscall`; `build.js` and CI; the ROM budget report and room on every page; the emulator in modules, with no Node.js in its core; the first tutorial ([tutorial.md](../../../../old/docs/tutorial.md)).
2. Releases with ROM and card images (a starter card), once the CI runs on GitHub.
3. The web emulator with the starter card.
4. `CONTRIBUTING.md`.

**2. Storage and names, then programming and making things** (the order set for it):
1. RAM and ROM disks ([DISKS.md](DISKS.md)).  *Done:* the paged ROM is the disk `x`, a HydraFS volume mounted at `/rom`; the RAM disks `r` and `s` (each shell's own area at `/ram`, and `/sram`), the tasks' areas, the program caches; the test song a file; with no card, `/ram` and `/rom/boot.hys`; `/dev/ram` for task 0.
2. Namespaces the Plan 9 way ([NAMESPACES.md](NAMESPACES.md)).  *Done:* 32 entries a task and 32 in the system namespace every task sees (`-s`), mounts with a spec, unions (`bind -a`, `-b`, `-c`) and their listings, `hide`, `unmount new old`, `ns` as `bind` lines; the default namespace (`/rom/lib/namespace`, a card's `lib/namespace`), `.` then `/bin` in place of search paths; C's `hy_bind` and the rest; `newns [file]`, a fresh namespace (C's `hy_newns`).
3. `/proc` ([PROC.md](PROC.md)).  *Done:* `/proc` mounted, `ns`, `pages`, `ctl` for the family only, and `/proc/N/cmd` (`send N line`: shell N runs it as if typed); `/proc/N/mem` and `/proc/N/ram`, a task's memory as files, for its family and task 0.  *To do:* `regs` and `fd`, then the debugger's `ctl` commands with the debugger.
4. `/dev/spi`.  *Done:* `/dev/spi/N` and its `ctl` (modes 0 and 3), shared with the SD cards (a device with a card started is busy, and a card isn't started on an open one).
5. `/dev/gpio`, with a hardware project tutorial.  *Done:* the pins (`/dev/gpio/N`, `port`), `ctl` (directions, CA1's edge, CA2), `/dev/gpio/ca1` (a read waits for CA1's edge: its interrupt), and the tutorial's LED and button.
6. `/pc`, a PC folder over the serial port ([PC.md](PC.md)).  *Done:* the device `pc` (in the serial task, mounted at `/pc` by `/rom/lib/namespace`), its frames between the console's bytes (CRC-checked, sent again when damaged or lost), and the PC tool (`sim/tools/hydrapc.js`: the terminal too, `--read-only`); the emulator's `--pc-dir`.
7. **Next:** XMODEM.
8. Not yet placed in the order: EhyBASIC, adapted to the system (a `.hyx`, and `/rom/bin/basic`), and `/dev/i2c`.

**3. A computer on its own:**
1. The emulator's VERA, then the Vera X carrier card.
2. The screen console; `/dev/vid`; HyForth's `video` words with turtle graphics.
3. The input controller (on `/dev/i2c`), keyboard input.
4. A full-screen editor.
5. The game library and the first games; the VERA's PSG and PCM.
6. Tools as programs; an assembler.

**4. Connected:**
1. `/net` on a W5500; telnet and a file fetcher.
2. The debugger through `/proc`.
3. Music import; a tracker.

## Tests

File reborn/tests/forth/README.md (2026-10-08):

# The Forth 2012 test suite

The forth test (`tests/tests.js`) runs these on HyForth: the files from Gerry Jackson's Forth 2012 test suite
(<https://github.com/gerryjackson/forth2012-test-suite>, `src/`), as they came, in its own order (`runtests.fth`'s, for
the word sets HyForth has):

| File | What | Terms (each file's notice) |
| :--- | :--- | :--- |
| `prelimtest.fth` | The preliminary tests, before the tester | Gerry Jackson's: public domain |
| `tester.fr` | John Hayes's tester (`T{ ... -> ... }T`) | (C) 1995 Johns Hopkins University / Applied Physics Laboratory: may be distributed freely as long as the notice remains |
| `core.fr` | The Core word set's tests | The same as `tester.fr` |
| `coreplustest.fth` | More Core tests | Gerry Jackson's: public domain |
| `utilities.fth`, `errorreport.fth` | What the optional word sets' tests use (`REPORT-ERRORS`: the table at the end) | Gerry Jackson's: public domain |
| `coreexttest.fth` | The Core Extension word set's tests | Gerry Jackson's: public domain |
| `blocktest.fth` | Block (and its extension's words) | Steve Palmer's (with others' contributions): public domain |
| `doubletest.fth` | Double-Number (and its extension's 2ROT, 2VALUE, DU<) | Gerry Jackson's: public domain |
| `exceptiontest.fth` | Exception | Gerry Jackson's: public domain |
| `facilitytest.fth` | Facility (its structures) | Gerry Jackson's: public domain |
| `filetest.fth` | File Access | Gerry Jackson's: public domain |
| `required-helper1.fth`, `required-helper2.fth` | What `filetest.fth` INCLUDEs and REQUIREs | Gerry Jackson's: public domain |
| `localstest.fth` | Locals | Gerry Jackson's: public domain |
| `memorytest.fth` | Memory-Allocation | Gerry Jackson's: public domain |
| `toolstest.fth` | Programming-Tools | Gerry Jackson's: public domain |
| `searchordertest.fth` | Search-Order | Gerry Jackson's: public domain |
| `stringtest.fth` | String | Gerry Jackson's: public domain |

They're bytes, LF line ends (`.gitattributes`: not text to Git).  The test puts them on an emulated SD card, each as
itself, with a `run.fs` of its own that INCLUDEs them in turn, as `runtests.fth` does (and has a line for `core.fr`'s
ACCEPT test after it: ACCEPT reads stdin); then it runs `cd /sd/0; forth <run.fs`.  `filetest.fth` makes its files
there too.

`numberstest.fth` is HyForth's own, not the suite's: the number words (`lib numbers`: `numbers.fl`, on the numbers
and math libraries) checked in the suite's way, with `tester.fr`'s `T{ ... -> ... }T`, each number by its text
(`N>STR`); its last lines are typed (`N.`, `N.BASE`, `N.S`, `NFORMAT`, cells in bases that aren't a radix) and the
count of its errors.  The `fnumbers` test puts it and `tester.fr` on a card of its own, with a `nums.fs` that
REQUIREs `string.fl`, `hydra.fl` and `numbers.fl` and INCLUDEs them, and compares what's typed.

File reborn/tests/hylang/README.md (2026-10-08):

# hylang's tests: danlang's regression suite

These are danlang's regression suite, `tests/regress/` from <https://github.com/SNSTRUTHERS/danlang>, as it has them
(copied whole, line ends LF).  danlang, the C# interpreter, is hylang's reference, and `reference.md` there its
specification: the suite is that specification's executable form, so hylang passes it unchanged.  A change to the
language goes into danlang first, with checks here, and is copied over.  danlang's library (its `lib/`) is hylang's
own now, on the ROM disk (`romfs/lib/hylang`).  The `hysuite1` to `hysuite5` tests run the suite in five parts, side
by side under `sim/test.js -j`: each part is `run.dl` itself with its list of files cut to the part's, and `eval.dl`,
nearly all of the suite's time in its tail loops, is cut into pieces on the test's card (`tests/tests.js`:
`HYSUITE_PARTS`, `HYSUITE_CUTS`).  The files here stay as danlang has them.

The old hylang (phase 7 as first built, to commit `a0973eb`) is gone: hylang was written again from scratch, to the
plan "danlang: review and 65C02 plan" (`docs/hylang.md` has its design), and passes the whole suite (1,530 checks
since the numbers plan's step 4, its `numbers.dl`, `math.dl`, `run.dl` and `library.dl` danlang's `feature/numbers`:
the base, the stored format, the math functions).  Each phase ran the files it made pass, from an emulated card,
and none that passed failed after; the phase each first ran from:

| File | What | Runs from |
| :--- | :--- | :--- |
| `harness.dl` | The checks: `check`, `check-error`, the count of each and of the failures | 3 |
| `run.dl` | Loads `harness.dl`, then each file, and prints the count; its status is 1 if a check failed; the `hysuite` tests (`hylang part.dl`: `run.dl` with a part's files) | 8 (it wants danlang's library loaded: from phase 4 to 7, a script of hylang's own loaded it first) |
| `reader.dl` | The reader: numbers in every base, strings, here strings, characters, atoms, symbols, comments, `[...]`, the shorthand, bytes, `read` | 7 (the reader is phase 2's, checked by the emulator's `hylang` test till then) |
| `eval.dl` | Calls, partial application, extra arguments, too many, tail calls (50,000 deep), nesting | 3 (its numbers past a fixnum made smaller); 5 whole |
| `scope.dl` | Lexical scope, closures, `set!`, a Q-expression run where it was written, `let`, fexprs | 3 |
| `control.dl` | `if`, `and`, `or`, `<=>`, `while`, `each`, `dotimes`, `range`, `try` | 3 |
| `errors.dl` | Errors as values: through calls and built-ins, `try`, the error texts | 3 |
| `lists.dl` | The list built-ins, `sort` | 4 (its numbers: 5) |
| `types.dl` | `type-of`, the type tests, symbols and atoms | 4 (its numbers, a hash and a stream: 5, 6, 7) |
| `library.dl` | The library's built-ins and `globals.dl`'s functions | 4 (its numbers: 5) |
| `numbers.dl` | The tower, every base, the conversions | 5 |
| `math.dl` | `sqrt`, `exp`, `log`, the circle's, `pi`, `pow`, `digits`: exact or correctly rounded | the numbers plan's step 4 |
| `bits.dl` | Bits and bytes | 5 (its streams: 7) |
| `buffers.dl` | Buffers: made, read, written, filled, copied, from a stream and to one; equal, ordered | danlang's `feature/speed` (to `744d4db`), with `clock`, `round` and `:update` |
| `strings.dl` | Strings and characters | 6 |
| `hashes.dl` | Hashes, tags, methods | 6 |
| `io.dl` | Streams, `load`, `save`, `read` | 7 |
| `system.dl` | Files, programs, the environment, the clock | 7 |

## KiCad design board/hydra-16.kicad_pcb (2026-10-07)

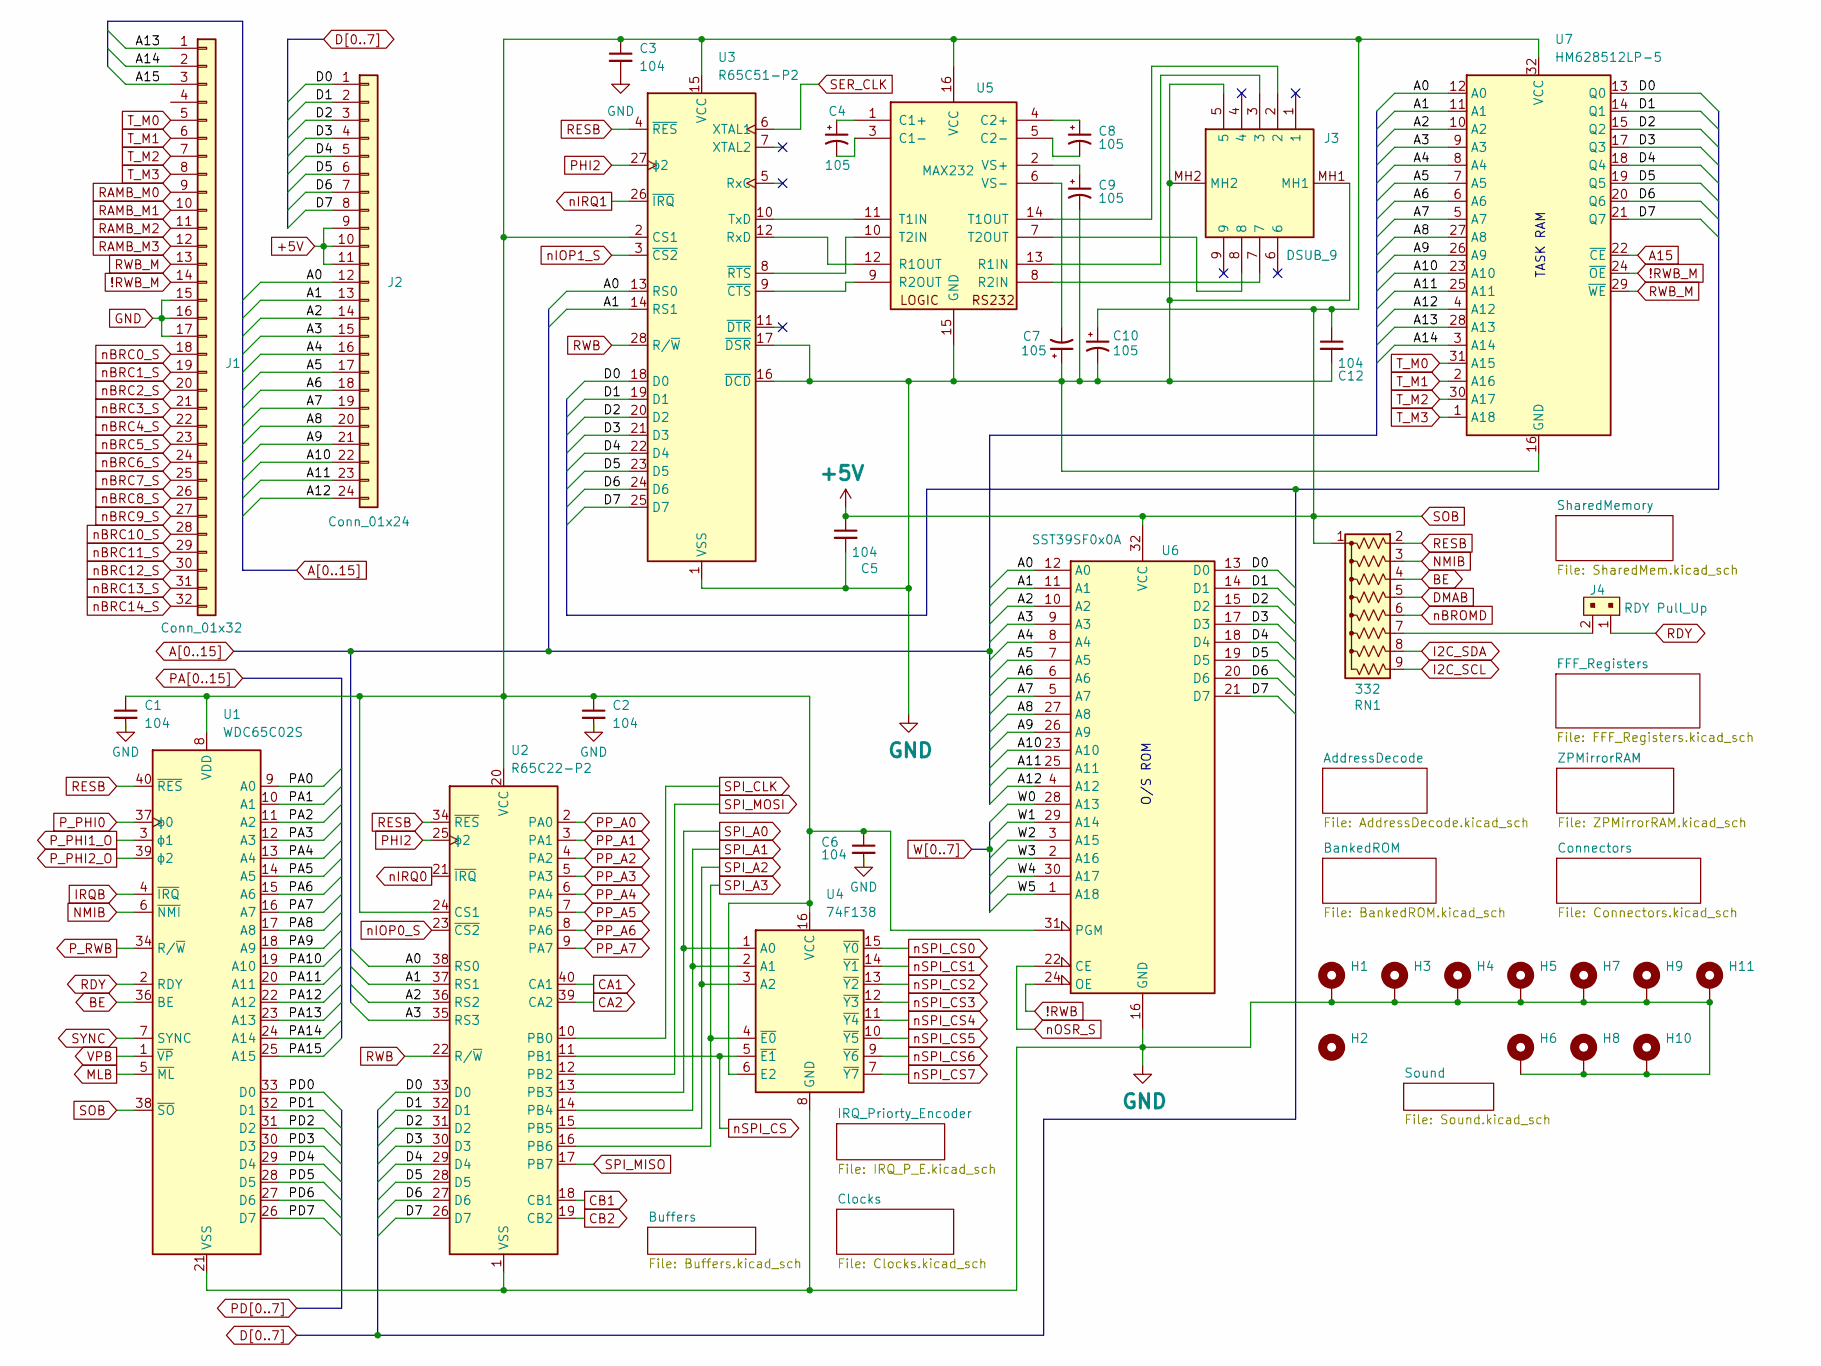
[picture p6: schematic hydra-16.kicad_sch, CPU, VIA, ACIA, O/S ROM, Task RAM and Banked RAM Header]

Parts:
C1, C2, C3, C5, C6, C12: 104; C_Disc_D5.0mm_W2.5mm_P5.00mm
C4, C7, C8, C9, C10: 105; C_Disc_D5.0mm_W2.5mm_P2.50mm
H1, H3, H4, H5, H6, H7, H8, H9, H10, H11: MountingHole_Pad; MountingHole_4mm_Pad_TopBottom
H2: MountingHole; MountingHole_4mm
J1: Conn_01x32; PinSocket_1x32_P2.54mm_Vertical
J2: Conn_01x24; PinSocket_1x24_P2.54mm_Vertical
J3: DSUB_9; L77SDE09SA4CH3R; Mouser Part Number 523-L77SDE09SA4CH3R
J4: RDY Pull_Up; PinHeader_2x01_P2.54mm_Vertical; MPN 22-23-2021; Digi-Key_PN WM4200-ND
RN1: 332; R_Array_SIP9
U1: WDC65C02S; DIP-40_W15.24mm_Socket_LongPads
U2: R65C22-P2; DIP-40_W15.24mm_Socket_LongPads
U3: R65C51-P2; DIP-28_W15.24mm_Socket_LongPads
U4: 74F138; DIP-16_W7.62mm_Socket_LongPads
U5: MAX232; DIP-16_W7.62mm_Socket_LongPads
U6: SST39SF0x0A; PLCC-32_THT-Socket
U7: HM628512LP-5; DIP-32_W15.24mm_Socket_LongPads

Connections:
!RWB: U6.24 (OE); also elsewhere on the board
!RWB_M: J1.14, U7.24 (~OE); also elsewhere on the board
+5V: C1.1, C2.1, C3.1, C5.1, C6.1, C10.1, C12.1, J2.9, J2.10, J2.11, RN1.1 (common), U1.8 (VDD), U1.38 (~SO), U2.20 (VCC), U2.24 (CS1), U3.2 (CS1), U3.15 (VCC), U4.6 (E2), U4.16 (VCC), U5.16 (VCC), U6.31 (PGM), U6.32 (VCC), U7.32 (VCC); also elsewhere on the board
A0: J2.12, U2.38 (RS0), U3.13 (RS0), U6.12 (A0), U7.12 (A0); also elsewhere on the board
A1: J2.13, U2.37 (RS1), U3.14 (RS1), U6.11 (A1), U7.11 (A1); also elsewhere on the board
A2: J2.14, U2.36 (RS2), U6.10 (A2), U7.10 (A2); also elsewhere on the board
A3: J2.15, U2.35 (RS3), U6.9 (A3), U7.9 (A3); also elsewhere on the board
A4: J2.16, U6.8 (A4), U7.8 (A4); also elsewhere on the board
A5: J2.17, U6.7 (A5), U7.7 (A5); also elsewhere on the board
A6: J2.18, U6.6 (A6), U7.6 (A6); also elsewhere on the board
A7: J2.19, U6.5 (A7), U7.5 (A7); also elsewhere on the board
A8: J2.20, U6.27 (A8), U7.27 (A8); also elsewhere on the board
A9: J2.21, U6.26 (A9), U7.26 (A9); also elsewhere on the board
A10: J2.22, U6.23 (A10), U7.23 (A10); also elsewhere on the board
A11: J2.23, U6.25 (A11), U7.25 (A11); also elsewhere on the board
A12: J2.24, U6.4 (A12), U7.4 (A12); also elsewhere on the board
A13: J1.1, U7.28 (A13); also elsewhere on the board
A14: J1.2, U7.3 (A14); also elsewhere on the board
A15: J1.3, U7.22 (~CE); also elsewhere on the board
BE: RN1.4 (R3), U1.36 (BE); also elsewhere on the board
CA1: U2.40 (CA1); also elsewhere on the board
CA2: U2.39 (CA2); also elsewhere on the board
CB1: U2.18 (CB1)
CB2: U2.19 (CB2)
D0: J2.1, U2.33 (D0), U3.18 (D0), U6.13 (D0), U7.13 (Q0); also elsewhere on the board
D1: J2.2, U2.32 (D1), U3.19 (D1), U6.14 (D1), U7.14 (Q1); also elsewhere on the board
D2: J2.3, U2.31 (D2), U3.20 (D2), U6.15 (D2), U7.15 (Q2); also elsewhere on the board
D3: J2.4, U2.30 (D3), U3.21 (D3), U6.17 (D3), U7.17 (Q3); also elsewhere on the board
D4: J2.5, U2.29 (D4), U3.22 (D4), U6.18 (D4), U7.18 (Q4); also elsewhere on the board
D5: J2.6, U2.28 (D5), U3.23 (D5), U6.19 (D5), U7.19 (Q5); also elsewhere on the board
D6: J2.7, U2.27 (D6), U3.24 (D6), U6.20 (D6), U7.20 (Q6); also elsewhere on the board
D7: J2.8, U2.26 (D7), U3.25 (D7), U6.21 (D7), U7.21 (Q7); also elsewhere on the board
DMAB: RN1.5 (R4); also elsewhere on the board
GND: C1.2, C2.2, C3.2, C5.2, C6.2, C7.1, C9.2, C10.2, C12.2, H1.1, H3.1, H4.1, H5.1, H6.1, H7.1, H8.1, H9.1, H10.1, H11.1, J1.15, J1.16, J1.17, J3.5, J3.MH1, J3.MH2, U1.21 (VSS), U2.1 (VSS), U3.1 (VSS), U3.16 (~DCD), U3.17 (~DSR), U4.8 (GND), U5.15 (GND), U6.16 (GND), U7.16 (GND); also elsewhere on the board
I2C_SCL: RN1.9 (R8), U2.2 (PA0); also elsewhere on the board
I2C_SDA: RN1.8 (R7), U2.3 (PA1); also elsewhere on the board
IRQB: U1.4 (~IRQ); also elsewhere on the board
MLB: U1.5 (~ML)
NMIB: RN1.3 (R2), U1.6 (~NMI); also elsewhere on the board
unnamed: J4.2, RN1.7 (R6)
unnamed: U3.12 (RxD), U5.12 (R1OUT)
unnamed: U3.10 (TxD), U5.11 (T1IN)
unnamed: U3.9 (~CTS), U5.9 (R2OUT)
unnamed: U3.8 (~RTS), U5.10 (T2IN)
unnamed: C4.1, U5.1 (C1+)
unnamed: C4.2, U5.3 (C1-)
unnamed: C8.1, U5.4 (C2+)
unnamed: C8.2, U5.5 (C2-)
unnamed: J3.3, U5.13 (R1IN)
unnamed: J3.7, U5.8 (R2IN)
unnamed: J3.2, U5.14 (T1OUT)
unnamed: J3.8, U5.7 (T2OUT)
unnamed: C9.1, U5.2 (VS+)
unnamed: C7.2, U5.6 (VS-)
PA0: U1.9 (A0); also elsewhere on the board
PA1: U1.10 (A1); also elsewhere on the board
PA2: U1.11 (A2); also elsewhere on the board
PA3: U1.12 (A3); also elsewhere on the board
PA4: U1.13 (A4); also elsewhere on the board
PA5: U1.14 (A5); also elsewhere on the board
PA6: U1.15 (A6); also elsewhere on the board
PA7: U1.16 (A7); also elsewhere on the board
PA8: U1.17 (A8); also elsewhere on the board
PA9: U1.18 (A9); also elsewhere on the board
PA10: U1.19 (A10); also elsewhere on the board
PA11: U1.20 (A11); also elsewhere on the board
PA12: U1.22 (A12); also elsewhere on the board
PA13: U1.23 (A13); also elsewhere on the board
PA14: U1.24 (A14); also elsewhere on the board
PA15: U1.25 (A15); also elsewhere on the board
PD0: U1.33 (D0); also elsewhere on the board
PD1: U1.32 (D1); also elsewhere on the board
PD2: U1.31 (D2); also elsewhere on the board
PD3: U1.30 (D3); also elsewhere on the board
PD4: U1.29 (D4); also elsewhere on the board
PD5: U1.28 (D5); also elsewhere on the board
PD6: U1.27 (D6); also elsewhere on the board
PD7: U1.26 (D7); also elsewhere on the board
PHI2: U2.25 (ϕ2), U3.27 (ϕ2); also elsewhere on the board
PP_A2: U2.4 (PA2); also elsewhere on the board
PP_A3: U2.5 (PA3); also elsewhere on the board
PP_A4: U2.6 (PA4); also elsewhere on the board
PP_A5: U2.7 (PA5); also elsewhere on the board
PP_A6: U2.8 (PA6); also elsewhere on the board
PP_A7: U2.9 (PA7); also elsewhere on the board
P_PHI0: U1.37 (ϕ0); also elsewhere on the board
P_PHI1_O: U1.3 (ϕ1)
P_PHI2_O: U1.39 (ϕ2)
P_RWB: U1.34 (R/~W); also elsewhere on the board
RAMB_M0: J1.9; also elsewhere on the board
RAMB_M1: J1.10; also elsewhere on the board
RAMB_M2: J1.11; also elsewhere on the board
RAMB_M3: J1.12; also elsewhere on the board
RDY: J4.1, U1.2 (RDY); also elsewhere on the board
RESB: RN1.2 (R1), U1.40 (~RES), U2.34 (~RES), U3.4 (~RES); also elsewhere on the board
RWB: U2.22 (R/~W), U3.28 (R/~W); also elsewhere on the board
RWB_M: J1.13, U7.29 (~WE); also elsewhere on the board
SER_CLK: U3.6 (XTAL1); also elsewhere on the board
SPI_A0: U2.13 (PB3), U4.1 (A0); also elsewhere on the board
SPI_A1: U2.14 (PB4), U4.2 (A1); also elsewhere on the board
SPI_A2: U2.15 (PB5), U4.3 (A2); also elsewhere on the board
SPI_A3: U2.16 (PB6), U4.4 (~E0); also elsewhere on the board
SPI_CLK: U2.10 (PB0); also elsewhere on the board
SPI_MISO: U2.17 (PB7); also elsewhere on the board
SPI_MOSI: U2.12 (PB2); also elsewhere on the board
SYNC: U1.7 (SYNC); also elsewhere on the board
T_M0: J1.5, U7.31 (A15); also elsewhere on the board
T_M1: J1.6, U7.2 (A16); also elsewhere on the board
T_M2: J1.7, U7.30 (A17); also elsewhere on the board
T_M3: J1.8, U7.1 (A18); also elsewhere on the board
VPB: U1.1 (~VP)
W0: U6.28 (A13); also elsewhere on the board
W1: U6.29 (A14); also elsewhere on the board
W2: U6.3 (A15); also elsewhere on the board
W3: U6.2 (A16); also elsewhere on the board
W4: U6.30 (A17); also elsewhere on the board
W5: U6.1 (A18); also elsewhere on the board
nBRC0_S: J1.18; also elsewhere on the board
nBRC1_S: J1.19; also elsewhere on the board
nBRC2_S: J1.20; also elsewhere on the board
nBRC3_S: J1.21; also elsewhere on the board
nBRC4_S: J1.22; also elsewhere on the board
nBRC5_S: J1.23; also elsewhere on the board
nBRC6_S: J1.24; also elsewhere on the board
nBRC7_S: J1.25; also elsewhere on the board
nBRC8_S: J1.26; also elsewhere on the board
nBRC9_S: J1.27; also elsewhere on the board
nBRC10_S: J1.28; also elsewhere on the board
nBRC11_S: J1.29; also elsewhere on the board
nBRC12_S: J1.30; also elsewhere on the board
nBRC13_S: J1.31; also elsewhere on the board
nBRC14_S: J1.32; also elsewhere on the board
nBROMD: RN1.6 (R5); also elsewhere on the board
nIOP0_S: U2.23 (~CS2); also elsewhere on the board
nIOP1_S: U3.3 (~CS2); also elsewhere on the board
nIRQ0: U2.21 (~IRQ); also elsewhere on the board
nIRQ1: U3.26 (~IRQ); also elsewhere on the board
nOSR_S: U6.22 (CE); also elsewhere on the board
nSPI_CS: U2.11 (PB1), U4.5 (~E1); also elsewhere on the board
nSPI_CS0: U4.15 (~Y0); also elsewhere on the board
nSPI_CS1: U4.14 (~Y1); also elsewhere on the board
nSPI_CS2: U4.13 (~Y2); also elsewhere on the board
nSPI_CS3: U4.12 (~Y3); also elsewhere on the board
nSPI_CS4: U4.11 (~Y4); also elsewhere on the board
nSPI_CS5: U4.10 (~Y5); also elsewhere on the board
nSPI_CS6: U4.9 (~Y6); also elsewhere on the board
nSPI_CS7: U4.7 (~Y7); also elsewhere on the board

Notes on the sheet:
TASK RAM
O/S ROM

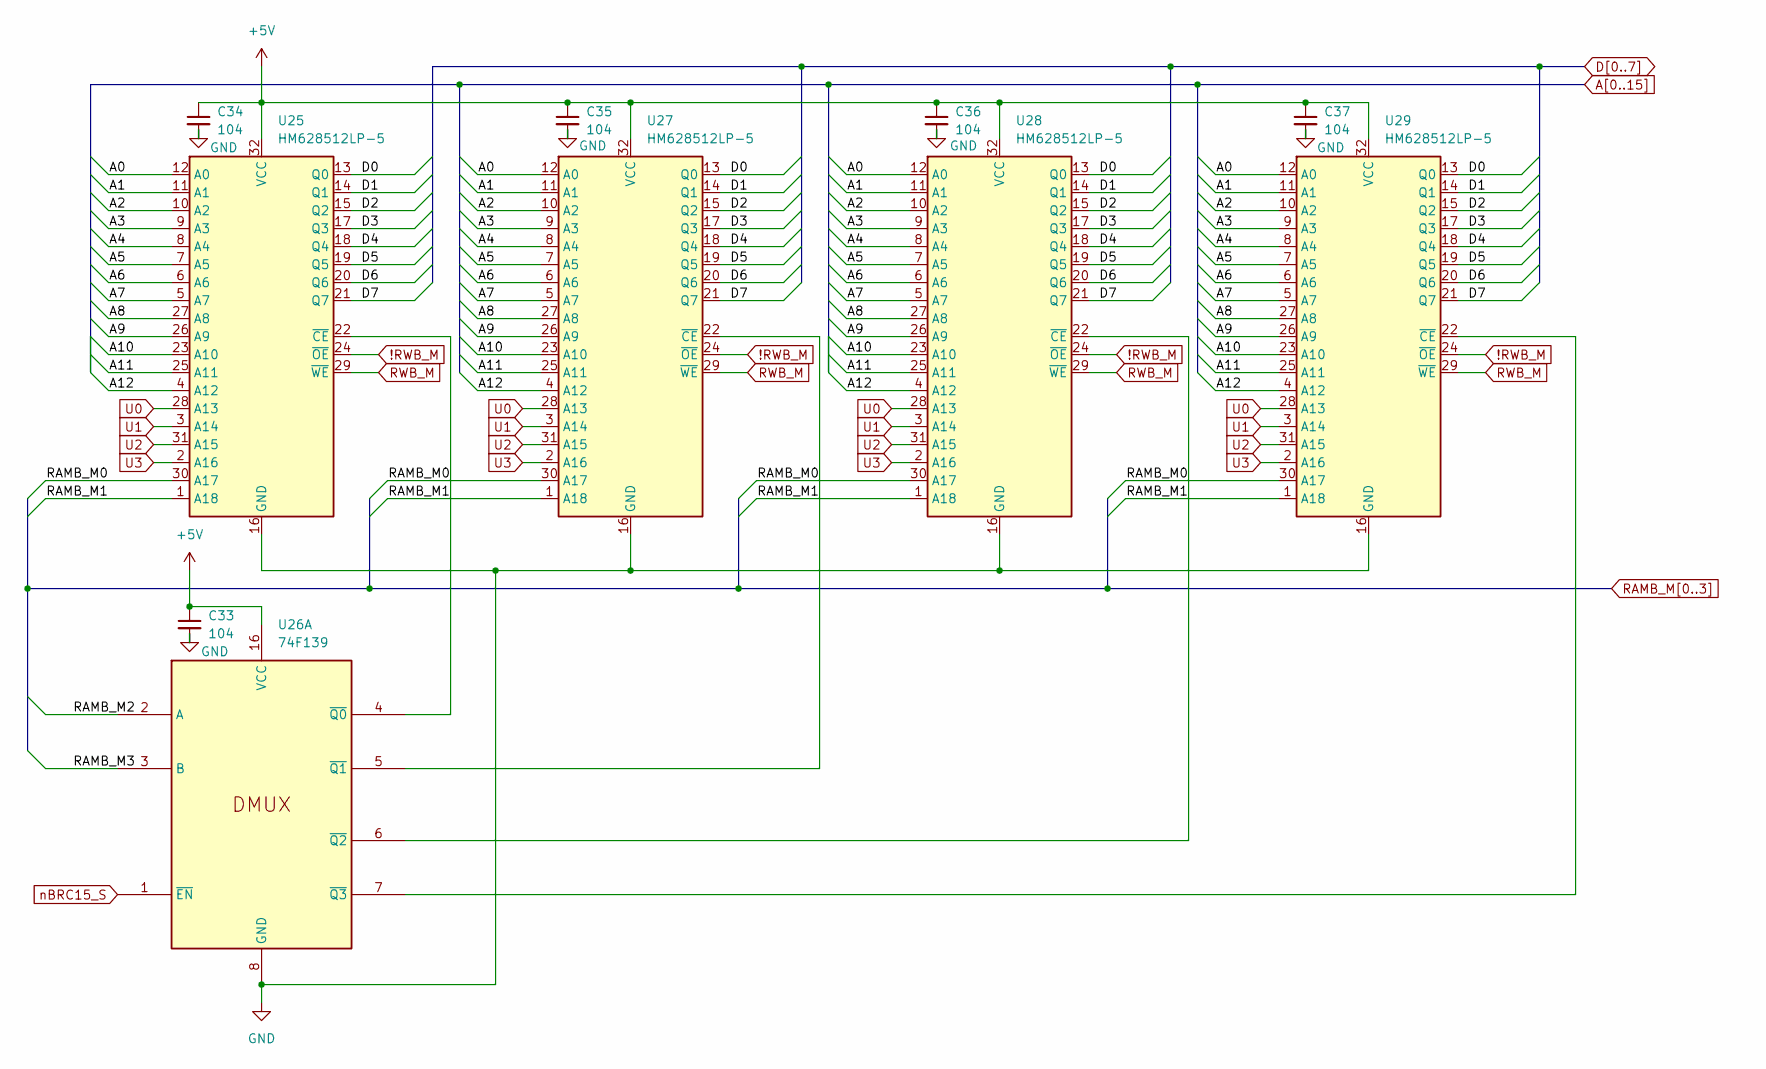
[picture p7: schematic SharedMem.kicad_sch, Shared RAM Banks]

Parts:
C33, C34, C35, C36, C37: 104; C_Disc_D5.0mm_W2.5mm_P5.00mm
U25, U27, U28, U29: HM628512LP-5; SOP-32_11.305x20.495mm_P1.27mm
U26: 74F139; DIP-16_W7.62mm_Socket_LongPads

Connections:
!RWB_M: U25.24 (~OE), U27.24 (~OE), U28.24 (~OE), U29.24 (~OE); also elsewhere on the board
+5V: C33.1, C34.1, C35.1, C36.1, C37.1, U25.32 (VCC), U26.16 (VCC), U27.32 (VCC), U28.32 (VCC), U29.32 (VCC); also elsewhere on the board
A0: U25.12 (A0), U27.12 (A0), U28.12 (A0), U29.12 (A0); also elsewhere on the board
A1: U25.11 (A1), U27.11 (A1), U28.11 (A1), U29.11 (A1); also elsewhere on the board
A2: U25.10 (A2), U27.10 (A2), U28.10 (A2), U29.10 (A2); also elsewhere on the board
A3: U25.9 (A3), U27.9 (A3), U28.9 (A3), U29.9 (A3); also elsewhere on the board
A4: U25.8 (A4), U27.8 (A4), U28.8 (A4), U29.8 (A4); also elsewhere on the board
A5: U25.7 (A5), U27.7 (A5), U28.7 (A5), U29.7 (A5); also elsewhere on the board
A6: U25.6 (A6), U27.6 (A6), U28.6 (A6), U29.6 (A6); also elsewhere on the board
A7: U25.5 (A7), U27.5 (A7), U28.5 (A7), U29.5 (A7); also elsewhere on the board
A8: U25.27 (A8), U27.27 (A8), U28.27 (A8), U29.27 (A8); also elsewhere on the board
A9: U25.26 (A9), U27.26 (A9), U28.26 (A9), U29.26 (A9); also elsewhere on the board
A10: U25.23 (A10), U27.23 (A10), U28.23 (A10), U29.23 (A10); also elsewhere on the board
A11: U25.25 (A11), U27.25 (A11), U28.25 (A11), U29.25 (A11); also elsewhere on the board
A12: U25.4 (A12), U27.4 (A12), U28.4 (A12), U29.4 (A12); also elsewhere on the board
D0: U25.13 (Q0), U27.13 (Q0), U28.13 (Q0), U29.13 (Q0); also elsewhere on the board
D1: U25.14 (Q1), U27.14 (Q1), U28.14 (Q1), U29.14 (Q1); also elsewhere on the board
D2: U25.15 (Q2), U27.15 (Q2), U28.15 (Q2), U29.15 (Q2); also elsewhere on the board
D3: U25.17 (Q3), U27.17 (Q3), U28.17 (Q3), U29.17 (Q3); also elsewhere on the board
D4: U25.18 (Q4), U27.18 (Q4), U28.18 (Q4), U29.18 (Q4); also elsewhere on the board
D5: U25.19 (Q5), U27.19 (Q5), U28.19 (Q5), U29.19 (Q5); also elsewhere on the board
D6: U25.20 (Q6), U27.20 (Q6), U28.20 (Q6), U29.20 (Q6); also elsewhere on the board
D7: U25.21 (Q7), U27.21 (Q7), U28.21 (Q7), U29.21 (Q7); also elsewhere on the board
GND: C33.2, C34.2, C35.2, C36.2, C37.2, U25.16 (GND), U26.8 (GND), U27.16 (GND), U28.16 (GND), U29.16 (GND); also elsewhere on the board
unnamed: U25.22 (~CE), U26.4 (~Q0)
unnamed: U26.5 (~Q1), U27.22 (~CE)
unnamed: U26.6 (~Q2), U28.22 (~CE)
unnamed: U26.7 (~Q3), U29.22 (~CE)
RAMB_M0: U25.30 (A17), U27.30 (A17), U28.30 (A17), U29.30 (A17); also elsewhere on the board
RAMB_M1: U25.1 (A18), U27.1 (A18), U28.1 (A18), U29.1 (A18); also elsewhere on the board
RAMB_M2: U26.2 (A); also elsewhere on the board
RAMB_M3: U26.3 (B); also elsewhere on the board
RWB_M: U25.29 (~WE), U27.29 (~WE), U28.29 (~WE), U29.29 (~WE); also elsewhere on the board
U0: U25.28 (A13), U27.28 (A13), U28.28 (A13), U29.28 (A13); also elsewhere on the board
U1: U25.3 (A14), U27.3 (A14), U28.3 (A14), U29.3 (A14); also elsewhere on the board
U2: U25.31 (A15), U27.31 (A15), U28.31 (A15), U29.31 (A15); also elsewhere on the board
U3: U25.2 (A16), U27.2 (A16), U28.2 (A16), U29.2 (A16); also elsewhere on the board
nBRC15_S: U26.1 (~EN); also elsewhere on the board

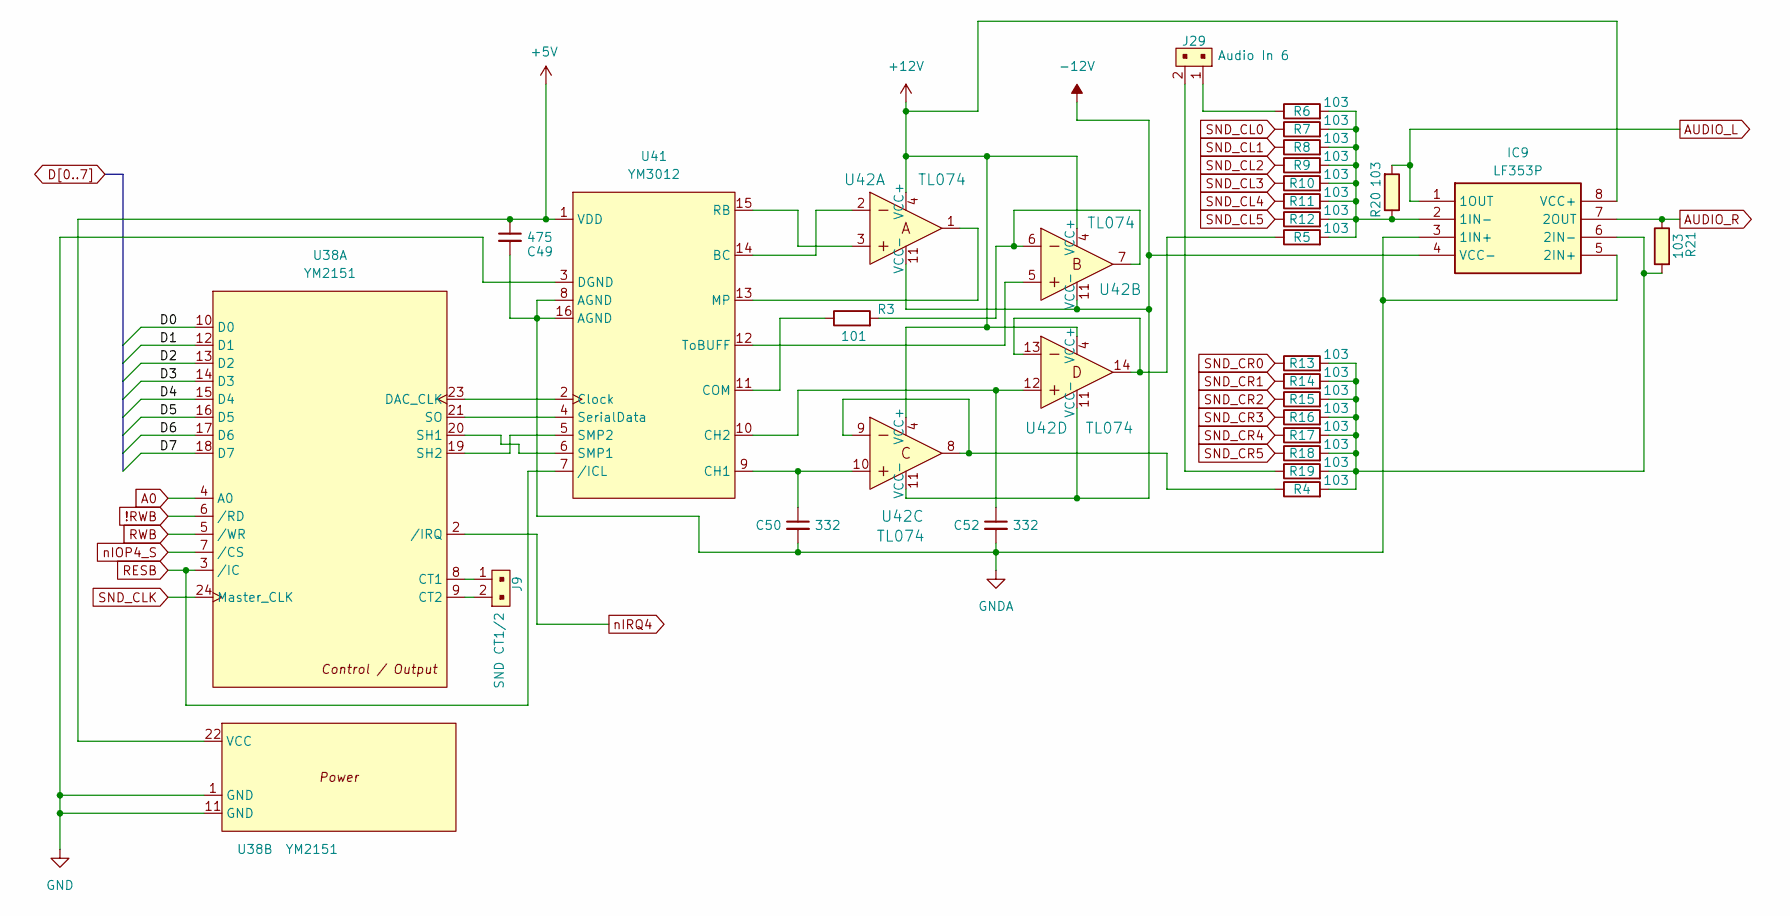
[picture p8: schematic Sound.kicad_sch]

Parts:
C49: 475; C_Disc_D5.0mm_W2.5mm_P2.50mm
C50, C52: 332; C_Disc_D5.0mm_W2.5mm_P2.50mm
IC9: LF353P; DIP-8_W7.62mm_Socket_LongPads; Mouser Part Number 595-LF353P
J9: SND CT1/2; PinHeader_2x01_P2.54mm_Vertical; MPN 22-23-2021; Digi-Key_PN WM4200-ND
J29: Audio In 6; PinHeader_2x01_P2.54mm_Vertical; MPN 22-23-2021; Digi-Key_PN WM4200-ND
R3: 101; R_Axial_DIN0204_L3.6mm_D1.6mm_P5.08mm_Horizontal
R4, R5, R6, R7, R8, R9, R10, R11, R12, R13, R14, R15, R16, R17, R18, R19, R20, R21: 103; R_Axial_DIN0204_L3.6mm_D1.6mm_P5.08mm_Horizontal
U38: YM2151; DIP-24_W15.24mm_Socket_LongPads
U41: YM3012; DIP-16_W7.62mm_Socket_LongPads
U42: TL074; DIP-14_W7.62mm_Socket_LongPads; MPN TL074CN; Digi-Key_PN 296-1777-ND

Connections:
!RWB: U38.6 (/RD); also elsewhere on the board
+5V: C49.1, U38.22 (VCC), U41.1 (VDD); also elsewhere on the board
+12V: IC9.8 (VCC+), U42.4 (VCC+); also elsewhere on the board
-12V: IC9.4 (VCC-), U42.11 (VCC-); also elsewhere on the board
A0: U38.4 (A0); also elsewhere on the board
AUDIO_L: IC9.1 (1OUT), R20.1; also elsewhere on the board
AUDIO_R: IC9.7 (2OUT), R21.2; also elsewhere on the board
D0: U38.10 (D0); also elsewhere on the board
D1: U38.12 (D1); also elsewhere on the board
D2: U38.13 (D2); also elsewhere on the board
D3: U38.14 (D3); also elsewhere on the board
D4: U38.15 (D4); also elsewhere on the board
D5: U38.16 (D5); also elsewhere on the board
D6: U38.17 (D6); also elsewhere on the board
D7: U38.18 (D7); also elsewhere on the board
GND: U38.1 (GND), U38.11 (GND), U41.3 (DGND); also elsewhere on the board
GNDA: C49.2, C50.2, C52.2, IC9.3 (1IN+), IC9.5 (2IN+), U41.8 (AGND), U41.16 (AGND); also elsewhere on the board
unnamed: IC9.2 (1IN-), R5.2, R6.2, R7.2, R8.2, R9.2, R10.2, R11.2, R12.2, R20.2
unnamed: IC9.6 (2IN-), R4.2, R13.2, R14.2, R15.2, R16.2, R17.2, R18.2, R19.2, R21.1
unnamed: J29.1, R6.1
unnamed: J29.2, R19.1
unnamed: R3.2, U42.6, U42.7
unnamed: R4.1, U42.8, U42.9
unnamed: R5.1, U42.13, U42.14
unnamed: J9.1, U38.8 (CT1)
unnamed: J9.2, U38.9 (CT2)
unnamed: U38.23 (DAC_CLK), U41.2 (Clock)
unnamed: U38.20 (SH1), U41.6 (SMP1)
unnamed: U38.19 (SH2), U41.5 (SMP2)
unnamed: U38.21 (SO), U41.4 (SerialData)
unnamed: U41.14 (BC), U42.2
unnamed: C50.1, U41.9 (CH1), U42.10
unnamed: C52.1, U41.10 (CH2), U42.12
unnamed: R3.1, U41.11 (COM)
unnamed: U41.13 (MP), U42.1
unnamed: U41.15 (RB), U42.3
unnamed: U41.12 (ToBUFF), U42.5
RESB: U38.3 (/IC), U41.7 (/ICL); also elsewhere on the board
RWB: U38.5 (/WR); also elsewhere on the board
SND_CL0: R7.1; also elsewhere on the board
SND_CL1: R8.1; also elsewhere on the board
SND_CL2: R9.1; also elsewhere on the board
SND_CL3: R10.1; also elsewhere on the board
SND_CL4: R11.1; also elsewhere on the board
SND_CL5: R12.1; also elsewhere on the board
SND_CLK: U38.24 (Master_CLK); also elsewhere on the board
SND_CR0: R13.1; also elsewhere on the board
SND_CR1: R14.1; also elsewhere on the board
SND_CR2: R15.1; also elsewhere on the board
SND_CR3: R16.1; also elsewhere on the board
SND_CR4: R17.1; also elsewhere on the board
SND_CR5: R18.1; also elsewhere on the board
nIOP4_S: U38.7 (/CS); also elsewhere on the board
nIRQ4: U38.2 (/IRQ); also elsewhere on the board

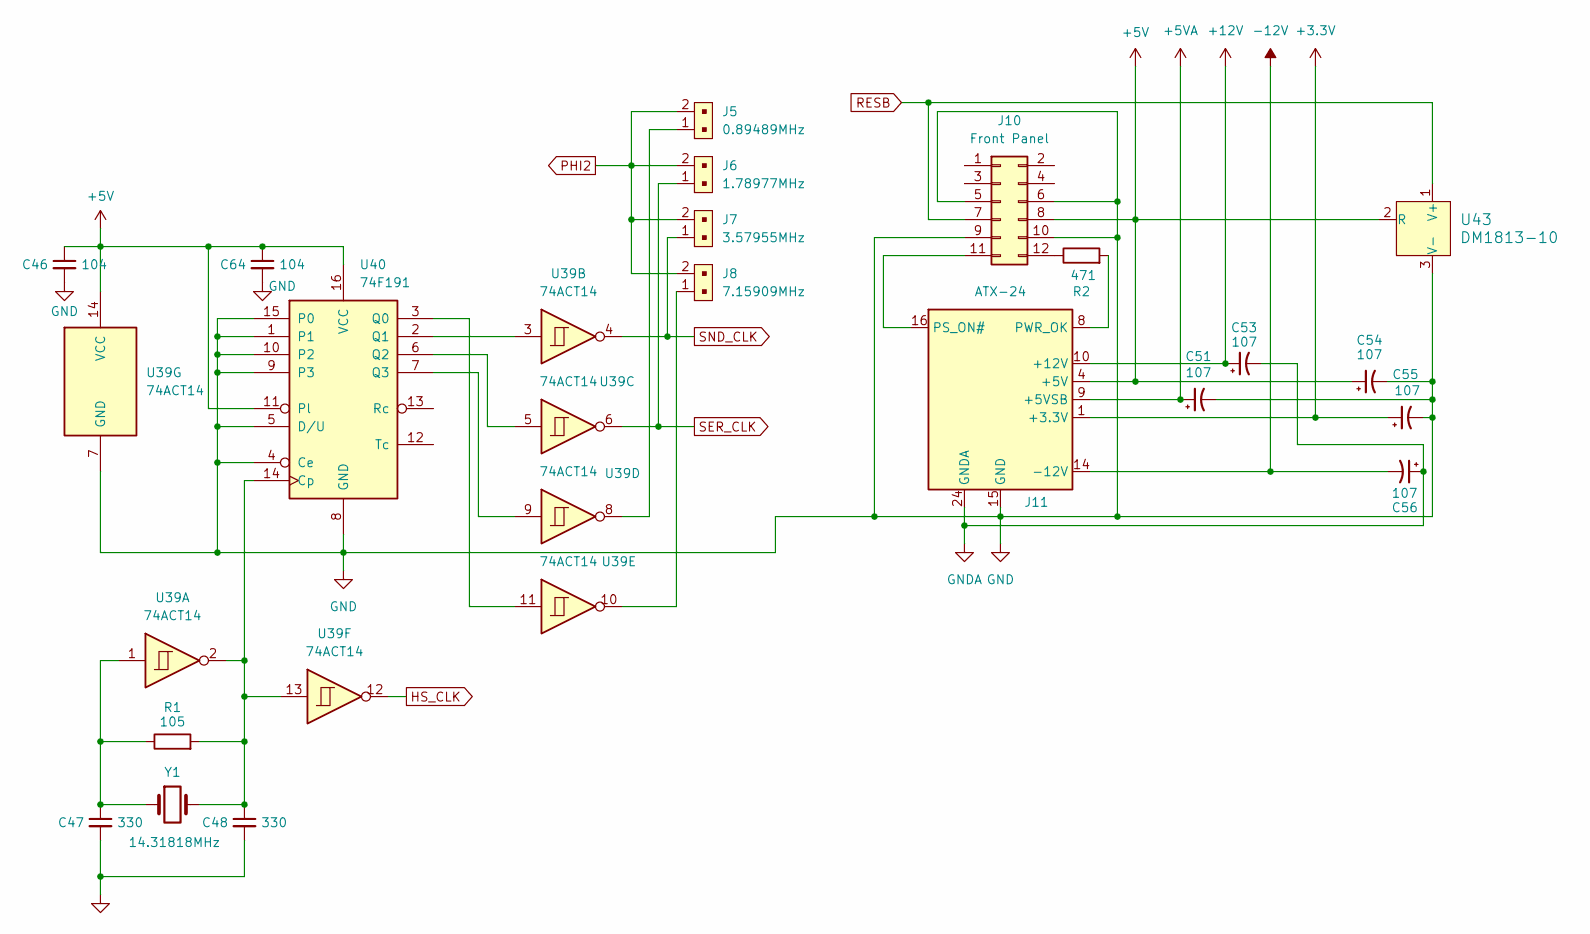
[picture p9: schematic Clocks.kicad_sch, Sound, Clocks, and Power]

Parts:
C46, C64: 104; C_Disc_D5.0mm_W2.5mm_P5.00mm
C47, C48: 330; C_Disc_D5.0mm_W2.5mm_P2.50mm
C51, C53, C54, C55, C56: 107; CP_Radial_D6.3mm_P2.50mm
J5: 0.89489MHz; PinHeader_2x01_P2.54mm_Vertical; MPN 22-23-2021; Digi-Key_PN WM4200-ND
J6: 1.78977MHz; PinHeader_2x01_P2.54mm_Vertical; MPN 22-23-2021; Digi-Key_PN WM4200-ND
J7: 3.57955MHz; PinHeader_2x01_P2.54mm_Vertical; MPN 22-23-2021; Digi-Key_PN WM4200-ND
J8: 7.15909MHz; PinHeader_2x01_P2.54mm_Vertical; MPN 22-23-2021; Digi-Key_PN WM4200-ND
J10: Front Panel; PinHeader_2x06_P2.54mm_Vertical
J11: ATX-24; Molex_Mini-Fit_Jr_5566-24A2_2x12_P4.20mm_Vertical
R1: 105; R_Axial_DIN0204_L3.6mm_D1.6mm_P5.08mm_Horizontal
R2: 471; R_Axial_DIN0204_L3.6mm_D1.6mm_P5.08mm_Horizontal
U39: 74ACT14; DIP-14_W7.62mm_Socket_LongPads
U40: 74F191; DIP-16_W7.62mm_Socket_LongPads
U43: DM1813-10; TO-92_Inline_Wide; MPN LM334Z/NOPB; Digi-Key_PN LM334ZNS/NOPB-ND
Y1: 14.31818MHz; Crystal_HC18-U_Vertical

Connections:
+3.3V: C55.1, J11.1 (+3.3V), J11.2 (+3.3V), J11.12 (+3.3V), J11.13 (+3.3V)
+5V: C46.1, C54.1, C64.1, J10.8, J11.4 (+5V), J11.6 (+5V), J11.21 (+5V), J11.22 (+5V), J11.23 (+5V), U39.14 (VCC), U40.11 (Pl), U40.16 (VCC), U43.2 (R); also elsewhere on the board
+5VA: C51.1, J11.9 (+5VSB)
+12V: C53.1, J11.10 (+12V), J11.11 (+12V); also elsewhere on the board
-12V: C56.2, J11.14 (-12V); also elsewhere on the board
GND: C46.2, C47.2, C48.2, C51.2, C54.2, C55.2, C64.2, J10.5, J10.6, J10.9, J10.10, J11.3 (GND), J11.5 (GND), J11.7 (GND), J11.15 (GND), J11.17 (GND), J11.18 (GND), J11.19 (GND), U39.7 (GND), U40.1, U40.4 (Ce), U40.5 (D/U), U40.8 (GND), U40.9 (P3), U40.10 (P2), U40.15 (P0), U43.3 (V-); also elsewhere on the board
GNDA: C53.2, C56.1, J11.24 (GNDA); also elsewhere on the board
HS_CLK: U39.12; also elsewhere on the board
unnamed: C47.1, R1.1, U39.1, Y1.1
unnamed: J5.1, U39.8
unnamed: J8.1, U39.10
unnamed: J10.11, J11.16 (PS_ON#)
unnamed: J10.12, R2.1
unnamed: J11.8 (PWR_OK), R2.2
unnamed: C48.1, R1.2, U39.2, U39.13, U40.14 (Cp), Y1.2
unnamed: U39.11, U40.3 (Q0)
unnamed: U39.3, U40.2 (Q1)
unnamed: U39.5, U40.6 (Q2)
unnamed: U39.9, U40.7 (Q3)
PHI2: J5.2, J6.2, J7.2, J8.2; also elsewhere on the board
RESB: J10.7, U43.1 (V+); also elsewhere on the board
SER_CLK: J6.1, U39.6; also elsewhere on the board
SND_CLK: J7.1, U39.4; also elsewhere on the board

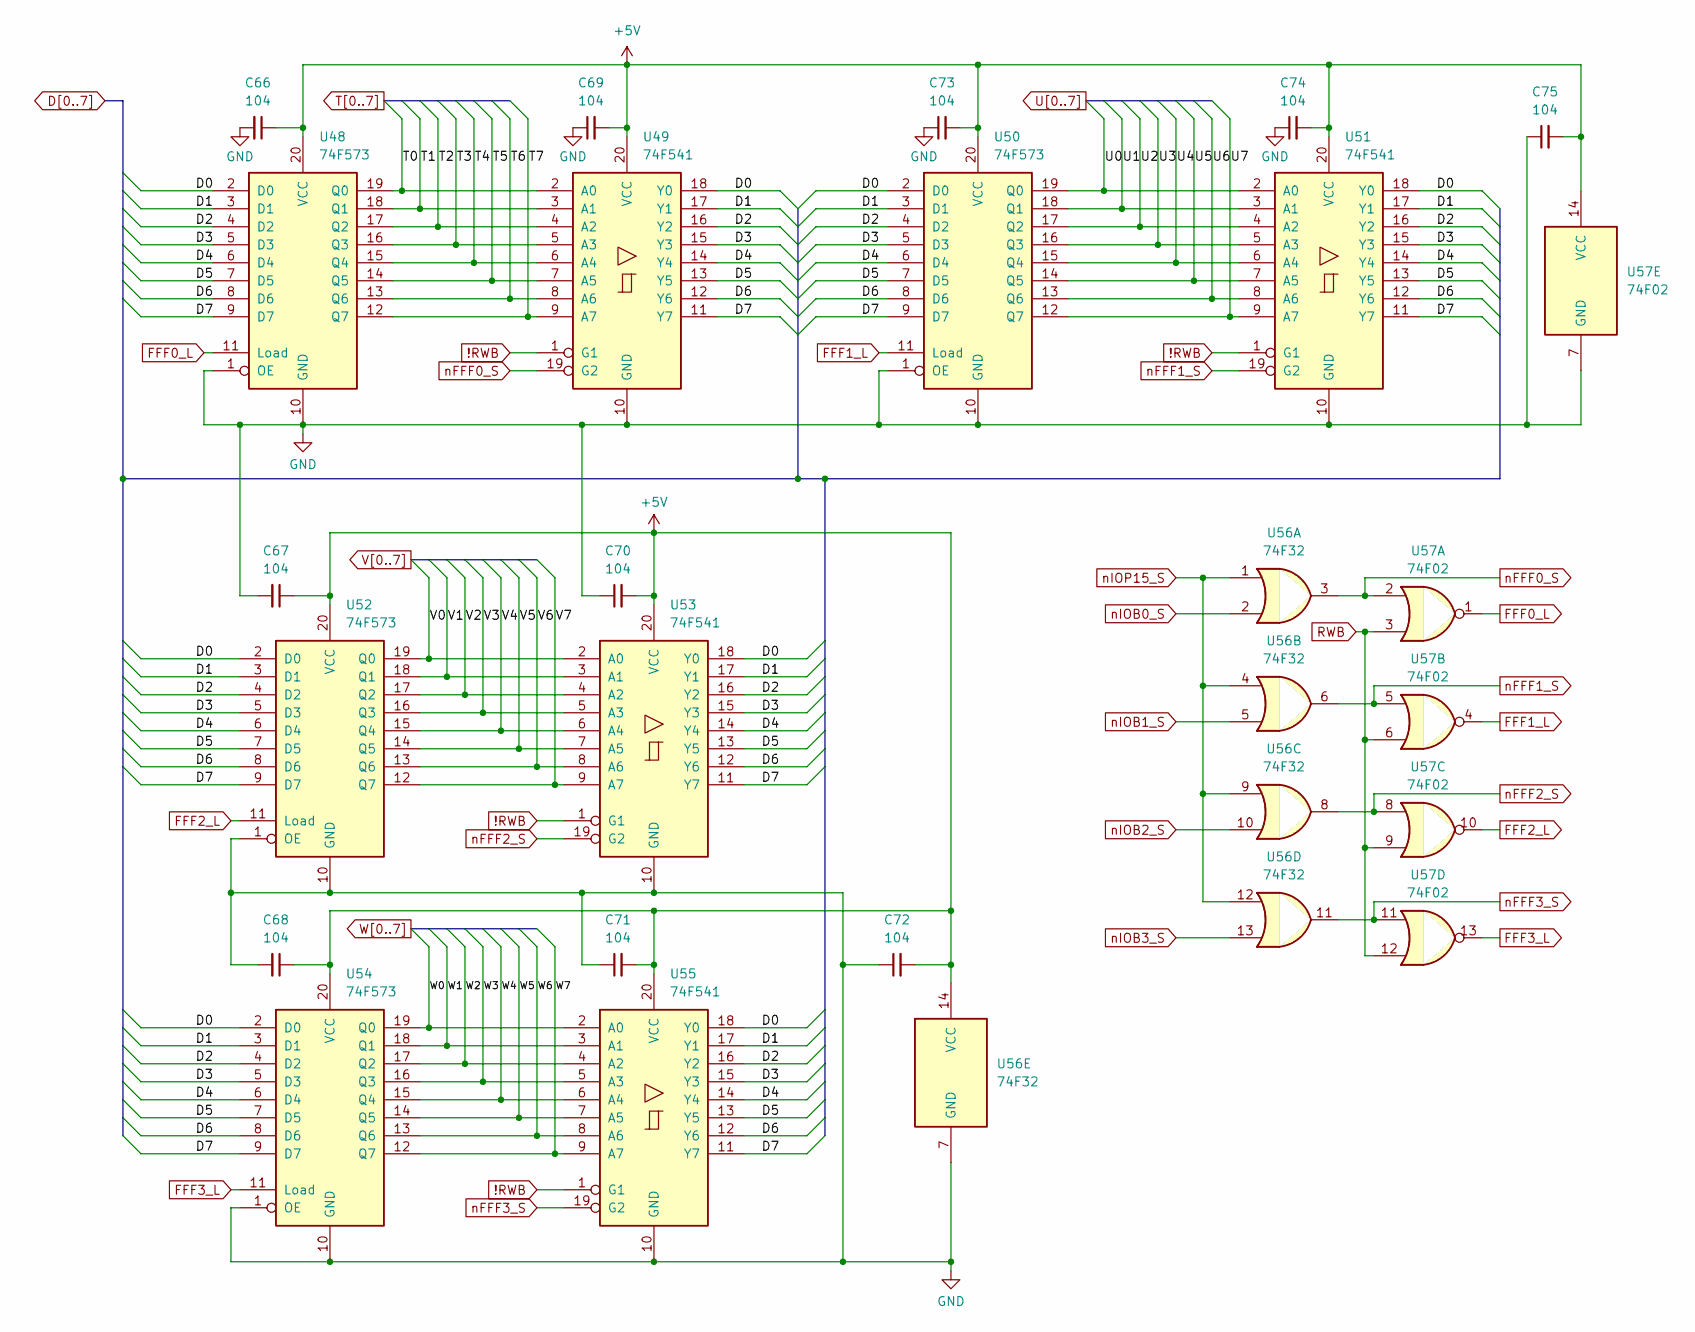
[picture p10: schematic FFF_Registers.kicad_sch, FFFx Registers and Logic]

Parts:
C66, C67, C68, C69, C70, C71, C72, C73, C74, C75: 104; C_Disc_D5.0mm_W2.5mm_P5.00mm
U48, U50, U52, U54: 74F573; DIP-20_W7.62mm_Socket_LongPads
U49, U51, U53, U55: 74F541; DIP-20_W7.62mm_Socket_LongPads
U56: 74F32; DIP-14_W7.62mm_Socket_LongPads
U57: 74F02; DIP-14_W7.62mm_Socket_LongPads

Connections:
!RWB: U49.1 (G1), U51.1 (G1), U53.1 (G1), U55.1 (G1); also elsewhere on the board
+5V: C66.1, C67.1, C68.1, C69.2, C70.2, C71.2, C72.2, C73.2, C74.2, C75.2, U48.20 (VCC), U49.20 (VCC), U50.20 (VCC), U51.20 (VCC), U52.20 (VCC), U53.20 (VCC), U54.20 (VCC), U55.20 (VCC), U56.14 (VCC), U57.14 (VCC); also elsewhere on the board
D0: U48.2 (D0), U49.18 (Y0), U50.2 (D0), U51.18 (Y0), U52.2 (D0), U53.18 (Y0), U54.2 (D0), U55.18 (Y0); also elsewhere on the board
D1: U48.3 (D1), U49.17 (Y1), U50.3 (D1), U51.17 (Y1), U52.3 (D1), U53.17 (Y1), U54.3 (D1), U55.17 (Y1); also elsewhere on the board
D2: U48.4 (D2), U49.16 (Y2), U50.4 (D2), U51.16 (Y2), U52.4 (D2), U53.16 (Y2), U54.4 (D2), U55.16 (Y2); also elsewhere on the board
D3: U48.5 (D3), U49.15 (Y3), U50.5 (D3), U51.15 (Y3), U52.5 (D3), U53.15 (Y3), U54.5 (D3), U55.15 (Y3); also elsewhere on the board
D4: U48.6 (D4), U49.14 (Y4), U50.6 (D4), U51.14 (Y4), U52.6 (D4), U53.14 (Y4), U54.6 (D4), U55.14 (Y4); also elsewhere on the board
D5: U48.7 (D5), U49.13 (Y5), U50.7 (D5), U51.13 (Y5), U52.7 (D5), U53.13 (Y5), U54.7 (D5), U55.13 (Y5); also elsewhere on the board
D6: U48.8 (D6), U49.12 (Y6), U50.8 (D6), U51.12 (Y6), U52.8 (D6), U53.12 (Y6), U54.8 (D6), U55.12 (Y6); also elsewhere on the board
D7: U48.9 (D7), U49.11 (Y7), U50.9 (D7), U51.11 (Y7), U52.9 (D7), U53.11 (Y7), U54.9 (D7), U55.11 (Y7); also elsewhere on the board
FFF0_L: U48.11 (Load), U57.1
FFF1_L: U50.11 (Load), U57.4
FFF2_L: U52.11 (Load), U57.10
FFF3_L: U54.11 (Load), U57.13
GND: C66.2, C67.2, C68.2, C69.1, C70.1, C71.1, C72.1, C73.1, C74.1, C75.1, U48.1 (OE), U48.10 (GND), U49.10 (GND), U50.1 (OE), U50.10 (GND), U51.10 (GND), U52.1 (OE), U52.10 (GND), U53.10 (GND), U54.1 (OE), U54.10 (GND), U55.10 (GND), U56.7 (GND), U57.7 (GND); also elsewhere on the board
RWB: U57.3, U57.6, U57.9, U57.12; also elsewhere on the board
T0: U48.19 (Q0), U49.2 (A0); also elsewhere on the board
T1: U48.18 (Q1), U49.3 (A1); also elsewhere on the board
T2: U48.17 (Q2), U49.4 (A2); also elsewhere on the board
T3: U48.16 (Q3), U49.5 (A3); also elsewhere on the board
T4: U48.15 (Q4), U49.6 (A4)
T5: U48.14 (Q5), U49.7 (A5)
T6: U48.13 (Q6), U49.8 (A6)
T7: U48.12 (Q7), U49.9 (A7)
U0: U50.19 (Q0), U51.2 (A0); also elsewhere on the board
U1: U50.18 (Q1), U51.3 (A1); also elsewhere on the board
U2: U50.17 (Q2), U51.4 (A2); also elsewhere on the board
U3: U50.16 (Q3), U51.5 (A3); also elsewhere on the board
U4: U50.15 (Q4), U51.6 (A4)
U5: U50.14 (Q5), U51.7 (A5)
U6: U50.13 (Q6), U51.8 (A6)
U7: U50.12 (Q7), U51.9 (A7)
V0: U52.19 (Q0), U53.2 (A0); also elsewhere on the board
V1: U52.18 (Q1), U53.3 (A1); also elsewhere on the board
V2: U52.17 (Q2), U53.4 (A2); also elsewhere on the board
V3: U52.16 (Q3), U53.5 (A3); also elsewhere on the board
V4: U52.15 (Q4), U53.6 (A4)
V5: U52.14 (Q5), U53.7 (A5)
V6: U52.13 (Q6), U53.8 (A6)
V7: U52.12 (Q7), U53.9 (A7)
W0: U54.19 (Q0), U55.2 (A0); also elsewhere on the board
W1: U54.18 (Q1), U55.3 (A1); also elsewhere on the board
W2: U54.17 (Q2), U55.4 (A2); also elsewhere on the board
W3: U54.16 (Q3), U55.5 (A3); also elsewhere on the board
W4: U54.15 (Q4), U55.6 (A4); also elsewhere on the board
W5: U54.14 (Q5), U55.7 (A5); also elsewhere on the board
W6: U54.13 (Q6), U55.8 (A6)
W7: U54.12 (Q7), U55.9 (A7)
nFFF0_S: U49.19 (G2), U56.3, U57.2
nFFF1_S: U51.19 (G2), U56.6, U57.5
nFFF2_S: U53.19 (G2), U56.8, U57.8
nFFF3_S: U55.19 (G2), U56.11, U57.11
nIOB0_S: U56.2; also elsewhere on the board
nIOB1_S: U56.5; also elsewhere on the board
nIOB2_S: U56.10; also elsewhere on the board
nIOB3_S: U56.13; also elsewhere on the board
nIOP15_S: U56.1, U56.4, U56.9, U56.12; also elsewhere on the board

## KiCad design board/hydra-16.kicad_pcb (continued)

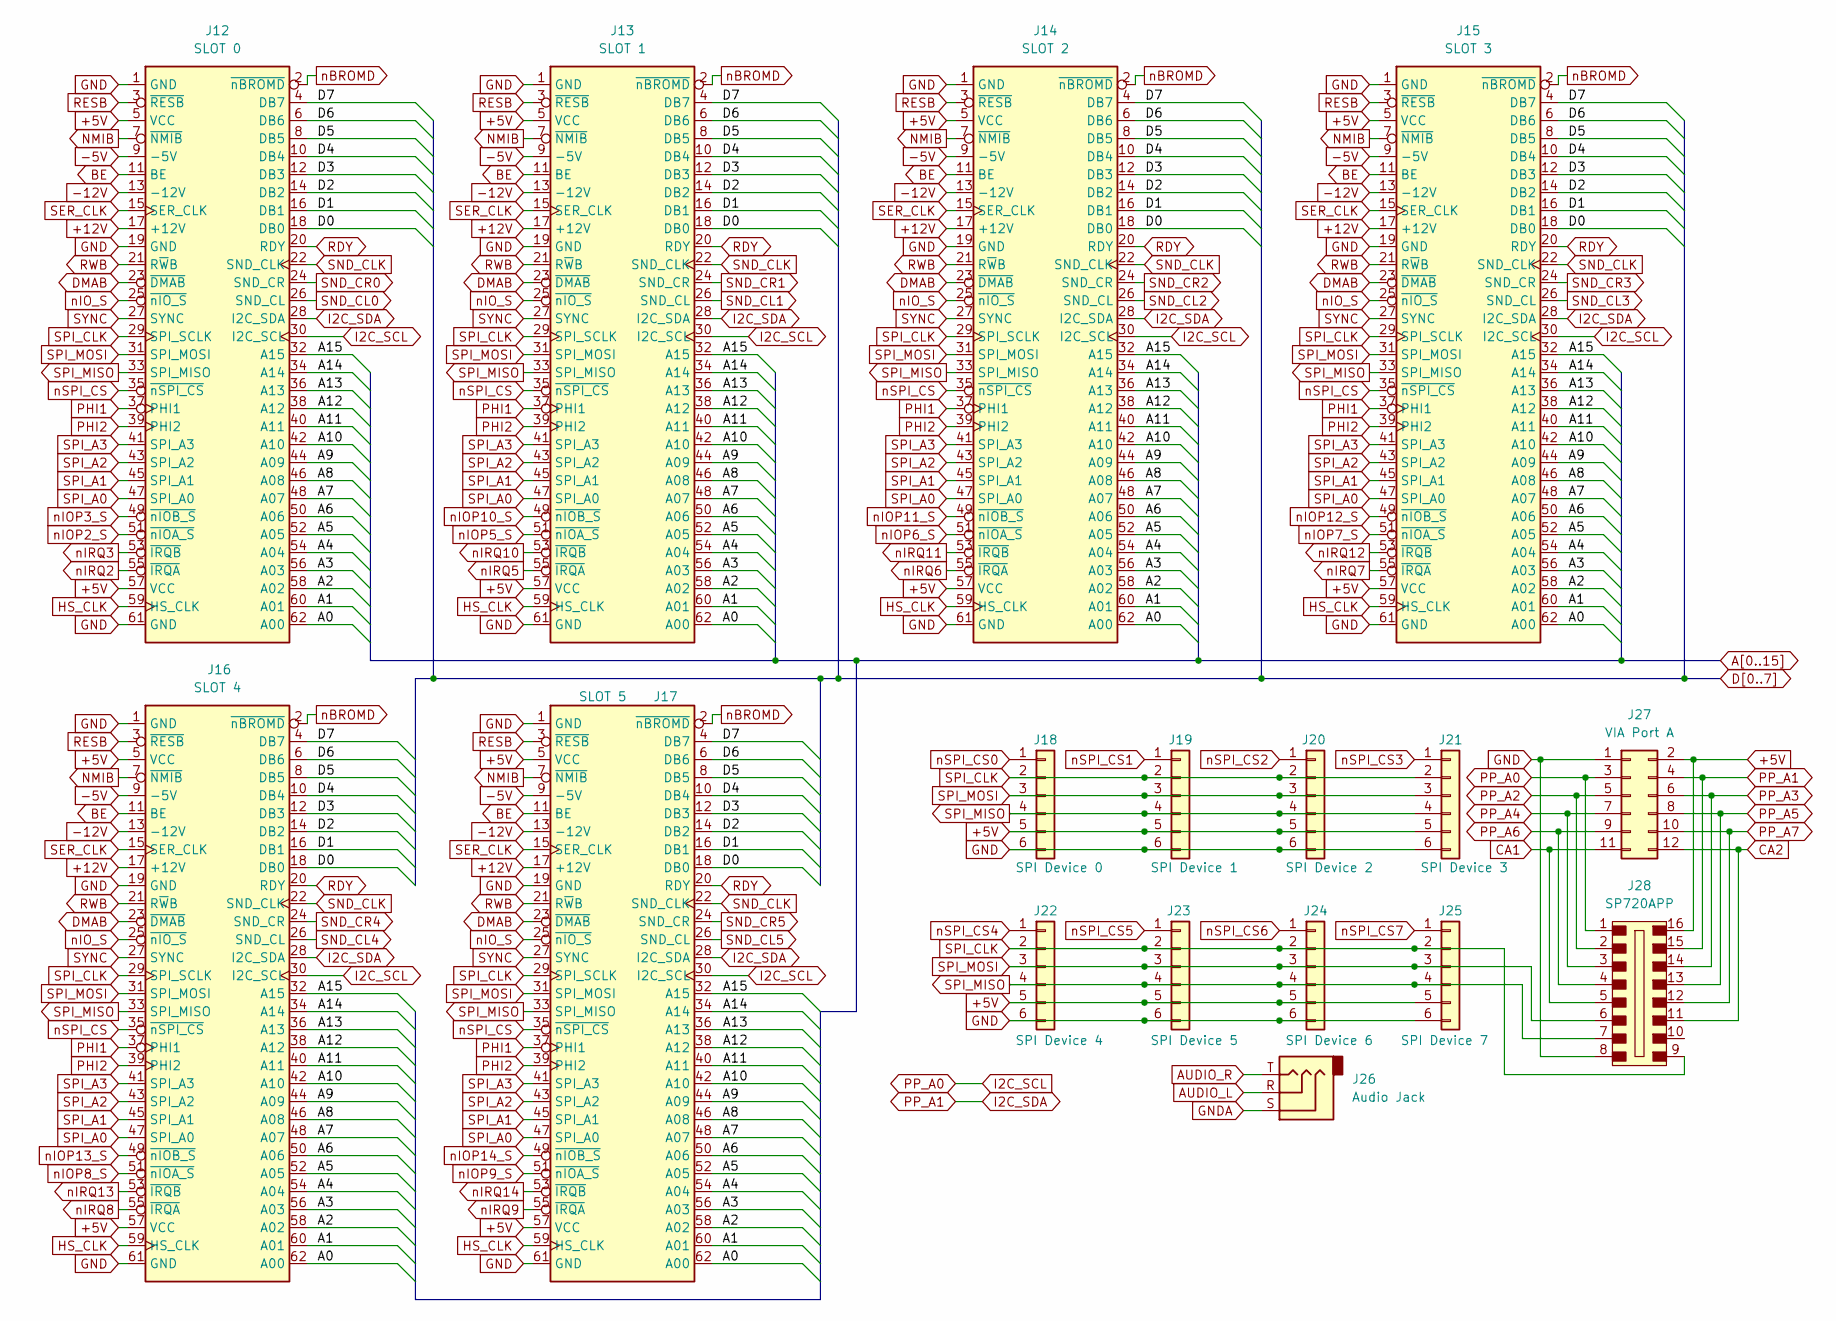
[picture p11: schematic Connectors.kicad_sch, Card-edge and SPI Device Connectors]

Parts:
J12: SLOT 0; TE_7-5530843-0
J13: SLOT 1; TE_7-5530843-0
J14: SLOT 2; TE_7-5530843-0
J15: SLOT 3; TE_7-5530843-0
J16: SLOT 4; TE_7-5530843-0
J17: SLOT 5; TE_7-5530843-0
J18: SPI Device 0; PinSocket_1x06_P2.54mm_Vertical
J19: SPI Device 1; PinSocket_1x06_P2.54mm_Vertical
J20: SPI Device 2; PinSocket_1x06_P2.54mm_Vertical
J21: SPI Device 3; PinSocket_1x06_P2.54mm_Vertical
J22: SPI Device 4; PinSocket_1x06_P2.54mm_Vertical
J23: SPI Device 5; PinSocket_1x06_P2.54mm_Vertical
J24: SPI Device 6; PinSocket_1x06_P2.54mm_Vertical
J25: SPI Device 7; PinSocket_1x06_P2.54mm_Vertical
J26: Audio Jack; Jack_3.5mm_CUI_SJ1-3525N_Horizontal
J27: VIA Port A; PinHeader_2x06_P2.54mm_Vertical
J28: SP720APP; DIP-16_W7.62mm_Socket_LongPads; MPN A 16-LC-TT; Digi-Key_PN AE9992-ND

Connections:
+5V: J12.5 (VCC), J12.57 (VCC), J13.5 (VCC), J13.57 (VCC), J14.5 (VCC), J14.57 (VCC), J15.5 (VCC), J15.57 (VCC), J16.5 (VCC), J16.57 (VCC), J17.5 (VCC), J17.57 (VCC), J18.5, J19.5, J20.5, J21.5, J22.5, J23.5, J24.5, J25.5, J27.2, J28.16; also elsewhere on the board
+12V: J12.17 (+12V), J13.17 (+12V), J14.17 (+12V), J15.17 (+12V), J16.17 (+12V), J17.17 (+12V); also elsewhere on the board
-5V: J12.9 (-5V), J13.9 (-5V), J14.9 (-5V), J15.9 (-5V), J16.9 (-5V), J17.9 (-5V)
-12V: J12.13 (-12V), J13.13 (-12V), J14.13 (-12V), J15.13 (-12V), J16.13 (-12V), J17.13 (-12V); also elsewhere on the board
A0: J12.62 (A00), J13.62 (A00), J14.62 (A00), J15.62 (A00), J16.62 (A00), J17.62 (A00); also elsewhere on the board
A1: J12.60 (A01), J13.60 (A01), J14.60 (A01), J15.60 (A01), J16.60 (A01), J17.60 (A01); also elsewhere on the board
A2: J12.58 (A02), J13.58 (A02), J14.58 (A02), J15.58 (A02), J16.58 (A02), J17.58 (A02); also elsewhere on the board
A3: J12.56 (A03), J13.56 (A03), J14.56 (A03), J15.56 (A03), J16.56 (A03), J17.56 (A03); also elsewhere on the board
A4: J12.54 (A04), J13.54 (A04), J14.54 (A04), J15.54 (A04), J16.54 (A04), J17.54 (A04); also elsewhere on the board
A5: J12.52 (A05), J13.52 (A05), J14.52 (A05), J15.52 (A05), J16.52 (A05), J17.52 (A05); also elsewhere on the board
A6: J12.50 (A06), J13.50 (A06), J14.50 (A06), J15.50 (A06), J16.50 (A06), J17.50 (A06); also elsewhere on the board
A7: J12.48 (A07), J13.48 (A07), J14.48 (A07), J15.48 (A07), J16.48 (A07), J17.48 (A07); also elsewhere on the board
A8: J12.46 (A08), J13.46 (A08), J14.46 (A08), J15.46 (A08), J16.46 (A08), J17.46 (A08); also elsewhere on the board
A9: J12.44 (A09), J13.44 (A09), J14.44 (A09), J15.44 (A09), J16.44 (A09), J17.44 (A09); also elsewhere on the board
A10: J12.42 (A10), J13.42 (A10), J14.42 (A10), J15.42 (A10), J16.42 (A10), J17.42 (A10); also elsewhere on the board
A11: J12.40 (A11), J13.40 (A11), J14.40 (A11), J15.40 (A11), J16.40 (A11), J17.40 (A11); also elsewhere on the board
A12: J12.38 (A12), J13.38 (A12), J14.38 (A12), J15.38 (A12), J16.38 (A12), J17.38 (A12); also elsewhere on the board
A13: J12.36 (A13), J13.36 (A13), J14.36 (A13), J15.36 (A13), J16.36 (A13), J17.36 (A13); also elsewhere on the board
A14: J12.34 (A14), J13.34 (A14), J14.34 (A14), J15.34 (A14), J16.34 (A14), J17.34 (A14); also elsewhere on the board
A15: J12.32 (A15), J13.32 (A15), J14.32 (A15), J15.32 (A15), J16.32 (A15), J17.32 (A15); also elsewhere on the board
AUDIO_L: J26.R; also elsewhere on the board
AUDIO_R: J26.T; also elsewhere on the board
BE: J12.11 (BE), J13.11 (BE), J14.11 (BE), J15.11 (BE), J16.11 (BE), J17.11 (BE); also elsewhere on the board
CA1: J27.11, J28.5; also elsewhere on the board
CA2: J27.12, J28.11; also elsewhere on the board
D0: J12.18 (DB0), J13.18 (DB0), J14.18 (DB0), J15.18 (DB0), J16.18 (DB0), J17.18 (DB0); also elsewhere on the board
D1: J12.16 (DB1), J13.16 (DB1), J14.16 (DB1), J15.16 (DB1), J16.16 (DB1), J17.16 (DB1); also elsewhere on the board
D2: J12.14 (DB2), J13.14 (DB2), J14.14 (DB2), J15.14 (DB2), J16.14 (DB2), J17.14 (DB2); also elsewhere on the board
D3: J12.12 (DB3), J13.12 (DB3), J14.12 (DB3), J15.12 (DB3), J16.12 (DB3), J17.12 (DB3); also elsewhere on the board
D4: J12.10 (DB4), J13.10 (DB4), J14.10 (DB4), J15.10 (DB4), J16.10 (DB4), J17.10 (DB4); also elsewhere on the board
D5: J12.8 (DB5), J13.8 (DB5), J14.8 (DB5), J15.8 (DB5), J16.8 (DB5), J17.8 (DB5); also elsewhere on the board
D6: J12.6 (DB6), J13.6 (DB6), J14.6 (DB6), J15.6 (DB6), J16.6 (DB6), J17.6 (DB6); also elsewhere on the board
D7: J12.4 (DB7), J13.4 (DB7), J14.4 (DB7), J15.4 (DB7), J16.4 (DB7), J17.4 (DB7); also elsewhere on the board
DMAB: J12.23 (~DMAB), J13.23 (~DMAB), J14.23 (~DMAB), J15.23 (~DMAB), J16.23 (~DMAB), J17.23 (~DMAB); also elsewhere on the board
GND: J12.1 (GND), J12.19 (GND), J12.61 (GND), J13.1 (GND), J13.19 (GND), J13.61 (GND), J14.1 (GND), J14.19 (GND), J14.61 (GND), J15.1 (GND), J15.19 (GND), J15.61 (GND), J16.1 (GND), J16.19 (GND), J16.61 (GND), J17.1 (GND), J17.19 (GND), J17.61 (GND), J18.6, J19.6, J20.6, J21.6, J22.6, J23.6, J24.6, J25.6, J27.1, J28.8; also elsewhere on the board
GNDA: J26.S; also elsewhere on the board
HS_CLK: J12.59 (HS_CLK), J13.59 (HS_CLK), J14.59 (HS_CLK), J15.59 (HS_CLK), J16.59 (HS_CLK), J17.59 (HS_CLK); also elsewhere on the board
I2C_SCL: J12.30 (I2C_SCL), J13.30 (I2C_SCL), J14.30 (I2C_SCL), J15.30 (I2C_SCL), J16.30 (I2C_SCL), J17.30 (I2C_SCL), J27.3, J28.1; also elsewhere on the board
I2C_SDA: J12.28 (I2C_SDA), J13.28 (I2C_SDA), J14.28 (I2C_SDA), J15.28 (I2C_SDA), J16.28 (I2C_SDA), J17.28 (I2C_SDA), J27.4, J28.15; also elsewhere on the board
NMIB: J12.7 (~NMIB), J13.7 (~NMIB), J14.7 (~NMIB), J15.7 (~NMIB), J16.7 (~NMIB), J17.7 (~NMIB); also elsewhere on the board
PHI1: J12.37 (PHI1), J13.37 (PHI1), J14.37 (PHI1), J15.37 (PHI1), J16.37 (PHI1), J17.37 (PHI1); also elsewhere on the board
PHI2: J12.39 (PHI2), J13.39 (PHI2), J14.39 (PHI2), J15.39 (PHI2), J16.39 (PHI2), J17.39 (PHI2); also elsewhere on the board
PP_A2: J27.5, J28.2; also elsewhere on the board
PP_A3: J27.6, J28.14; also elsewhere on the board
PP_A4: J27.7, J28.3; also elsewhere on the board
PP_A5: J27.8, J28.13; also elsewhere on the board
PP_A6: J27.9, J28.4; also elsewhere on the board
PP_A7: J27.10, J28.12; also elsewhere on the board
RDY: J12.20 (RDY), J13.20 (RDY), J14.20 (RDY), J15.20 (RDY), J16.20 (RDY), J17.20 (RDY); also elsewhere on the board
RESB: J12.3 (~RESB), J13.3 (~RESB), J14.3 (~RESB), J15.3 (~RESB), J16.3 (~RESB), J17.3 (~RESB); also elsewhere on the board
RWB: J12.21 (R~WB), J13.21 (R~WB), J14.21 (R~WB), J15.21 (R~WB), J16.21 (R~WB), J17.21 (R~WB); also elsewhere on the board
SER_CLK: J12.15 (SER_CLK), J13.15 (SER_CLK), J14.15 (SER_CLK), J15.15 (SER_CLK), J16.15 (SER_CLK), J17.15 (SER_CLK); also elsewhere on the board
SND_CL0: J12.26 (SND_CL); also elsewhere on the board
SND_CL1: J13.26 (SND_CL); also elsewhere on the board
SND_CL2: J14.26 (SND_CL); also elsewhere on the board
SND_CL3: J15.26 (SND_CL); also elsewhere on the board
SND_CL4: J16.26 (SND_CL); also elsewhere on the board
SND_CL5: J17.26 (SND_CL); also elsewhere on the board
SND_CLK: J12.22 (SND_CLK), J13.22 (SND_CLK), J14.22 (SND_CLK), J15.22 (SND_CLK), J16.22 (SND_CLK), J17.22 (SND_CLK); also elsewhere on the board
SND_CR0: J12.24 (SND_CR); also elsewhere on the board
SND_CR1: J13.24 (SND_CR); also elsewhere on the board
SND_CR2: J14.24 (SND_CR); also elsewhere on the board
SND_CR3: J15.24 (SND_CR); also elsewhere on the board
SND_CR4: J16.24 (SND_CR); also elsewhere on the board
SND_CR5: J17.24 (SND_CR); also elsewhere on the board
SPI_A0: J12.47 (SPI_A0), J13.47 (SPI_A0), J14.47 (SPI_A0), J15.47 (SPI_A0), J16.47 (SPI_A0), J17.47 (SPI_A0); also elsewhere on the board
SPI_A1: J12.45 (SPI_A1), J13.45 (SPI_A1), J14.45 (SPI_A1), J15.45 (SPI_A1), J16.45 (SPI_A1), J17.45 (SPI_A1); also elsewhere on the board
SPI_A2: J12.43 (SPI_A2), J13.43 (SPI_A2), J14.43 (SPI_A2), J15.43 (SPI_A2), J16.43 (SPI_A2), J17.43 (SPI_A2); also elsewhere on the board
SPI_A3: J12.41 (SPI_A3), J13.41 (SPI_A3), J14.41 (SPI_A3), J15.41 (SPI_A3), J16.41 (SPI_A3), J17.41 (SPI_A3); also elsewhere on the board
SPI_CLK: J12.29 (SPI_SCLK), J13.29 (SPI_SCLK), J14.29 (SPI_SCLK), J15.29 (SPI_SCLK), J16.29 (SPI_SCLK), J17.29 (SPI_SCLK), J18.2, J19.2, J20.2, J21.2, J22.2, J23.2, J24.2, J25.2, J28.9; also elsewhere on the board
SPI_MISO: J12.33 (SPI_MISO), J13.33 (SPI_MISO), J14.33 (SPI_MISO), J15.33 (SPI_MISO), J16.33 (SPI_MISO), J17.33 (SPI_MISO), J18.4, J19.4, J20.4, J21.4, J22.4, J23.4, J24.4, J25.4, J28.7; also elsewhere on the board
SPI_MOSI: J12.31 (SPI_MOSI), J13.31 (SPI_MOSI), J14.31 (SPI_MOSI), J15.31 (SPI_MOSI), J16.31 (SPI_MOSI), J17.31 (SPI_MOSI), J18.3, J19.3, J20.3, J21.3, J22.3, J23.3, J24.3, J25.3, J28.6; also elsewhere on the board
SYNC: J12.27 (SYNC), J13.27 (SYNC), J14.27 (SYNC), J15.27 (SYNC), J16.27 (SYNC), J17.27 (SYNC); also elsewhere on the board
nBROMD: J12.2 (~nBROMD), J13.2 (~nBROMD), J14.2 (~nBROMD), J15.2 (~nBROMD), J16.2 (~nBROMD), J17.2 (~nBROMD); also elsewhere on the board
nIOP2_S: J12.51 (~nIOA_S); also elsewhere on the board
nIOP3_S: J12.49 (~nIOB_S); also elsewhere on the board
nIOP5_S: J13.51 (~nIOA_S); also elsewhere on the board
nIOP6_S: J14.51 (~nIOA_S); also elsewhere on the board
nIOP7_S: J15.51 (~nIOA_S); also elsewhere on the board
nIOP8_S: J16.51 (~nIOA_S); also elsewhere on the board
nIOP9_S: J17.51 (~nIOA_S); also elsewhere on the board
nIOP10_S: J13.49 (~nIOB_S); also elsewhere on the board
nIOP11_S: J14.49 (~nIOB_S); also elsewhere on the board
nIOP12_S: J15.49 (~nIOB_S); also elsewhere on the board
nIOP13_S: J16.49 (~nIOB_S); also elsewhere on the board
nIOP14_S: J17.49 (~nIOB_S); also elsewhere on the board
nIO_S: J12.25 (~nIO_S), J13.25 (~nIO_S), J14.25 (~nIO_S), J15.25 (~nIO_S), J16.25 (~nIO_S), J17.25 (~nIO_S); also elsewhere on the board
nIRQ2: J12.55 (~IRQA); also elsewhere on the board
nIRQ3: J12.53 (~IRQB); also elsewhere on the board
nIRQ5: J13.55 (~IRQA); also elsewhere on the board
nIRQ6: J14.55 (~IRQA); also elsewhere on the board
nIRQ7: J15.55 (~IRQA); also elsewhere on the board
nIRQ8: J16.55 (~IRQA); also elsewhere on the board
nIRQ9: J17.55 (~IRQA); also elsewhere on the board
nIRQ10: J13.53 (~IRQB); also elsewhere on the board
nIRQ11: J14.53 (~IRQB); also elsewhere on the board
nIRQ12: J15.53 (~IRQB); also elsewhere on the board
nIRQ13: J16.53 (~IRQB); also elsewhere on the board
nIRQ14: J17.53 (~IRQB); also elsewhere on the board
nSPI_CS: J12.35 (~nSPI_CS), J13.35 (~nSPI_CS), J14.35 (~nSPI_CS), J15.35 (~nSPI_CS), J16.35 (~nSPI_CS), J17.35 (~nSPI_CS); also elsewhere on the board
nSPI_CS0: J18.1; also elsewhere on the board
nSPI_CS1: J19.1; also elsewhere on the board
nSPI_CS2: J20.1; also elsewhere on the board
nSPI_CS3: J21.1; also elsewhere on the board
nSPI_CS4: J22.1; also elsewhere on the board
nSPI_CS5: J23.1; also elsewhere on the board
nSPI_CS6: J24.1; also elsewhere on the board
nSPI_CS7: J25.1; also elsewhere on the board

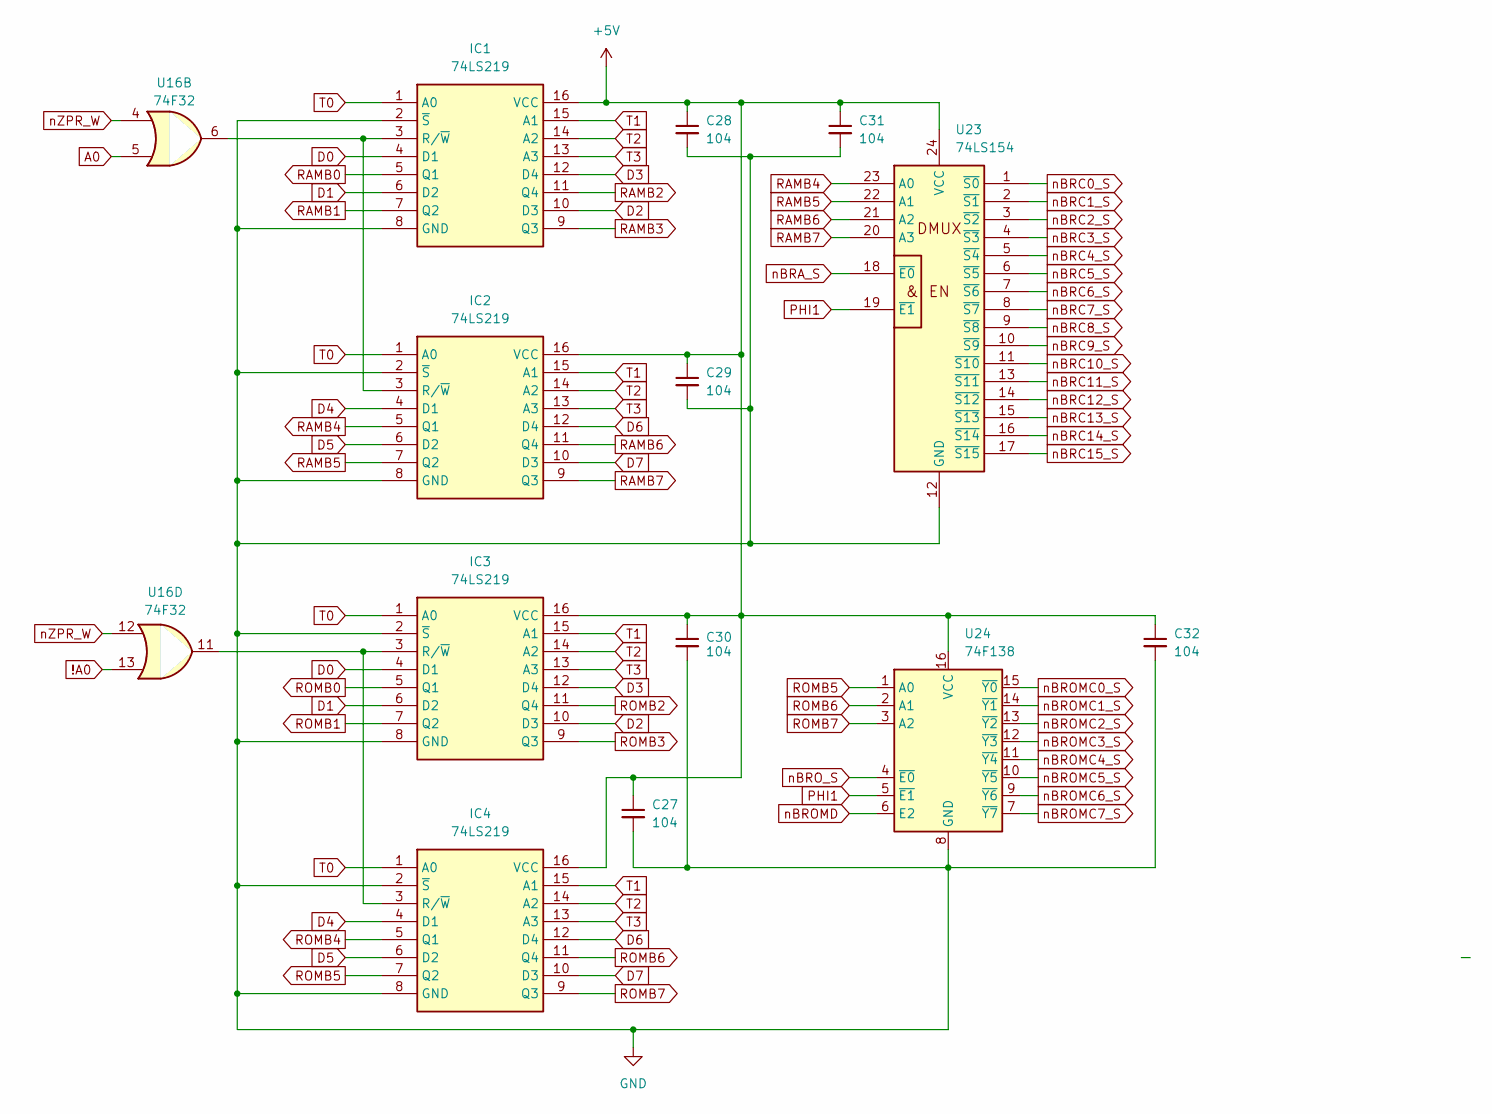
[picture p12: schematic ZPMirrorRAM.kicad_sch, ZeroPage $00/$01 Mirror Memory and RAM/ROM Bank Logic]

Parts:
C27, C28, C29, C30, C31, C32: 104; C_Disc_D5.0mm_W2.5mm_P5.00mm
IC1, IC2, IC3, IC4: 74LS219; DIP-16_W7.62mm_Socket_LongPads; Manufacturer_Part_Number SN74LS219AN
U16: 74F32; DIP-14_W7.62mm_Socket_LongPads
U23: 74LS154; DIP-24_W15.24mm_Socket_LongPads
U24: 74F138; DIP-16_W7.62mm_Socket_LongPads

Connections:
!A0: U16.13; also elsewhere on the board
+5V: C27.1, C28.1, C29.1, C30.1, C31.1, C32.1, IC1.16 (VCC), IC2.16 (VCC), IC3.16 (VCC), IC4.16 (VCC), U23.24 (VCC), U24.16 (VCC); also elsewhere on the board
A0: U16.5; also elsewhere on the board
D0: IC1.4 (D1), IC3.4 (D1); also elsewhere on the board
D1: IC1.6 (D2), IC3.6 (D2); also elsewhere on the board
D2: IC1.10 (D3), IC3.10 (D3); also elsewhere on the board
D3: IC1.12 (D4), IC3.12 (D4); also elsewhere on the board
D4: IC2.4 (D1), IC4.4 (D1); also elsewhere on the board
D5: IC2.6 (D2), IC4.6 (D2); also elsewhere on the board
D6: IC2.12 (D4), IC4.12 (D4); also elsewhere on the board
D7: IC2.10 (D3), IC4.10 (D3); also elsewhere on the board
GND: C27.2, C28.2, C29.2, C30.2, C31.2, C32.2, IC1.2 (~S), IC1.8 (GND), IC2.2 (~S), IC2.8 (GND), IC3.2 (~S), IC3.8 (GND), IC4.2 (~S), IC4.8 (GND), U23.12 (GND), U24.8 (GND); also elsewhere on the board
unnamed: IC1.3 (R/~W), IC2.3 (R/~W), U16.6
unnamed: IC3.3 (R/~W), IC4.3 (R/~W), U16.11
PHI1: U23.19 (~E1), U24.5 (~E1); also elsewhere on the board
RAMB0: IC1.5 (Q1); also elsewhere on the board
RAMB1: IC1.7 (Q2); also elsewhere on the board
RAMB2: IC1.11 (Q4); also elsewhere on the board
RAMB3: IC1.9 (Q3); also elsewhere on the board
RAMB4: IC2.5 (Q1), U23.23 (A0)
RAMB5: IC2.7 (Q2), U23.22 (A1)
RAMB6: IC2.11 (Q4), U23.21 (A2)
RAMB7: IC2.9 (Q3), U23.20 (A3)
ROMB0: IC3.5 (Q1); also elsewhere on the board
ROMB1: IC3.7 (Q2); also elsewhere on the board
ROMB2: IC3.11 (Q4); also elsewhere on the board
ROMB3: IC3.9 (Q3); also elsewhere on the board
ROMB4: IC4.5 (Q1); also elsewhere on the board
ROMB5: IC4.7 (Q2), U24.1 (A0)
ROMB6: IC4.11 (Q4), U24.2 (A1)
ROMB7: IC4.9 (Q3), U24.3 (A2)
T0: IC1.1 (A0), IC2.1 (A0), IC3.1 (A0), IC4.1 (A0); also elsewhere on the board
T1: IC1.15 (A1), IC2.15 (A1), IC3.15 (A1), IC4.15 (A1); also elsewhere on the board
T2: IC1.14 (A2), IC2.14 (A2), IC3.14 (A2), IC4.14 (A2); also elsewhere on the board
T3: IC1.13 (A3), IC2.13 (A3), IC3.13 (A3), IC4.13 (A3); also elsewhere on the board
nBRA_S: U23.18 (~E0); also elsewhere on the board
nBRC0_S: U23.1 (~S0); also elsewhere on the board
nBRC1_S: U23.2 (~S1); also elsewhere on the board
nBRC2_S: U23.3 (~S2); also elsewhere on the board
nBRC3_S: U23.4 (~S3); also elsewhere on the board
nBRC4_S: U23.5 (~S4); also elsewhere on the board
nBRC5_S: U23.6 (~S5); also elsewhere on the board
nBRC6_S: U23.7 (~S6); also elsewhere on the board
nBRC7_S: U23.8 (~S7); also elsewhere on the board
nBRC8_S: U23.9 (~S8); also elsewhere on the board
nBRC9_S: U23.10 (~S9); also elsewhere on the board
nBRC10_S: U23.11 (~S10); also elsewhere on the board
nBRC11_S: U23.13 (~S11); also elsewhere on the board
nBRC12_S: U23.14 (~S12); also elsewhere on the board
nBRC13_S: U23.15 (~S13); also elsewhere on the board
nBRC14_S: U23.16 (~S14); also elsewhere on the board
nBRC15_S: U23.17 (~S15); also elsewhere on the board
nBROMC0_S: U24.15 (~Y0); also elsewhere on the board
nBROMC1_S: U24.14 (~Y1); also elsewhere on the board
nBROMC2_S: U24.13 (~Y2); also elsewhere on the board
nBROMC3_S: U24.12 (~Y3); also elsewhere on the board
nBROMC4_S: U24.11 (~Y4); also elsewhere on the board
nBROMC5_S: U24.10 (~Y5); also elsewhere on the board
nBROMC6_S: U24.9 (~Y6); also elsewhere on the board
nBROMC7_S: U24.7 (~Y7); also elsewhere on the board
nBROMD: U24.6 (E2); also elsewhere on the board
nBRO_S: U24.4 (~E0); also elsewhere on the board
nZPR_W: U16.4, U16.12; also elsewhere on the board

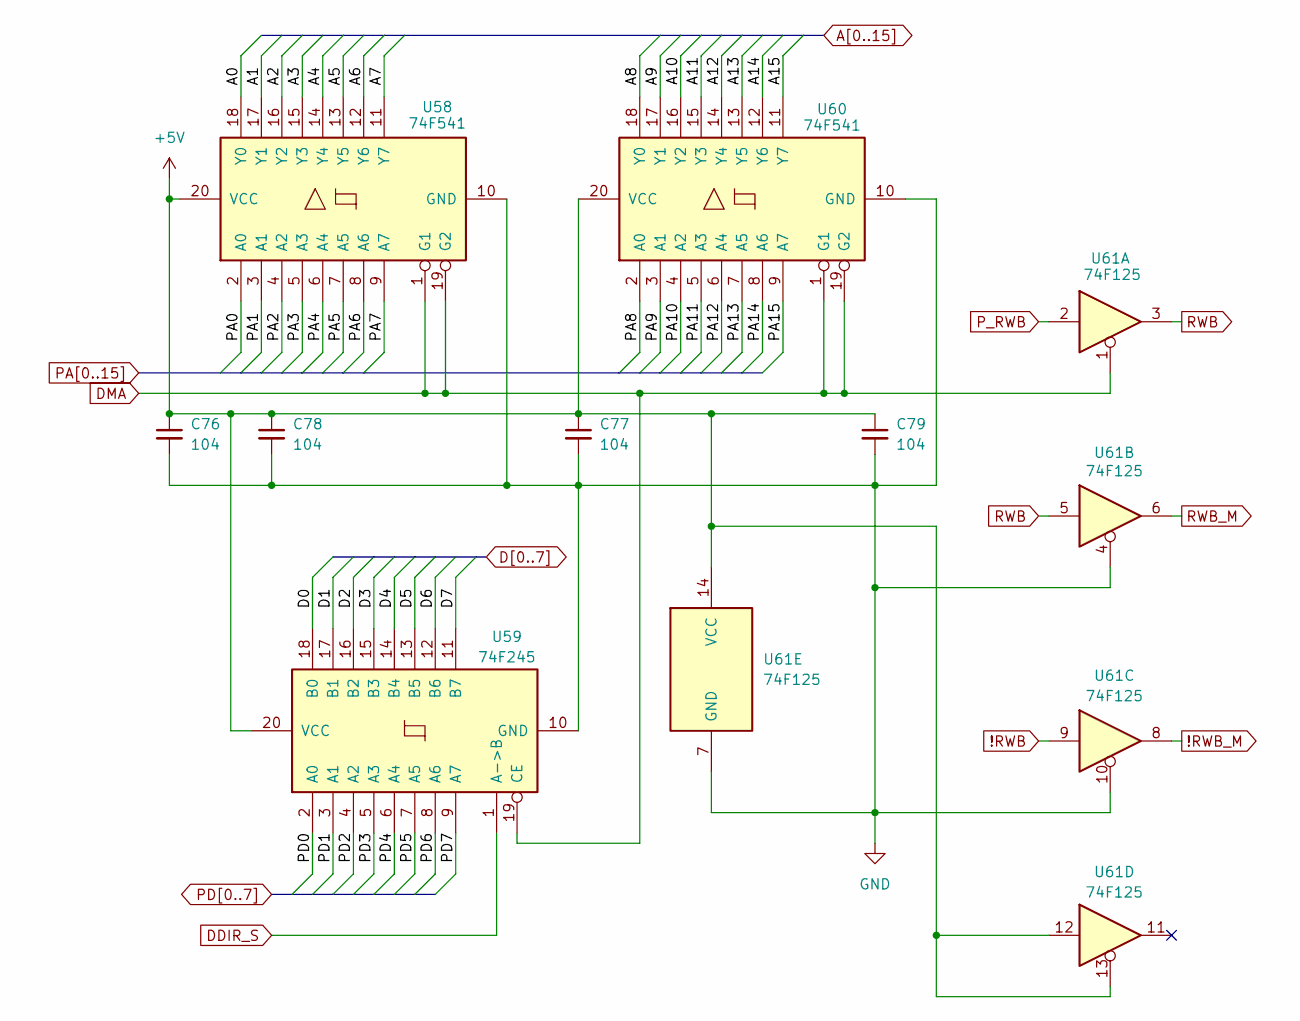
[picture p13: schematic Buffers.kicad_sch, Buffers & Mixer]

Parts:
C76, C77, C78, C79: 104; C_Disc_D5.0mm_W2.5mm_P5.00mm
U58, U60: 74F541; DIP-20_W7.62mm_Socket_LongPads
U59: 74F245; DIP-20_W7.62mm_Socket_LongPads
U61: 74F125; DIP-14_W7.62mm_Socket_LongPads

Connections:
!RWB: U61.9; also elsewhere on the board
!RWB_M: U61.8; also elsewhere on the board
+5V: C76.1, C77.1, C78.1, C79.1, U58.20 (VCC), U59.20 (VCC), U60.20 (VCC), U61.12, U61.13, U61.14 (VCC); also elsewhere on the board
A0: U58.18 (Y0); also elsewhere on the board
A1: U58.17 (Y1); also elsewhere on the board
A2: U58.16 (Y2); also elsewhere on the board
A3: U58.15 (Y3); also elsewhere on the board
A4: U58.14 (Y4); also elsewhere on the board
A5: U58.13 (Y5); also elsewhere on the board
A6: U58.12 (Y6); also elsewhere on the board
A7: U58.11 (Y7); also elsewhere on the board
A8: U60.18 (Y0); also elsewhere on the board
A9: U60.17 (Y1); also elsewhere on the board
A10: U60.16 (Y2); also elsewhere on the board
A11: U60.15 (Y3); also elsewhere on the board
A12: U60.14 (Y4); also elsewhere on the board
A13: U60.13 (Y5); also elsewhere on the board
A14: U60.12 (Y6); also elsewhere on the board
A15: U60.11 (Y7); also elsewhere on the board
D0: U59.18 (B0); also elsewhere on the board
D1: U59.17 (B1); also elsewhere on the board
D2: U59.16 (B2); also elsewhere on the board
D3: U59.15 (B3); also elsewhere on the board
D4: U59.14 (B4); also elsewhere on the board
D5: U59.13 (B5); also elsewhere on the board
D6: U59.12 (B6); also elsewhere on the board
D7: U59.11 (B7); also elsewhere on the board
DDIR_S: U59.1 (A->B); also elsewhere on the board
DMA: U58.1 (G1), U58.19 (G2), U59.19 (CE), U60.1 (G1), U60.19 (G2), U61.1; also elsewhere on the board
GND: C76.2, C77.2, C78.2, C79.2, U58.10 (GND), U59.10 (GND), U60.10 (GND), U61.4, U61.7 (GND), U61.10; also elsewhere on the board
PA0: U58.2 (A0); also elsewhere on the board
PA1: U58.3 (A1); also elsewhere on the board
PA2: U58.4 (A2); also elsewhere on the board
PA3: U58.5 (A3); also elsewhere on the board
PA4: U58.6 (A4); also elsewhere on the board
PA5: U58.7 (A5); also elsewhere on the board
PA6: U58.8 (A6); also elsewhere on the board
PA7: U58.9 (A7); also elsewhere on the board
PA8: U60.2 (A0); also elsewhere on the board
PA9: U60.3 (A1); also elsewhere on the board
PA10: U60.4 (A2); also elsewhere on the board
PA11: U60.5 (A3); also elsewhere on the board
PA12: U60.6 (A4); also elsewhere on the board
PA13: U60.7 (A5); also elsewhere on the board
PA14: U60.8 (A6); also elsewhere on the board
PA15: U60.9 (A7); also elsewhere on the board
PD0: U59.2 (A0); also elsewhere on the board
PD1: U59.3 (A1); also elsewhere on the board
PD2: U59.4 (A2); also elsewhere on the board
PD3: U59.5 (A3); also elsewhere on the board
PD4: U59.6 (A4); also elsewhere on the board
PD5: U59.7 (A5); also elsewhere on the board
PD6: U59.8 (A6); also elsewhere on the board
PD7: U59.9 (A7); also elsewhere on the board
P_RWB: U61.2; also elsewhere on the board
RWB: U61.3, U61.5; also elsewhere on the board
RWB_M: U61.6; also elsewhere on the board

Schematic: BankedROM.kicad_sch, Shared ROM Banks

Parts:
C38, C39, C40, C41, C42, C43, C44, C45: 104; C_Disc_D5.0mm_W2.5mm_P5.00mm
U30, U31, U32, U33, U34, U35, U36, U37: SST39SF040; DIP-32_W15.24mm_Socket_LongPads

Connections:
!RWB: U30.24 (OE), U31.24 (OE), U32.24 (OE), U33.24 (OE), U34.24 (OE), U35.24 (OE), U36.24 (OE), U37.24 (OE); also elsewhere on the board
+5V: C38.1, C39.2, C40.2, C41.2, C42.2, C43.2, C44.2, C45.2, U30.31 (PGM), U30.32 (VCC), U31.31 (PGM), U31.32 (VCC), U32.31 (PGM), U32.32 (VCC), U33.31 (PGM), U33.32 (VCC), U34.31 (PGM), U34.32 (VCC), U35.31 (PGM), U35.32 (VCC), U36.31 (PGM), U36.32 (VCC), U37.31 (PGM), U37.32 (VCC); also elsewhere on the board
A0: U30.12 (A0), U31.12 (A0), U32.12 (A0), U33.12 (A0), U34.12 (A0), U35.12 (A0), U36.12 (A0), U37.12 (A0); also elsewhere on the board
A1: U30.11 (A1), U31.11 (A1), U32.11 (A1), U33.11 (A1), U34.11 (A1), U35.11 (A1), U36.11 (A1), U37.11 (A1); also elsewhere on the board
A2: U30.10 (A2), U31.10 (A2), U32.10 (A2), U33.10 (A2), U34.10 (A2), U35.10 (A2), U36.10 (A2), U37.10 (A2); also elsewhere on the board
A3: U30.9 (A3), U31.9 (A3), U32.9 (A3), U33.9 (A3), U34.9 (A3), U35.9 (A3), U36.9 (A3), U37.9 (A3); also elsewhere on the board
A4: U30.8 (A4), U31.8 (A4), U32.8 (A4), U33.8 (A4), U34.8 (A4), U35.8 (A4), U36.8 (A4), U37.8 (A4); also elsewhere on the board
A5: U30.7 (A5), U31.7 (A5), U32.7 (A5), U33.7 (A5), U34.7 (A5), U35.7 (A5), U36.7 (A5), U37.7 (A5); also elsewhere on the board
A6: U30.6 (A6), U31.6 (A6), U32.6 (A6), U33.6 (A6), U34.6 (A6), U35.6 (A6), U36.6 (A6), U37.6 (A6); also elsewhere on the board
A7: U30.5 (A7), U31.5 (A7), U32.5 (A7), U33.5 (A7), U34.5 (A7), U35.5 (A7), U36.5 (A7), U37.5 (A7); also elsewhere on the board
A8: U30.27 (A8), U31.27 (A8), U32.27 (A8), U33.27 (A8), U34.27 (A8), U35.27 (A8), U36.27 (A8), U37.27 (A8); also elsewhere on the board
A9: U30.26 (A9), U31.26 (A9), U32.26 (A9), U33.26 (A9), U34.26 (A9), U35.26 (A9), U36.26 (A9), U37.26 (A9); also elsewhere on the board
A10: U30.23 (A10), U31.23 (A10), U32.23 (A10), U33.23 (A10), U34.23 (A10), U35.23 (A10), U36.23 (A10), U37.23 (A10); also elsewhere on the board
A11: U30.25 (A11), U31.25 (A11), U32.25 (A11), U33.25 (A11), U34.25 (A11), U35.25 (A11), U36.25 (A11), U37.25 (A11); also elsewhere on the board
A12: U30.4 (A12), U31.4 (A12), U32.4 (A12), U33.4 (A12), U34.4 (A12), U35.4 (A12), U36.4 (A12), U37.4 (A12); also elsewhere on the board
A13: U30.28 (A13), U31.28 (A13), U32.28 (A13), U33.28 (A13), U34.28 (A13), U35.28 (A13), U36.28 (A13), U37.28 (A13); also elsewhere on the board
D0: U30.13 (D0), U31.13 (D0), U32.13 (D0), U33.13 (D0), U34.13 (D0), U35.13 (D0), U36.13 (D0), U37.13 (D0); also elsewhere on the board
D1: U30.14 (D1), U31.14 (D1), U32.14 (D1), U33.14 (D1), U34.14 (D1), U35.14 (D1), U36.14 (D1), U37.14 (D1); also elsewhere on the board
D2: U30.15 (D2), U31.15 (D2), U32.15 (D2), U33.15 (D2), U34.15 (D2), U35.15 (D2), U36.15 (D2), U37.15 (D2); also elsewhere on the board
D3: U30.17 (D3), U31.17 (D3), U32.17 (D3), U33.17 (D3), U34.17 (D3), U35.17 (D3), U36.17 (D3), U37.17 (D3); also elsewhere on the board
D4: U30.18 (D4), U31.18 (D4), U32.18 (D4), U33.18 (D4), U34.18 (D4), U35.18 (D4), U36.18 (D4), U37.18 (D4); also elsewhere on the board
D5: U30.19 (D5), U31.19 (D5), U32.19 (D5), U33.19 (D5), U34.19 (D5), U35.19 (D5), U36.19 (D5), U37.19 (D5); also elsewhere on the board
D6: U30.20 (D6), U31.20 (D6), U32.20 (D6), U33.20 (D6), U34.20 (D6), U35.20 (D6), U36.20 (D6), U37.20 (D6); also elsewhere on the board
D7: U30.21 (D7), U31.21 (D7), U32.21 (D7), U33.21 (D7), U34.21 (D7), U35.21 (D7), U36.21 (D7), U37.21 (D7); also elsewhere on the board
GND: C38.2, C39.1, C40.1, C41.1, C42.1, C43.1, C44.1, C45.1, U30.16 (GND), U31.16 (GND), U32.16 (GND), U33.16 (GND), U34.16 (GND), U35.16 (GND), U36.16 (GND), U37.16 (GND); also elsewhere on the board
ROMB0: U30.29 (A14), U31.29 (A14), U32.29 (A14), U33.29 (A14), U34.29 (A14), U35.29 (A14), U36.29 (A14), U37.29 (A14); also elsewhere on the board
ROMB1: U30.3 (A15), U31.3 (A15), U32.3 (A15), U33.3 (A15), U34.3 (A15), U35.3 (A15), U36.3 (A15), U37.3 (A15); also elsewhere on the board
ROMB2: U30.2 (A16), U31.2 (A16), U32.2 (A16), U33.2 (A16), U34.2 (A16), U35.2 (A16), U36.2 (A16), U37.2 (A16); also elsewhere on the board
ROMB3: U30.30 (A17), U31.30 (A17), U32.30 (A17), U33.30 (A17), U34.30 (A17), U35.30 (A17), U36.30 (A17), U37.30 (A17); also elsewhere on the board
ROMB4: U30.1 (A18), U31.1 (A18), U32.1 (A18), U33.1 (A18), U34.1 (A18), U35.1 (A18), U36.1 (A18), U37.1 (A18); also elsewhere on the board
nBROMC0_S: U31.22 (CE); also elsewhere on the board
nBROMC1_S: U32.22 (CE); also elsewhere on the board
nBROMC2_S: U34.22 (CE); also elsewhere on the board
nBROMC3_S: U36.22 (CE); also elsewhere on the board
nBROMC4_S: U30.22 (CE); also elsewhere on the board
nBROMC5_S: U33.22 (CE); also elsewhere on the board
nBROMC6_S: U35.22 (CE); also elsewhere on the board
nBROMC7_S: U37.22 (CE); also elsewhere on the board

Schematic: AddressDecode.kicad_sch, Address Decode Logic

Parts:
C13, C14, C15, C16, C17, C18, C20, C21, C22, C23, C24, C25, C26: 104; C_Disc_D5.0mm_W2.5mm_P5.00mm
U8, U9: 74LS260; DIP-14_W7.62mm_Socket_LongPads
U10: 74F20; DIP-14_W7.62mm_Socket_LongPads
U11: 74F08; DIP-14_W7.62mm_Socket_LongPads
U12: 74F86; DIP-14_W7.62mm_Socket_LongPads
U13, U16: 74F32; DIP-14_W7.62mm_Socket_LongPads
U14: 74F30; DIP-14_W7.62mm_Socket_LongPads
U15: 74F00; DIP-14_W7.62mm_Socket_LongPads
U19: 74LS154; DIP-24_W15.24mm_Socket_LongPads
U20: 74F138; DIP-16_W7.62mm_Socket_LongPads
U21: 74F541; DIP-20_W7.62mm_Socket_LongPads
U22: 74F240; DIP-20_W7.62mm_Socket_LongPads

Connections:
!A0: U22.7 (O1b); also elsewhere on the board
!A3: U12.1, U22.3 (O3b)
!RWB: U10.1, U11.5, U22.18 (O0a); also elsewhere on the board
+5V: C13.2, C14.2, C15.2, C16.2, C17.2, C18.2, C20.2, C21.2, C22.2, C23.2, C24.1, C25.1, C26.2, U8.14 (VCC), U9.14 (VCC), U10.14 (VCC), U11.14 (VCC), U12.4, U12.5, U12.14 (VCC), U13.14 (VCC), U14.14 (VCC), U15.12, U15.13, U15.14 (VCC), U16.14 (VCC), U19.24 (VCC), U20.16 (VCC), U21.20 (VCC), U22.20 (VCC); also elsewhere on the board
A0: U20.1 (A0), U22.13 (I1b); also elsewhere on the board
A1: U8.9, U12.13, U20.2 (A1); also elsewhere on the board
A2: U8.8, U12.2, U12.12, U20.3 (A2); also elsewhere on the board
A3: U8.13, U15.9, U22.17 (I3b); also elsewhere on the board
A4: U8.12, U19.23 (A0); also elsewhere on the board
A5: U8.3, U19.22 (A1); also elsewhere on the board
A6: U8.2, U19.21 (A2); also elsewhere on the board
A7: U8.1, U19.20 (A3); also elsewhere on the board
A8: U9.13, U14.12; also elsewhere on the board
A9: U9.12, U14.11; also elsewhere on the board
A10: U9.3, U14.6; also elsewhere on the board
A11: U9.2, U14.5; also elsewhere on the board
A12: U9.1, U14.4; also elsewhere on the board
A13: U8.4, U9.8, U10.12, U12.10, U14.3; also elsewhere on the board
A14: U8.11, U9.9, U10.10, U12.9, U14.2; also elsewhere on the board
A15: U8.10, U10.9, U11.12, U14.1; also elsewhere on the board
DDIR_S: U11.6; also elsewhere on the board
DMA: U22.16 (O1a); also elsewhere on the board
DMAB: U11.1, U22.4 (I1a); also elsewhere on the board
GND: C13.1, C14.1, C15.1, C16.1, C17.1, C18.1, C20.1, C21.1, C22.1, C23.1, C24.2, C25.2, C26.1, U8.7 (GND), U9.4, U9.7 (GND), U9.10, U9.11, U10.7 (GND), U11.7 (GND), U12.7 (GND), U13.7 (GND), U14.7 (GND), U15.7 (GND), U16.7 (GND), U19.12 (GND), U19.19 (~E1), U20.8 (GND), U21.1 (G1), U21.10 (GND), U21.19 (G2), U22.1 (OEa), U22.10 (GND), U22.19 (OEb); also elsewhere on the board
IRQ: U22.8 (I3a); also elsewhere on the board
IRQB: U22.12 (O3a); also elsewhere on the board
unnamed: U8.5, U10.2
unnamed: U8.6, U10.4
unnamed: U9.5, U10.5
unnamed: U10.6, U16.1
unnamed: U10.8, U11.9
unnamed: U11.8, U16.10
unnamed: U11.11, U15.2, U15.4
unnamed: U12.8, U15.1
unnamed: U12.11, U15.10
unnamed: U13.13, U15.8
unnamed: U9.6, U15.5
unnamed: U12.3, U20.6 (E2)
PHI1: U13.2, U16.2, U16.9, U22.14 (O2a); also elsewhere on the board
PHI2: U11.2, U11.4, U11.13, U22.6 (I2a); also elsewhere on the board
P_PHI0: U11.3; also elsewhere on the board
RAMB0: U21.6 (A4); also elsewhere on the board
RAMB1: U21.7 (A5); also elsewhere on the board
RAMB2: U21.8 (A6); also elsewhere on the board
RAMB3: U21.9 (A7); also elsewhere on the board
RAMB_M0: U21.14 (Y4); also elsewhere on the board
RAMB_M1: U21.13 (Y5); also elsewhere on the board
RAMB_M2: U21.12 (Y6); also elsewhere on the board
RAMB_M3: U21.11 (Y7); also elsewhere on the board
RWB: U22.2 (I0a); also elsewhere on the board
T0: U21.2 (A0); also elsewhere on the board
T1: U21.3 (A1); also elsewhere on the board
T2: U21.4 (A2); also elsewhere on the board
T3: U21.5 (A3); also elsewhere on the board
T_M0: U21.18 (Y0); also elsewhere on the board
T_M1: U21.17 (Y1); also elsewhere on the board
T_M2: U21.16 (Y2); also elsewhere on the board
T_M3: U21.15 (Y3); also elsewhere on the board
nBRA_S: U15.6; also elsewhere on the board
nBRO_S: U15.3; also elsewhere on the board
nFFFE_S: U13.6; also elsewhere on the board
nFFFF_S: U13.8; also elsewhere on the board
nFFxx_S: U10.13, U13.1, U14.8
nIOB0_S: U20.15 (~Y0); also elsewhere on the board
nIOB1_S: U20.14 (~Y1); also elsewhere on the board
nIOB2_S: U20.13 (~Y2); also elsewhere on the board
nIOB3_S: U20.12 (~Y3); also elsewhere on the board
nIOB12_S: U20.11 (~Y4)
nIOB13_S: U20.10 (~Y5)
nIOB14_S: U13.5, U20.9 (~Y6)
nIOB15_S: U13.10, U20.7 (~Y7)
nIOP0_S: U19.1 (~S0); also elsewhere on the board
nIOP1_S: U19.2 (~S1); also elsewhere on the board
nIOP2_S: U19.3 (~S2); also elsewhere on the board
nIOP3_S: U19.4 (~S3); also elsewhere on the board
nIOP4_S: U19.5 (~S4); also elsewhere on the board
nIOP5_S: U19.6 (~S5); also elsewhere on the board
nIOP6_S: U19.7 (~S6); also elsewhere on the board
nIOP7_S: U19.8 (~S7); also elsewhere on the board
nIOP8_S: U19.9 (~S8); also elsewhere on the board
nIOP9_S: U19.10 (~S9); also elsewhere on the board
nIOP10_S: U19.11 (~S10); also elsewhere on the board
nIOP11_S: U19.13 (~S11); also elsewhere on the board
nIOP12_S: U19.14 (~S12); also elsewhere on the board
nIOP13_S: U19.15 (~S13); also elsewhere on the board
nIOP14_S: U19.16 (~S14); also elsewhere on the board
nIOP15_S: U13.4, U13.9, U13.12, U19.17 (~S15), U20.5 (~E1); also elsewhere on the board
nIO_S: U13.3, U19.18 (~E0), U20.4 (~E0); also elsewhere on the board
nOSRV_S: U11.10, U13.11
nOSR_S: U16.8; also elsewhere on the board
nZPR_W: U16.3; also elsewhere on the board

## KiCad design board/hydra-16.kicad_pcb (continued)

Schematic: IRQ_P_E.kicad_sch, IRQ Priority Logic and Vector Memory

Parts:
C19, C57, C58, C59, C60, C61, C62, C63: 104; C_Disc_D5.0mm_W2.5mm_P5.00mm
IC5, IC6, IC7, IC8: 74LS219; DIP-16_W7.62mm_Socket_LongPads; Manufacturer_Part_Number SN74LS219AN
RN2, RN3: 332; R_Array_SIP9
U17, U18: 74LS148; DIP-16_W7.62mm_Socket_LongPads
U44: 74F00; DIP-14_W7.62mm_Socket_LongPads
U45: 74F157; DIP-16_W7.62mm_Socket_LongPads

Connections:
+5V: C19.1, C57.1, C58.1, C59.1, C60.1, C61.1, C62.1, C63.1, IC5.16 (VCC), IC6.16 (VCC), IC7.16 (VCC), IC8.16 (VCC), RN2.1 (common), RN3.1 (common), U17.16 (VCC), U18.16 (VCC), U44.14 (VCC), U45.16 (VCC); also elsewhere on the board
D0: IC5.4 (D1), IC5.5 (Q1), IC7.4 (D1), IC7.5 (Q1); also elsewhere on the board
D1: IC5.6 (D2), IC5.7 (Q2), IC7.6 (D2), IC7.7 (Q2); also elsewhere on the board
D2: IC5.9 (Q3), IC5.10 (D3), IC7.9 (Q3), IC7.10 (D3); also elsewhere on the board
D3: IC5.11 (Q4), IC5.12 (D4), IC7.11 (Q4), IC7.12 (D4); also elsewhere on the board
D4: IC6.4 (D1), IC6.5 (Q1), IC8.4 (D1), IC8.5 (Q1); also elsewhere on the board
D5: IC6.6 (D2), IC6.7 (Q2), IC8.6 (D2), IC8.7 (Q2); also elsewhere on the board
D6: IC6.11 (Q4), IC6.12 (D4), IC8.11 (Q4), IC8.12 (D4); also elsewhere on the board
D7: IC6.9 (Q3), IC6.10 (D3), IC8.9 (Q3), IC8.10 (D3); also elsewhere on the board
GND: C19.2, C57.2, C58.2, C59.2, C60.2, C61.2, C62.2, C63.2, IC5.8 (GND), IC6.8 (GND), IC7.8 (GND), IC8.8 (GND), U17.5 (~EI), U17.8 (GND), U18.8 (GND), U44.7 (GND), U45.8 (GND), U45.15 (~EN); also elsewhere on the board
IRQ: U44.3, U45.1 (A/B); also elsewhere on the board
unnamed: U17.15 (~EO), U18.5 (~EI)
unnamed: U17.14 (~GS), U44.2, U45.10 (I1d)
unnamed: U17.9 (~S0), U44.5
unnamed: U17.7 (~S1), U44.10
unnamed: U17.6 (~S2), U44.13
unnamed: U18.14 (~GS), U44.1
unnamed: U18.9 (~S0), U44.4
unnamed: U18.7 (~S1), U44.9
unnamed: U18.6 (~S2), U44.12
unnamed: U44.6, U45.3 (I1a)
unnamed: U44.8, U45.6 (I1b)
unnamed: U44.11, U45.13 (I1c)
RWB: IC5.3 (R/~W), IC6.3 (R/~W), IC7.3 (R/~W), IC8.3 (R/~W); also elsewhere on the board
V0: U45.2 (I0a); also elsewhere on the board
V1: U45.5 (I0b); also elsewhere on the board
V2: U45.14 (I0c); also elsewhere on the board
V3: U45.11 (I0d); also elsewhere on the board
nFFFE_S: IC5.2 (~S), IC6.2 (~S); also elsewhere on the board
nFFFF_S: IC7.2 (~S), IC8.2 (~S); also elsewhere on the board
nIRQ0: RN2.5 (R4), U17.4 (~I7); also elsewhere on the board
nIRQ1: RN2.4 (R3), U17.3 (~I6); also elsewhere on the board
nIRQ2: RN2.3 (R2), U17.2 (~I5); also elsewhere on the board
nIRQ3: RN2.2 (R1), U17.1 (~I4); also elsewhere on the board
nIRQ4: RN2.6 (R5), U17.13 (~I3); also elsewhere on the board
nIRQ5: RN2.7 (R6), U17.12 (~I2); also elsewhere on the board
nIRQ6: RN2.8 (R7), U17.11 (~I1); also elsewhere on the board
nIRQ7: RN2.9 (R8), U17.10 (~IO); also elsewhere on the board
nIRQ8: RN3.5 (R4), U18.4 (~I7); also elsewhere on the board
nIRQ9: RN3.4 (R3), U18.3 (~I6); also elsewhere on the board
nIRQ10: RN3.3 (R2), U18.2 (~I5); also elsewhere on the board
nIRQ11: RN3.2 (R1), U18.1 (~I4); also elsewhere on the board
nIRQ12: RN3.6 (R5), U18.13 (~I3); also elsewhere on the board
nIRQ13: RN3.7 (R6), U18.12 (~I2); also elsewhere on the board
nIRQ14: RN3.8 (R7), U18.11 (~I1); also elsewhere on the board
nIRQ15: RN3.9 (R8), U18.10 (~IO)
q0: IC5.1 (A0), IC6.1 (A0), IC7.1 (A0), IC8.1 (A0), U45.4 (Qa)
q1: IC5.15 (A1), IC6.15 (A1), IC7.15 (A1), IC8.15 (A1), U45.7 (Qb)
q2: IC5.14 (A2), IC6.14 (A2), IC7.14 (A2), IC8.14 (A2), U45.12 (Qc)
q3: IC5.13 (A3), IC6.13 (A3), IC7.13 (A3), IC8.13 (A3), U45.9 (Qd)

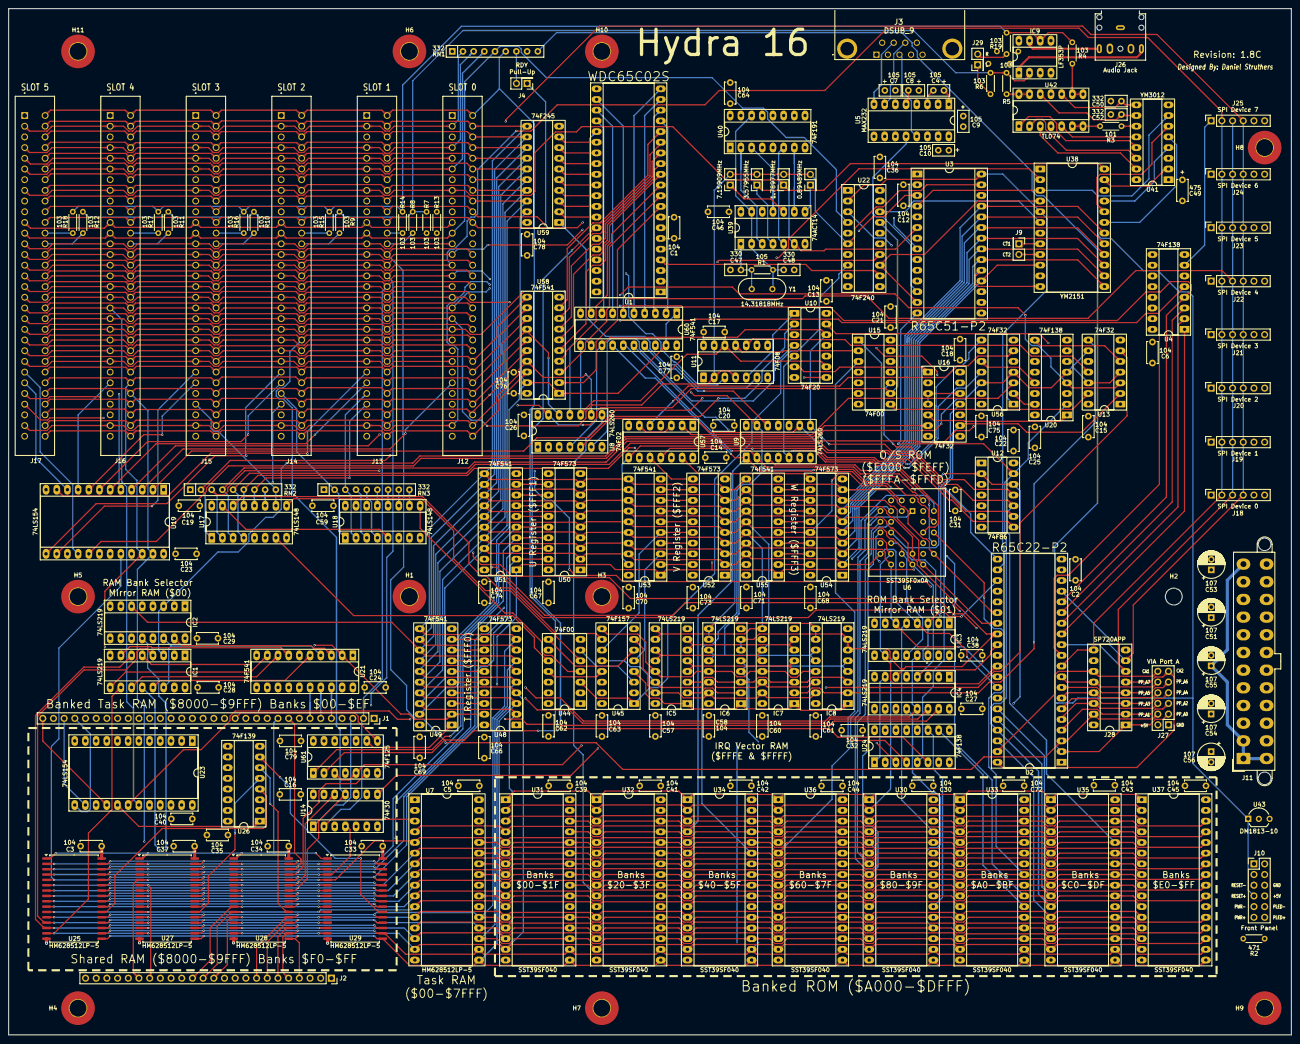
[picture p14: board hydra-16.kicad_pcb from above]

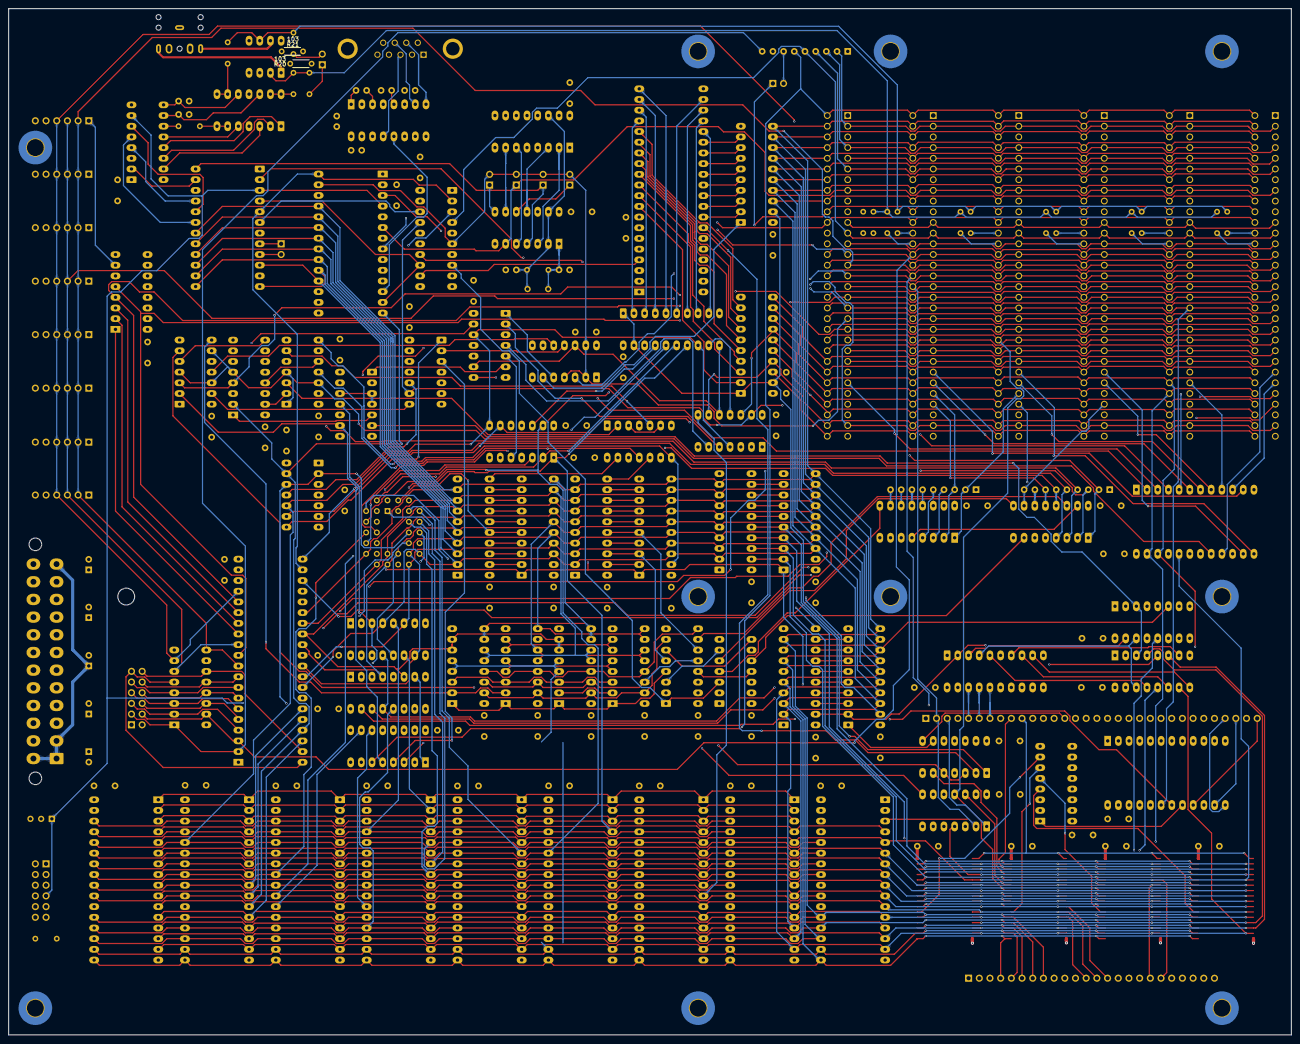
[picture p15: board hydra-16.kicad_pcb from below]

Board: 6 copper layers, 304.8 x 243.8 mm, 210 parts (2 on the bottom side), 335 nets.

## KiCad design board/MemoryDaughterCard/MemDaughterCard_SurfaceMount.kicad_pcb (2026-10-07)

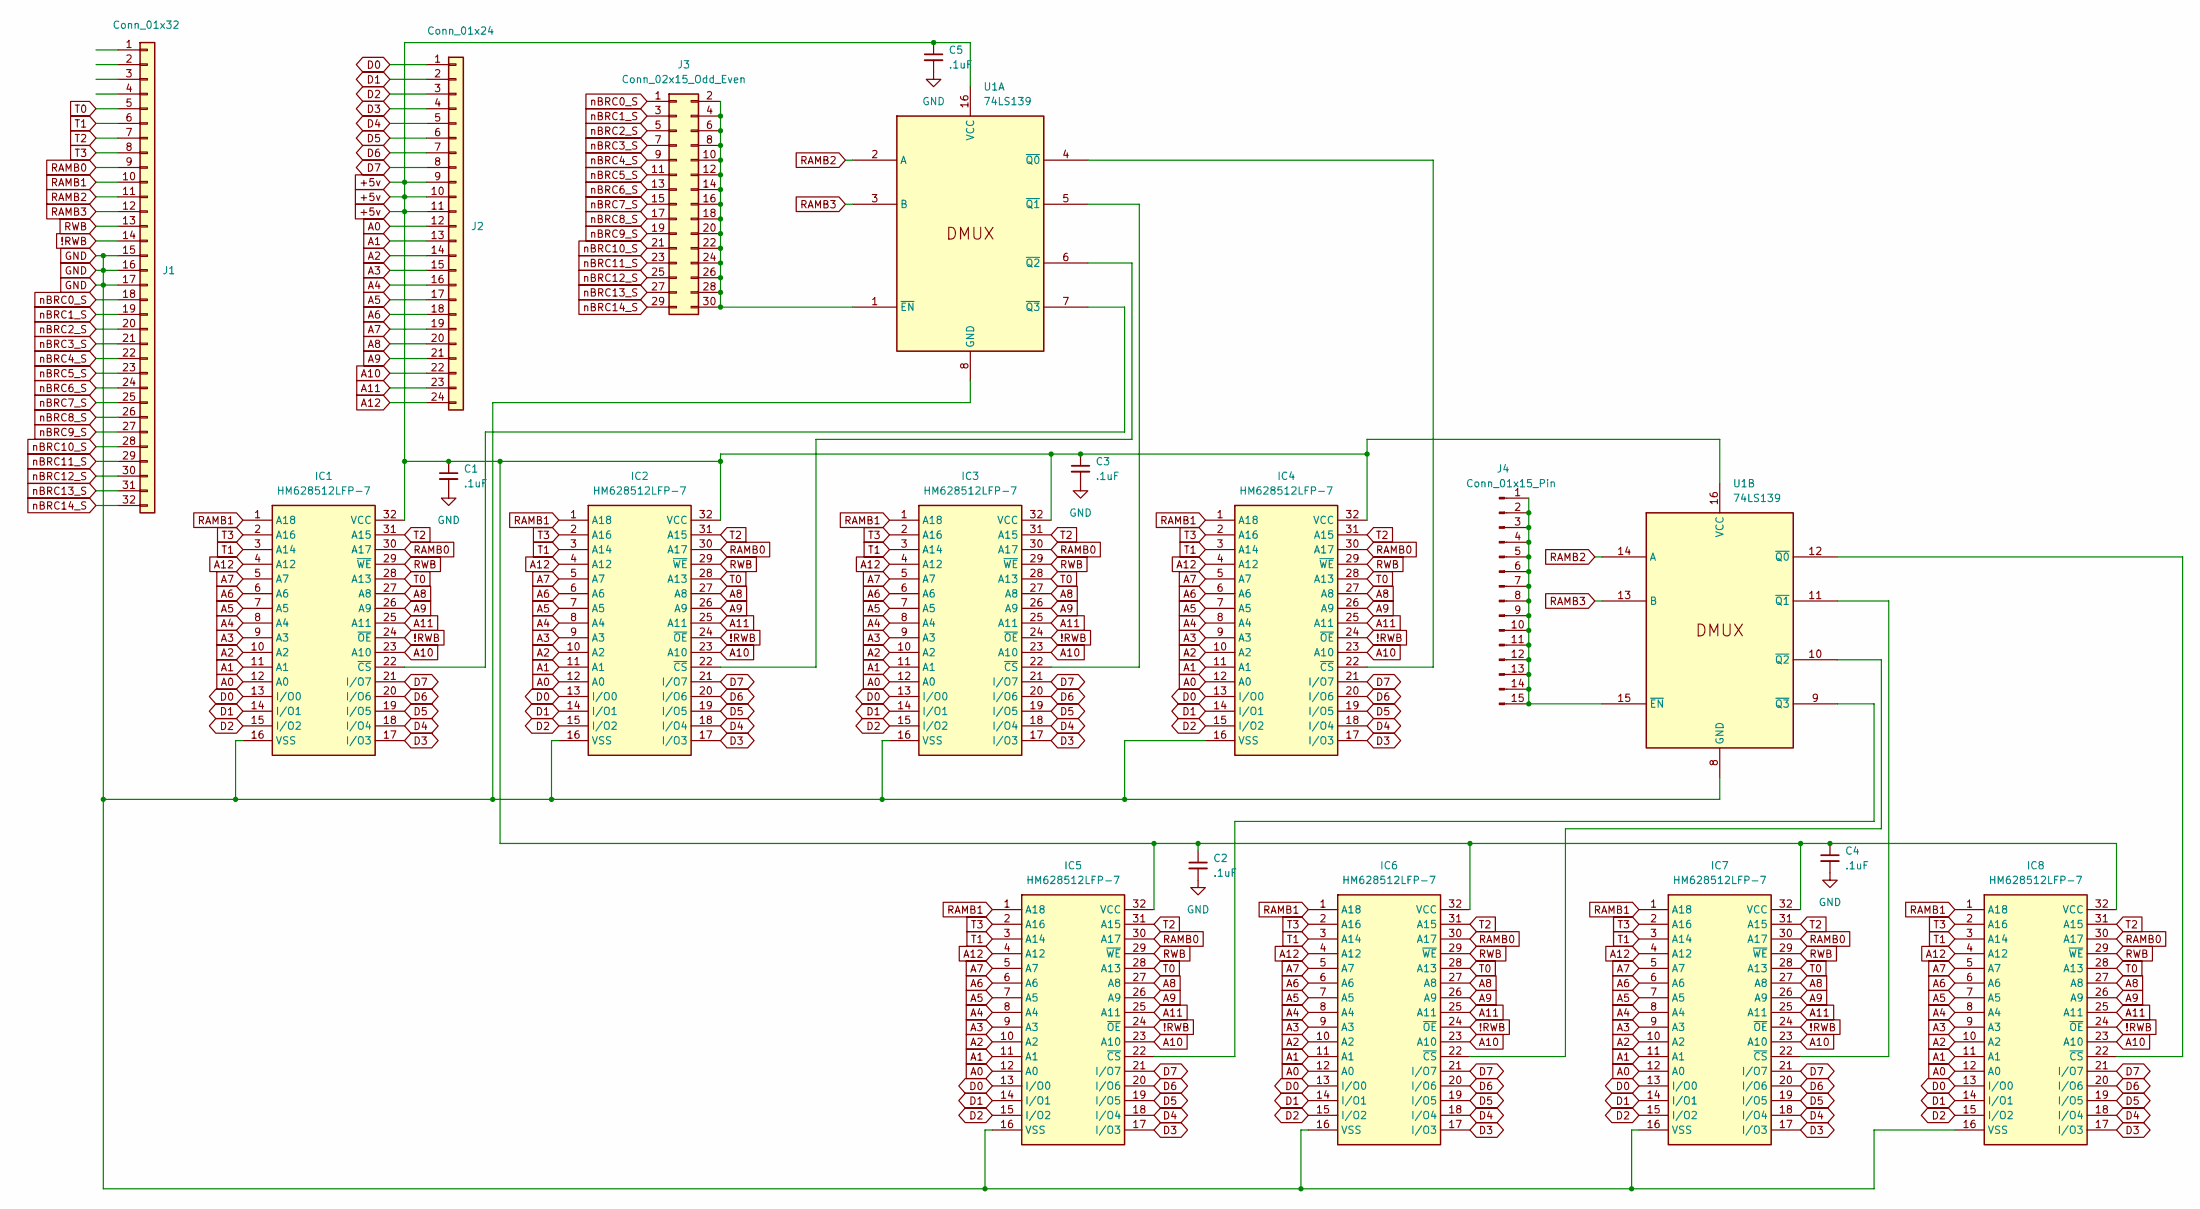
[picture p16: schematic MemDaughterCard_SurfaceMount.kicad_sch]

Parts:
C1, C2, C3, C4, C5: .1uF; C_Disc_D5.0mm_W2.5mm_P5.00mm
IC1, IC2, IC3, IC4, IC5, IC6, IC7, IC8: HM628512LFP-7; SOIC127P1414X300-32N; Manufacturer_Part_Number HM628512LFP-7
J1: Conn_01x32; PinHeader_1x32_P2.54mm_Vertical
J2: Conn_01x24; PinHeader_1x24_P2.54mm_Vertical
J3: Conn_02x15_Odd_Even; PinHeader_2x15_P2.54mm_Vertical
J4: Conn_01x15_Pin; PinHeader_1x15_P2.54mm_Vertical
U1: 74LS139; DIP-16_W7.62mm

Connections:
!RWB: IC1.24 (~OE), IC2.24 (~OE), IC3.24 (~OE), IC4.24 (~OE), IC5.24 (~OE), IC6.24 (~OE), IC7.24 (~OE), IC8.24 (~OE), J1.14
+5v: C1.1, C2.1, C3.1, C4.1, C5.1, IC1.32 (VCC), IC2.32 (VCC), IC3.32 (VCC), IC4.32 (VCC), IC5.32 (VCC), IC6.32 (VCC), IC7.32 (VCC), IC8.32 (VCC), J2.9, J2.10, J2.11, U1.16 (VCC)
A0: IC1.12 (A0), IC2.12 (A0), IC3.12 (A0), IC4.12 (A0), IC5.12 (A0), IC6.12 (A0), IC7.12 (A0), IC8.12 (A0), J2.12
A1: IC1.11 (A1), IC2.11 (A1), IC3.11 (A1), IC4.11 (A1), IC5.11 (A1), IC6.11 (A1), IC7.11 (A1), IC8.11 (A1), J2.13
A2: IC1.10 (A2), IC2.10 (A2), IC3.10 (A2), IC4.10 (A2), IC5.10 (A2), IC6.10 (A2), IC7.10 (A2), IC8.10 (A2), J2.14
A3: IC1.9 (A3), IC2.9 (A3), IC3.9 (A3), IC4.9 (A3), IC5.9 (A3), IC6.9 (A3), IC7.9 (A3), IC8.9 (A3), J2.15
A4: IC1.8 (A4), IC2.8 (A4), IC3.8 (A4), IC4.8 (A4), IC5.8 (A4), IC6.8 (A4), IC7.8 (A4), IC8.8 (A4), J2.16
A5: IC1.7 (A5), IC2.7 (A5), IC3.7 (A5), IC4.7 (A5), IC5.7 (A5), IC6.7 (A5), IC7.7 (A5), IC8.7 (A5), J2.17
A6: IC1.6 (A6), IC2.6 (A6), IC3.6 (A6), IC4.6 (A6), IC5.6 (A6), IC6.6 (A6), IC7.6 (A6), IC8.6 (A6), J2.18
A7: IC1.5 (A7), IC2.5 (A7), IC3.5 (A7), IC4.5 (A7), IC5.5 (A7), IC6.5 (A7), IC7.5 (A7), IC8.5 (A7), J2.19
A8: IC1.27 (A8), IC2.27 (A8), IC3.27 (A8), IC4.27 (A8), IC5.27 (A8), IC6.27 (A8), IC7.27 (A8), IC8.27 (A8), J2.20
A9: IC1.26 (A9), IC2.26 (A9), IC3.26 (A9), IC4.26 (A9), IC5.26 (A9), IC6.26 (A9), IC7.26 (A9), IC8.26 (A9), J2.21
A10: IC1.23 (A10), IC2.23 (A10), IC3.23 (A10), IC4.23 (A10), IC5.23 (A10), IC6.23 (A10), IC7.23 (A10), IC8.23 (A10), J2.22
A11: IC1.25 (A11), IC2.25 (A11), IC3.25 (A11), IC4.25 (A11), IC5.25 (A11), IC6.25 (A11), IC7.25 (A11), IC8.25 (A11), J2.23
A12: IC1.4 (A12), IC2.4 (A12), IC3.4 (A12), IC4.4 (A12), IC5.4 (A12), IC6.4 (A12), IC7.4 (A12), IC8.4 (A12), J2.24
D0: IC1.13 (I/O0), IC2.13 (I/O0), IC3.13 (I/O0), IC4.13 (I/O0), IC5.13 (I/O0), IC6.13 (I/O0), IC7.13 (I/O0), IC8.13 (I/O0), J2.1
D1: IC1.14 (I/O1), IC2.14 (I/O1), IC3.14 (I/O1), IC4.14 (I/O1), IC5.14 (I/O1), IC6.14 (I/O1), IC7.14 (I/O1), IC8.14 (I/O1), J2.2
D2: IC1.15 (I/O2), IC2.15 (I/O2), IC3.15 (I/O2), IC4.15 (I/O2), IC5.15 (I/O2), IC6.15 (I/O2), IC7.15 (I/O2), IC8.15 (I/O2), J2.3
D3: IC1.17 (I/O3), IC2.17 (I/O3), IC3.17 (I/O3), IC4.17 (I/O3), IC5.17 (I/O3), IC6.17 (I/O3), IC7.17 (I/O3), IC8.17 (I/O3), J2.4
D4: IC1.18 (I/O4), IC2.18 (I/O4), IC3.18 (I/O4), IC4.18 (I/O4), IC5.18 (I/O4), IC6.18 (I/O4), IC7.18 (I/O4), IC8.18 (I/O4), J2.5
D5: IC1.19 (I/O5), IC2.19 (I/O5), IC3.19 (I/O5), IC4.19 (I/O5), IC5.19 (I/O5), IC6.19 (I/O5), IC7.19 (I/O5), IC8.19 (I/O5), J2.6
D6: IC1.20 (I/O6), IC2.20 (I/O6), IC3.20 (I/O6), IC4.20 (I/O6), IC5.20 (I/O6), IC6.20 (I/O6), IC7.20 (I/O6), IC8.20 (I/O6), J2.7
D7: IC1.21 (I/O7), IC2.21 (I/O7), IC3.21 (I/O7), IC4.21 (I/O7), IC5.21 (I/O7), IC6.21 (I/O7), IC7.21 (I/O7), IC8.21 (I/O7), J2.8
GND: C1.2, C2.2, C3.2, C4.2, C5.2, IC1.16 (VSS), IC2.16 (VSS), IC3.16 (VSS), IC4.16 (VSS), IC5.16 (VSS), IC6.16 (VSS), IC7.16 (VSS), IC8.16 (VSS), J1.15, J1.16, J1.17, U1.8 (GND)
unnamed: IC1.22 (~CS), U1.7 (~Q3)
unnamed: IC2.22 (~CS), U1.6 (~Q2)
unnamed: IC3.22 (~CS), U1.5 (~Q1)
unnamed: IC4.22 (~CS), U1.4 (~Q0)
unnamed: IC5.22 (~CS), U1.9 (~Q3)
unnamed: IC6.22 (~CS), U1.10 (~Q2)
unnamed: IC7.22 (~CS), U1.11 (~Q1)
unnamed: IC8.22 (~CS), U1.12 (~Q0)
unnamed: J3.2, J3.4, J3.6, J3.8, J3.10, J3.12, J3.14, J3.16, J3.18, J3.20, J3.22, J3.24, J3.26, J3.28, J3.30, U1.1 (~EN)
unnamed: J4.1, J4.2, J4.3, J4.4, J4.5, J4.6, J4.7, J4.8, J4.9, J4.10, J4.11, J4.12, J4.13, J4.14, J4.15, U1.15 (~EN)
RAMB0: IC1.30 (A17), IC2.30 (A17), IC3.30 (A17), IC4.30 (A17), IC5.30 (A17), IC6.30 (A17), IC7.30 (A17), IC8.30 (A17), J1.9
RAMB1: IC1.1 (A18), IC2.1 (A18), IC3.1 (A18), IC4.1 (A18), IC5.1 (A18), IC6.1 (A18), IC7.1 (A18), IC8.1 (A18), J1.10
RAMB2: J1.11, U1.2 (A), U1.14 (A)
RAMB3: J1.12, U1.3 (B), U1.13 (B)
RWB: IC1.29 (~WE), IC2.29 (~WE), IC3.29 (~WE), IC4.29 (~WE), IC5.29 (~WE), IC6.29 (~WE), IC7.29 (~WE), IC8.29 (~WE), J1.13
T0: IC1.28 (A13), IC2.28 (A13), IC3.28 (A13), IC4.28 (A13), IC5.28 (A13), IC6.28 (A13), IC7.28 (A13), IC8.28 (A13), J1.5
T1: IC1.3 (A14), IC2.3 (A14), IC3.3 (A14), IC4.3 (A14), IC5.3 (A14), IC6.3 (A14), IC7.3 (A14), IC8.3 (A14), J1.6
T2: IC1.31 (A15), IC2.31 (A15), IC3.31 (A15), IC4.31 (A15), IC5.31 (A15), IC6.31 (A15), IC7.31 (A15), IC8.31 (A15), J1.7
T3: IC1.2 (A16), IC2.2 (A16), IC3.2 (A16), IC4.2 (A16), IC5.2 (A16), IC6.2 (A16), IC7.2 (A16), IC8.2 (A16), J1.8
nBRC0_S: J1.18, J3.1
nBRC1_S: J1.19, J3.3
nBRC2_S: J1.20, J3.5
nBRC3_S: J1.21, J3.7
nBRC4_S: J1.22, J3.9
nBRC5_S: J1.23, J3.11
nBRC6_S: J1.24, J3.13
nBRC7_S: J1.25, J3.15
nBRC8_S: J1.26, J3.17
nBRC9_S: J1.27, J3.19
nBRC10_S: J1.28, J3.21
nBRC11_S: J1.29, J3.23
nBRC12_S: J1.30, J3.25
nBRC13_S: J1.31, J3.27
nBRC14_S: J1.32, J3.29

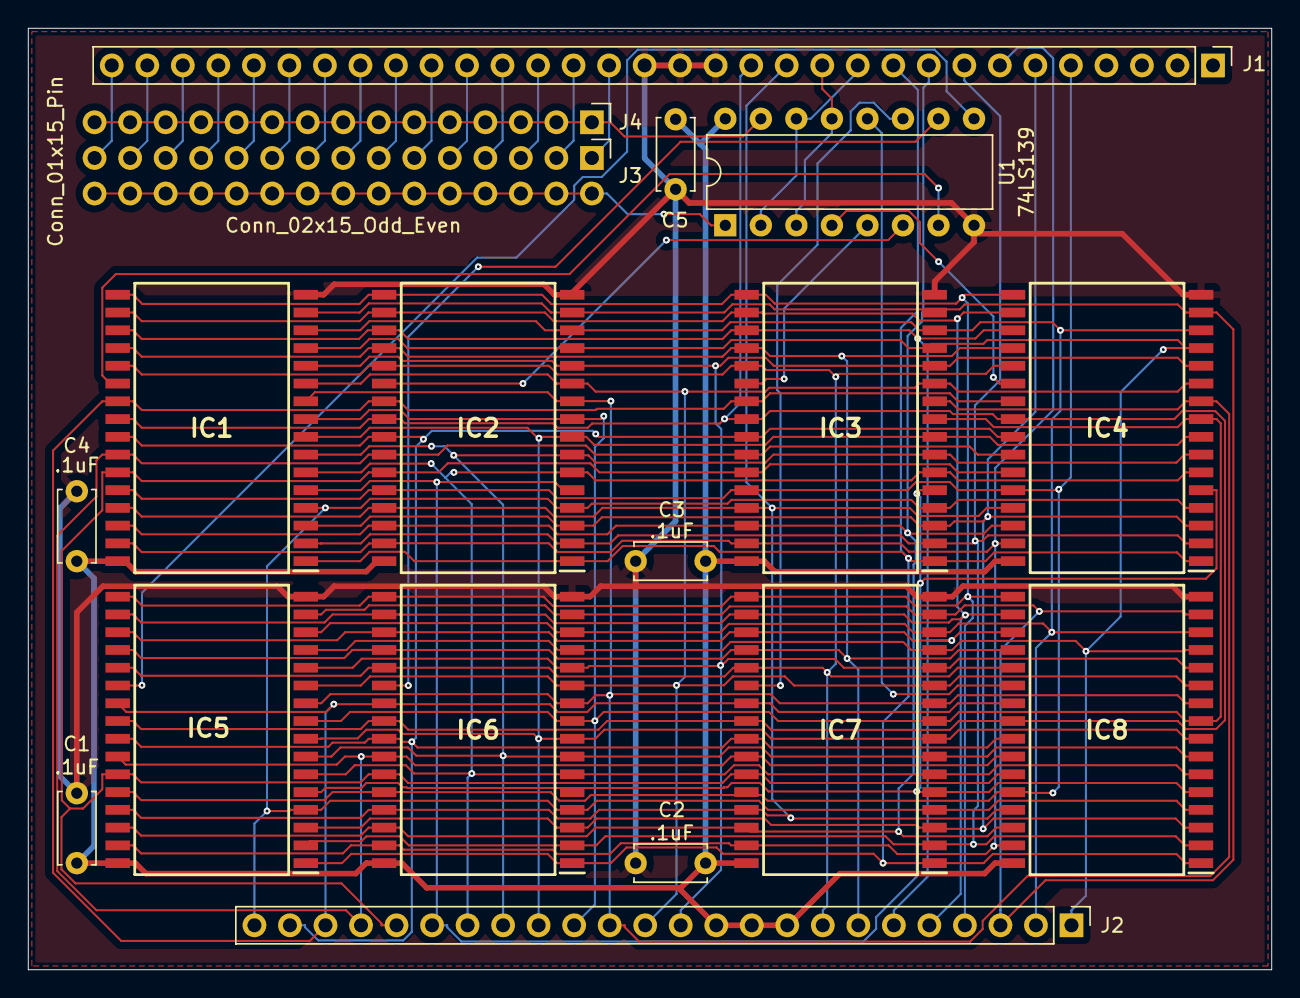
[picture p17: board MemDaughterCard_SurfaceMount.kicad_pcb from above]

Board: 2 copper layers, 88.9 x 67.3 mm, 18 parts (0 on the bottom side), 58 nets.

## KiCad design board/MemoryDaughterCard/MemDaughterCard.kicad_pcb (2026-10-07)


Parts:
C1, C2, C3, C4, C5: .1uF; C_Disc_D5.0mm_W2.5mm_P5.00mm
IC1, IC2, IC3, IC4: HM628512LP-7; DIP-32_W15.24mm_Socket_LongPads; Manufacturer_Part_Number HM628512LFP-7
J1: Conn_01x32; PinHeader_1x32_P2.54mm_Vertical
J2: Conn_01x24; PinHeader_1x24_P2.54mm_Vertical
J3: Conn_02x15_Odd_Even; PinHeader_2x15_P2.54mm_Vertical
U1: 74LS139; DIP-16_W7.62mm

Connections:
!RWB: IC1.24 (~OE), IC2.24 (~OE), IC3.24 (~OE), IC4.24 (~OE), J1.14
+5v: C1.1, C2.1, C3.1, C4.1, C5.1, IC1.32 (VCC), IC2.32 (VCC), IC3.32 (VCC), IC4.32 (VCC), J2.9, J2.10, J2.11, U1.16 (VCC)
A0: IC1.12 (A0), IC2.12 (A0), IC3.12 (A0), IC4.12 (A0), J2.12
A1: IC1.11 (A1), IC2.11 (A1), IC3.11 (A1), IC4.11 (A1), J2.13
A2: IC1.10 (A2), IC2.10 (A2), IC3.10 (A2), IC4.10 (A2), J2.14
A3: IC1.9 (A3), IC2.9 (A3), IC3.9 (A3), IC4.9 (A3), J2.15
A4: IC1.8 (A4), IC2.8 (A4), IC3.8 (A4), IC4.8 (A4), J2.16
A5: IC1.7 (A5), IC2.7 (A5), IC3.7 (A5), IC4.7 (A5), J2.17
A6: IC1.6 (A6), IC2.6 (A6), IC3.6 (A6), IC4.6 (A6), J2.18
A7: IC1.5 (A7), IC2.5 (A7), IC3.5 (A7), IC4.5 (A7), J2.19
A8: IC1.27 (A8), IC2.27 (A8), IC3.27 (A8), IC4.27 (A8), J2.20
A9: IC1.26 (A9), IC2.26 (A9), IC3.26 (A9), IC4.26 (A9), J2.21
A10: IC1.23 (A10), IC2.23 (A10), IC3.23 (A10), IC4.23 (A10), J2.22
A11: IC1.25 (A11), IC2.25 (A11), IC3.25 (A11), IC4.25 (A11), J2.23
A12: IC1.4 (A12), IC2.4 (A12), IC3.4 (A12), IC4.4 (A12), J2.24
D0: IC1.13 (I/O0), IC2.13 (I/O0), IC3.13 (I/O0), IC4.13 (I/O0), J2.1
D1: IC1.14 (I/O1), IC2.14 (I/O1), IC3.14 (I/O1), IC4.14 (I/O1), J2.2
D2: IC1.15 (I/O2), IC2.15 (I/O2), IC3.15 (I/O2), IC4.15 (I/O2), J2.3
D3: IC1.17 (I/O3), IC2.17 (I/O3), IC3.17 (I/O3), IC4.17 (I/O3), J2.4
D4: IC1.18 (I/O4), IC2.18 (I/O4), IC3.18 (I/O4), IC4.18 (I/O4), J2.5
D5: IC1.19 (I/O5), IC2.19 (I/O5), IC3.19 (I/O5), IC4.19 (I/O5), J2.6
D6: IC1.20 (I/O6), IC2.20 (I/O6), IC3.20 (I/O6), IC4.20 (I/O6), J2.7
D7: IC1.21 (I/O7), IC2.21 (I/O7), IC3.21 (I/O7), IC4.21 (I/O7), J2.8
GND: C1.2, C2.2, C3.2, C4.2, C5.2, IC1.16 (VSS), IC2.16 (VSS), IC3.16 (VSS), IC4.16 (VSS), J1.15, J1.16, J1.17, U1.8 (GND)
unnamed: IC1.22 (~CS), U1.9 (~Q3)
unnamed: IC2.22 (~CS), U1.10 (~Q2)
unnamed: IC3.22 (~CS), U1.11 (~Q1)
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

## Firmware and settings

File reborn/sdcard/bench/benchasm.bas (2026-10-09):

' benchasm.bas - the benchmarks in BASIC's inline assembly: bench.bas's twenty (the same algorithms, sizes and
' results), each one's work in an ASM block, called with CALL ASM; the program around them is bench.bas's.  basic
' benchasm.bas [reps [q|f [name ...]]]: each run reps times (1), a line for each, "bench basm NAME RESULT TICKS REPS".
' sim/bench.js runs it beside bench.bas, bench.hl and bench.fs; each benchmark's reps are a loop of their own, so a
' rep's time is its code's and the CALL ASM's (bench.bas's SELECT CASE in the loop, its strings compared, would be
' more than some of them).  The code works in 16 bits (every value of these sizes fits): a size in .A (its low byte)
' and .X (its high), the result back in .A and .X; r0-r15 its zero page; recursion where the others recurse (fib, tak,
' ack, queens: the 6502's stack), a subroutine called where they call a function (calls, mapf, fold), a multiplication
' by a routine of shifts and adds (hash, sort, matrix, mapf), the arrays bytes in the blocks' .bss, the text in its
' .rodata, numbers written out by division by 10 (digits).

CONST MAPN = 40, FOLDN = 200, EACHN = 200
reps = VAL(ARG$(1)): IF reps < 1 THEN reps = 1
quick = ARG$(2) = "q"
DO
    READ nm$, nf, nq
    IF nm$ = "done" THEN EXIT DO
    IF chosen(nm$) THEN
        n = nf: IF quick THEN n = nq
        nl = n AND 255: nh = n \ 256
        t0 = ticks
        SELECT CASE nm$                 ' (Chosen once: each its own loop of reps)
            CASE "calls":   FOR rr = 1 TO reps: CALL ASM calls, nl, nh: NEXT
            CASE "fib":     FOR rr = 1 TO reps: CALL ASM fibr, nl: NEXT
            CASE "tak":     FOR rr = 1 TO reps: CALL ASM taks, nl: NEXT
            CASE "ack":     FOR rr = 1 TO reps: CALL ASM acks, nl: NEXT
            CASE "loop":    FOR rr = 1 TO reps: CALL ASM countup, nl, nh: NEXT
            CASE "while":   FOR rr = 1 TO reps: CALL ASM whilesum, nl, nh: NEXT
            CASE "dotimes": FOR rr = 1 TO reps: CALL ASM forsum, nl, nh: NEXT
            CASE "nested":  FOR rr = 1 TO reps: CALL ASM nested, nl: NEXT
            CASE "gcd":     FOR rr = 1 TO reps: CALL ASM gcdsum, nl: NEXT
            CASE "collatz": FOR rr = 1 TO reps: CALL ASM collatz, nl: NEXT
            CASE "hash":    FOR rr = 1 TO reps: CALL ASM hash, nl, nh: NEXT
            CASE "sieve":   FOR rr = 1 TO reps: CALL ASM sieve, nl, nh: NEXT
            CASE "sort":    FOR rr = 1 TO reps: CALL ASM sortb, nl: NEXT
            CASE "matrix":  FOR rr = 1 TO reps: CALL ASM matrix, nl: NEXT
            CASE "queens":  FOR rr = 1 TO reps: CALL ASM queens, nl: NEXT
            CASE "mapf":    FOR rr = 1 TO reps: CALL ASM mapf, nl: NEXT
            CASE "fold":    FOR rr = 1 TO reps: CALL ASM fold, nl: NEXT
            CASE "each":    FOR rr = 1 TO reps: CALL ASM eachsum, nl: NEXT
            CASE "chars":   FOR rr = 1 TO reps: CALL ASM chars, nl: NEXT
            CASE "digits":  FOR rr = 1 TO reps: CALL ASM digitslen, nl, nh: NEXT
        END SELECT
        RREG rl, rh: r = rh * 256 + rl
        d = (ticks - t0) MOD 32768: IF d < 0 THEN d = d + 32768
        PRINT "bench basm "; nm$; STR$(r); STR$(d); STR$(reps)
    END IF
LOOP
PRINT "bench basm done"
' Each benchmark's name, its size, its quick size (mapf's, fold's and each's: their reps): bench.bas's
DATA calls, 2000, 500, fib, 16, 12, tak, 6, 2, ack, 8, 2, loop, 4000, 1000, while, 4000, 1000
DATA dotimes, 4000, 1000, nested, 60, 30, gcd, 20, 10, collatz, 60, 30, hash, 2000, 500, sieve, 1024, 512
DATA sort, 100, 40, matrix, 10, 6, queens, 7, 6, mapf, 20, 5, fold, 10, 3, each, 10, 3, chars, 40, 10
DATA digits, 1000, 300, done, 0, 0

' Is a benchmark chosen: named after q|f, or none named?
FUNCTION chosen (nm$)
    IF ARG$(3) = "" THEN RETURN -1
    FOR a = 3 TO 30
        IF ARG$(a) = "" THEN EXIT FOR
        IF ARG$(a) = nm$ THEN RETURN -1
    NEXT
    RETURN 0
END FUNCTION

' The clock: the ticks (200 a second, 16 bits)
FUNCTION ticks
    SYS "TICKS": RREG l, h
    ticks = h * 256 + l
END FUNCTION

' ---- The code's zero page (r0-r15), its helpers

ASM
zn      = $02                   ; n
zi      = $04                   ; i
zj      = $06                   ; j
zk      = $08                   ; k (a count of reps)
zr      = $0A                   ; the result
za      = $0C                   ; (scratch)
zb      = $0E
zt      = $10
zs      = $12
zp      = $14                   ; (a pointer)
zv      = $16                   ; (a value kept)
zm1     = $18                   ; (mul8's)
zm2     = $19

; 16 bits less one, at v
.macro  dec16 v
        lda v
        bne :+
        dec v + 1
:       dec v
.endmacro

; C = 0 if the 16 bits at v are below those at w
.macro  below16 v, w
        lda v
        cmp w
        lda v + 1
        sbc w + 1
.endmacro

; .A times .Y (8 bits each): the product in .A (its low byte) and .X (its high), by shifts and adds
mul8:   sta zm1
        sty zm2
        lda #0
        ldx #8
        lsr zm1
@bit:   bcc @no
        clc
        adc zm2
@no:    ror a
        ror zm1
        dex
        bne @bit
        tax
        lda zm1
        rts

; The result (zr) in .A and .X
result: lda zr
        ldx zr + 1
        rts
END ASM

' ---- Calls

ASM
; calls: n calls of a subroutine of two arguments (.A and .X its first, .Y its second)
calls:  sta zn
        stx zn + 1
        stz zr
        stz zr + 1
@loop:  lda zn
        ora zn + 1
        beq @done
        lda zr
        ldx zr + 1
        ldy #1
        jsr add2
        sta zr
        stx zr + 1
        dec16 zn
        bra @loop
@done:  jmp result
add2:   sty zt
        clc
        adc zt
        bcc :+
        inx
:       rts

; fib: Fibonacci, recursively (n in .A)
fibr:   cmp #2
        bcs @rec
        ldx #0
        rts
@rec:   pha                     ; (n)
        dec a
        jsr fibr                ; fib(n - 1)
        tay
        pla
        phx                     ; (kept)
        phy
        sec
        sbc #2
        jsr fibr                ; fib(n - 2)
        sta zt
        stx zt + 1
        pla
        clc
        adc zt
        sta zt
        pla
        adc zt + 1
        tax
        lda zt
        rts
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

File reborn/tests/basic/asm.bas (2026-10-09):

' asm.bas - inline assembly: ASM ... END ASM (as's language, the asm library's assembler), CALL ASM's labels and
' their registers (RREG), the program's variables and CONSTs by name (in capitals and in lower case), data in a
' block, a block in a SUB, a label in a later block, macros, .if, cheap and unnamed labels, .include (hydra.inc: a
' system call), a label named as a variable, one named as a keyword (DOUBLE), and the code's own bank
DIM SHARED checks, failed
SUB ck (got, want, what$)
    checks = checks + 1
    IF got <> want THEN failed = failed + 1: PRINT "FAIL "; what$; ":"; got; "not"; want
END SUB

CONST K = 5, BIG = &H1234
count = 7
total = 0
n = 0

' Labels called, their registers in and out
CALL ASM add2, 40: RREG a
ck a, 42, "CALL ASM: ADC #2"
CALL ASM regs, 1, 2, 3: RREG a, x, y, p
ck a * 100 + x * 10 + y, 432, "its registers in and out"
ck p AND 1, 1, "the carry after (RREG's flags)"
CALL ASM add2
RREG a
ck a, 2, "the registers not given: 0"

' The program's names: a variable (its value's address), a CONST (its value)
CALL ASM bump: RREG a
ck count, 8, "INC COUNT + 1: the variable's integer"
ck a, 5, "LDA #K: a CONST"
CALL ASM big: RREG a, x
ck x * 256 + a, &H1234, "<BIG, >BIG"
CALL ASM settotal, 200
ck total, 200, "STA total + 1: a variable in lower case"
CALL ASM settotal, 255
ck total, 255, "again"

' Data in a block: a table, by its index
FOR i = 0 TO 3
    CALL ASM square, 0, i: RREG a
    ck a, i * i, "LDA squares,X"
NEXT

' A block in a SUB; a label in a later block; a macro; .if; cheap and unnamed labels
CALL ASM double, 21: RREG a
ck a, 42, "a SUB's block; a label named as a keyword: ASL A"
CALL ASM far, 9: RREG a
ck a, 10, "JMP to a later block's label"
CALL ASM addten, 1: RREG a
ck a, 11, "a macro"
CALL ASM which: RREG a
ck a, 2, ".if"
CALL ASM sumto, 10: RREG a
ck a, 55, "a loop: @loop, :-"

' A system call from a block (hydra.inc, from /lib/as); a label named as a variable is the block's
SYS "GETPID": RREG p1
CALL ASM pid: RREG p2
ck p2, p1, "JSR GETPID"
CALL ASM n: RREG a
ck a, 77, "a label N, though N's a variable"
ck n, 0, "N itself"

' The blocks' bank: their own, at $8000
CALL ASM where: RREG a, x
ck x * 256 + a, &H8000, "the code's first address"
CALL ASM keep, 99
CALL ASM fetch: RREG a
ck a, 99, "a byte kept in the block's .bss"

PRINT "asm:"; checks; "checks,"; failed; "failed"
END

ASM
first:                          ; (The bank's first byte: where)
add2:   clc
        adc #2
        rts
regs:   phx                     ; .A = .Y + 1, .X = .A + 2, .Y = .X; C set
        tax
        inx
        inx
        iny
        tya
        ply
        sec
        rts
bump:   inc COUNT + 1           ; (count: 7, an integer: its kind 0, then its 4 bytes)
        lda #K
        rts
big:    lda #<BIG
        ldx #>BIG
        rts
settotal:
        stz total               ; (Its kind: an integer's)
        sta total + 1
        stz total + 2
        stz total + 3
        stz total + 4
        rts
square: lda squares,x
        rts
squares: .byte 0, 1, 4, 9
END ASM

SUB helpers
    ASM
double: asl a
        rts
    END ASM
END SUB

ASM
far:    jmp later
.macro  ADDN n
        clc
        adc #n
.endmacro
addten: ADDN 10
        rts
.if K > 3
which:  lda #2
.else
which:  lda #1
.endif
        rts
sumto:  tax                     ; 1 + 2 + ... + .A
        lda #0
@loop:  stx sum
        clc
        adc sum
        dex
        bne @loop
        rts
.include "hydra.inc"
pid:    jsr GETPID
        rts
n:      bra :+                  ; (An unnamed label)
        lda #1
:       lda #77
        rts
where:  lda #<first
        ldx #>first
        rts
keep:   sta kept
        rts
fetch:  lda kept
        rts
END ASM

ASM
later:  inc a
        rts
.bss
sum:    .res 1
kept:   .res 1
END ASM

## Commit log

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2024-09-30 Added surface mount version of memory daughter cards, and lots of schematic updates and fixes, including adding dedicated registers for shared memory bank select at $FFF1 and IRQ vTable entry selecto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
    [AddressDecode.kicad_sch, Clocks.kicad_sch, Connectors.kicad_sch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]
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2024-10-29 Fixing A9 routing on main schematic, and adding new footprint for the DSUB-9 serial connector.
    [AddressDecode.kicad_sch, BankedROM.kicad_sch, Clocks.kicad_sch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]
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2026-03-26 Forth updates: new $F810 entry point, backspace support, fix 0#, new thunk for CLEAR_SCR (TH_CLEARSCR=$F809), and moved Forth code to Forth subdir
    [os_rom_C02.cfg]
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2026-09-26 MMU stage 4: shared memory handles and MM_TASK_RESET
    Shared memory (shared.s)
    - Tables in shared bank ID $00: bank bitmap and run-end bitmap at $8200,
    255-entry shared handle table at $8400. A shared handle is 1 byte, so it
    can be sent in a message.
    - Each entry keeps a 16-bit mask of the tasks holding a reference; the
    banks are freed when the last reference goes.
    - SH_ALLOC (whole 8K banks), SH_ATTACH, SH_DETACH, SH_READ, SH_WRITE,
    SH_LOCK, SH_UNLOCK. Only tasks holding a reference can read or write.
    - SHARED_RAM_INIT probes which U macro-pages have RAM (markers written
    highest first, so U aliasing can't fool it) and reserves missing ones
    and bank IDs $00-$08. Removed the old SH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
    [os_rom_C02.cfg]
2026-09-26 MMU stage 5: HyForth memory from the MMU
    HyForth
    - cold resets the task's MMU area and gets a 2K arena from the MMU for
    small malloc records (FORTH_ARENA_SIZE). MALLOC checks the arena bottom
    and the memory stack and reports out of memory instead of overrunning.
    - Records of 256+ bytes get their own MMU block (type bit MEM_MMU = $40),
    with the same 3-byte header; purge0 frees them via MM_FIND + MM_FREE.
    - Dictionary protection: DICTCHK keeps the MMU page floor
    FORTH_DICT_MARGIN pages above 'here' (before each compiled word, and in
    :, var, cons and bload); a full dictionary gives "out of memory"
    instead of corrupting MMU memory.
    - New words: halloc, hfree, hlock, hunlock, mmtest.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
    [os_rom_C02.cfg]
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2026-09-27 IO step 5: serial driver as the /dev/cons and /dev/ser file server; bad RAM chips left unused
    Serial driver (bios.s, ser_srv.s on ROM page 2)
    - 256-byte RX and TX rings in the serial task; TX is sent from the
    Rockwell ACIA's TDRE interrupt, so output no longer busy-waits. The IRQ
    handler reads the status once (a second read could lose a TDRE).
    - Registers /dev/cons and /dev/ser. cons reads only for the foreground
    task (IO_CTL SER_CTL_FOREGROUND, or SER_CALL_SET_CAPTURE); other readers
    wait. Readers wait on an empty RX ring and writers on a full TX ring,
    woken by the IRQ handler (SER_WAKE / IO_WAKE), race-free.
    - READ_CHAR (still non-blocking) and WRITE_CHAR use fds 0 and 1; task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
    [os_rom_C02.cfg]
2026-09-28 Pipelines, namespaces, console keys, SD card storage; HyForth fixes
    Shell and IO
    - Pipelines: HyForth splits a line at each | (outside q^...^ strings);
    each stage but the last runs in a copy of the shell's task
    (TASK_CLONE: task RAM, task ZP, namespace and fds, like fork) with
    stdout into a pipe; the shell runs the last with stdin from the pipe.
    HyForth cat and wc ( -- lines words chars ); key gives -1 at end of
    file. IO_DUP.
    - Per-task namespaces (ns.s): IO_MOUNT, IO_BIND, IO_UNMOUNT, IO_NS_LIST
    (HyForth mount, bind, unmount, ns), in each task's IO transfer area,
    inherited by new tasks; IO_OPEN resolves names through them (longest
    prefix, binds rewritten up to 4 times).
    - C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
    [os_rom_C02.cfg]
2026-09-28 Cleanup step 1: remove dead code; WDC 65C51 as a build option
    - Message rings (msg.s) removed: pipes and /dev/cons replaced them. The
    system bank mapping is SYS_BANK / _M_SYS_ENTER / _M_SYS_LEAVE in
    defines.s; shared memory reserves only bank IDs $00 and $09, so $01-$08
    are free for SH_ALLOC.
    - Removed: math.s and WRITE_DEC / WRITE_BYTE_MIN, the unused VIA helpers,
    the I2C block, the old WDC / software serial timing constants, ALTBUF,
    stale HyForth address comments.
    - Quiet boot: no COPYTORAM progress dots or addresses, no IRQ vector dump,
    no second clear screen (a driver's FAIL line stays visible).
    - WDC W65C51N ACIA as a build option (SER_ACIA = SER_ACIA_WDC): its TDRE
    doesn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
    [os_rom_C02.cfg]
2026-09-28 Cleanup steps 3-6, task switching, stdio buffering, YM2151 bell, background sound
    Reorganisation:
    - Step 3: the self tests move to ROM page 4; page 1 and page 0 lose their
    fixed offsets; POST checks PAGE1::forth_main. tools/check_pages.js lists
    calls to another ROM page that miss a gate (makeC02.bat runs it).
    - Step 4: build output in bin/ (images) and obj/ (ignored); tmp/ is gone.
    Sources in include/, kernel/, io/, drivers/, tests/, monitor/, tools/;
    bios.s and defines.s split; the shell merged into os_main.s; sound.s has
    its own segment; the old 6502 build removed. ASCII_SEMI was ':'.
    - Step 5: _M_BANK_ENTER/_M_BANK_LEAVE, IO_FD_ENTRY, IO_SRV_COUNT.
    - Step 6: the pipe rings com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
    [os_rom.cfg, os_rom_C02.cfg]
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2026-09-29 HydraFS: the SD card filesystem (build steps 3-5), and faster SPI
    HydraFS, the server for the files on the SD cards (/sd/N/..., the "hfs"
    device, mounted at /sd by the shell), on its own ROM page (6), in the
    storage task on page 3's block layer:
    - Reading: walking paths with . and .., file reads, directory listings
    as text or 48-byte stat records (IO_MODE_STAT), IO_STAT.
    - Writing: files grow a cluster at a time, contiguous when they can;
    IO_CREATE, IO_REMOVE, IO_WSTAT (rename, mode bits), IO_MODE_TRUNC,
    "format" and "label" on /dev/sd/N/ctl. A metadata buffer keeps the
    free map and entries out of the data cache, and writes go in a
    crash-safe order: lost clusters are possible, dou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
    [os_rom_C02.cfg]
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2026-09-30 HyForth's core runs from ROM; far words on page A
    HyForth's interpreter and built-in words (headers and code) run from BIOS
    ROM page 1; only its variables (FORTH_DATA, 89 bytes) are copied to RAM at
    $0800, and the dictionary starts at $0B00. The bulkier words' code, the
    error messages, MALLOC and the disassembler move to a new page A (scope
    FAR inside PAGE1): def_far headers call their code there through FARWORD.
    The debug dump code goes after page 1's thunks; syscall jumps through
    TEMP1 instead of modifying itself. A pipeline's line takes about 37%
    fewer cycles (TASK_CLONE copies about 7.5K less).
    The page checker now also checks gate segments (it missed a fast path
    calling another page'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
    [os_rom_C02.cfg]
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2026-09-30 The YM2151 sound library, a ZSM song player, a test song, and the chip's clock
    Sound moves to BIOS ROM page B (sound/): a shadow of the chip's registers,
    volumes applied to carriers, MIDI notes and bends, the X16's General MIDI
    patches and drum map, and channel claims tied to an open /dev/snd, with
    library commands at the register numbers the chip doesn't have. HyForth
    gets patch, note, noteoff and play; C gets snd.h (tones.c, jukebox.c)
    and hy_kill.
    The song player (page C) plays ZSM files: play song [n] [&], a song run
    by its name, C's snd_play. It is timed by the sound clock, the YM2151's
    timer B at the song's rate (a fast interrupt handler, like the tick's),
    falling back to the system t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
    [os_rom_C02.cfg]
2026-10-01 The ROM and RAM disks, the tasks' areas, program caches, and a reorganized ROM
    The paged ROM is one disk, the ROM disk (/sd/x, bound at /rom): a partition
    table in bank 0, the system's banks in a partition of their own, and a
    read-only HydraFS volume from bank 3 that sim/tools/mkromdisk.js builds from
    romfs.txt and reads back through the emulator's bank mapping, failing the
    build if a file differs. The /rom server, its image format and mkromfs.js
    are gone. A disk's name is one character: SPI devices are hex digits 0-f,
    other disks letters (x, r, s).
    Two RAM disks: r, in the storage task's own banks (/ram), and s, in shared
    banks (/ram/s, served by HydraFS inside /ram so one bind gives both)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
    [hyx.cfg, os_rom_C02.cfg]
2026-10-01 No-card boot into /ram/1, /dev/ram for task 0, and the disks finished
    With no card, the boot shell's current directory is its own area on the
    RAM disk, /ram/1, so files can be saved until a reset, and it runs
    /rom/boot.hys in place of a card's boot.hys. The boot shell binds /rom
    and /ram only when what they stand for is there: a paged ROM image with
    no ROM disk gets no /rom.
    /dev/ram reads the RAM itself as the CPU selects it (every task's 32K,
    the shared RAM by bank ID, every module's banks for every task), read-only
    and for task 0 only; any other task's open is ERR_IO_PERM. The IO self
    test has task 0 read all three kinds through it.
    The test song is a file: sndtest plays /rom/songs/test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
    [os_rom_C02.cfg]
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2026-10-02 /dev/spi: the SPI devices as files, and version 1.8C_0.6
    /dev/spi/N (N = 0-f: the board's headers, then the slots' devices) is
    SPI device N, as Plan 9 has them: a write is one transaction (the
    device selected for its bytes, up to 256 a request), and the bytes that
    come back meanwhile are kept; a read returns them, or with none kept
    clocks in as many as asked (sending $FF) as a transaction of its own.
    /dev/spi/N/ctl reads and sets the mode: 0 (SCLK idles low) or 3 (high);
    1 and 2 aren't supported. One open at a time per device; a device with
    an SD card started is busy, and SD_INIT doesn't start a card on one
    that's open.
    It's served in the storage task, which owns the bus, so a transfer
    neve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
    [os_rom_C02.cfg]
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2026-10-02 /pc, a folder on the PC; / and the devices as directories; a volume
    /pc is a folder on the PC, served over the serial port by the PC tool,
    which is the terminal too: node sim/tools/hydrapc.js COM3 C:\hydra
    [--read-only] (npm install in sim/ for serialport; it raises RTS, which
    the ACIA needs to send). The device pc runs in the serial task
    (servers/pc_srv.s, page D) and sends each H9 request on as a frame;
    the PC answers as HydraFS would (sim/tools/pcfs.js). Frames go between
    the console's bytes ($1E starts one; $1E and $1F escaped; a CRC-16),
    moved by the fast serial handler (serfast.s) ahead of the TX ring and
    out of the RX ring. Damaged or lost frames are sent again (the PC
    answers a repea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
    [os_rom_C02.cfg]
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2026-10-02 Reborn: the kernel core, the build, the emulator tests and spikes S1-S3
    The rebuild from scratch begins under reborn/, by the plan in
    docs/reimplementation-from-scratch.md (phase 0, and phase 1's core):
    - spec/: the system calls and error codes, from which tools/apigen.js
    makes the jump table, hydra.inc, the error texts and the reference
    - kernel/: reset on every BIOS page, the COMMON block, one IRQ path,
    the scheduler (sleepers and blocked callers resolved as it picks),
    SCALL and KCALL, kcopy, tasks and modules run in place from the paged
    ROM, SPAWN/EXITS/WAIT, the polled bring-up console
    - modules/, sdk/asm/: the HYX2 header and link, init and hello
    - build.js, tools/romimg.js, to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
    [bios.cfg, module.cfg]
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2026-10-03 Reborn: HydraFS (#f), phase 3.4, and modules of two banks
    - Modules of two banks (hyx2.inc: HYX2_DRIVER ..., 2; modules/module2.cfg,
    chosen when a module's sources use CODE2): the second bank's code in CODE2
    and RODATA2, reached through FAR2 and FAR1, trampolines in the module's RAM
    that switch its own bank register. romimg places them; HX_LENGTH is the
    length in the last bank; the budget report shows both banks.
    - HydraFS, the old fs/hfs_*.s ported into the storage driver's second bank
    (hfs.s, hfs/*.s), the format unchanged (versions 1 and 2, partitions,
    sparse files): walks, reads, writes, create, remove, wstat, quick and full
    format, label, check and fix; 32 open files. #f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
    [module2.cfg]
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2026-10-04 Reborn: hylang's numbers, phase 7.3; modules of up to four banks
    A module may have four banks now: FARN calls a routine in any of its
    banks from any (the caller's bank set again after), module3.cfg and
    module4.cfg link them (build.js picks by the CODEn segments used), and
    the ROM image keeps a module's banks in one group of 64. The banks3
    test runs a module of three.
    hylang is three banks; its third has danlang's tower:
    - bignum.inc: integers past a fixnum (OT_BIG: a sign and 126 bytes at
    most, some 300 digits), done in four buffers in the task's RAM:
    sums, products, truncated quotients and remainders, Euclid's gcd.
    - numbers.inc: fixed decimals, rationals and complex numbers on them,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
    [module3.cfg, module4.cfg]
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2026-10-04 Reborn: hylang's library modules, hylnum and hylstr
    hylang is a program of two banks (the evaluator and the REPL; the
    reader, the printer and the core's built-ins) and two library modules
    (HT_LIBRARY), each a module of the paged ROM of its own: hylnum, the
    numbers, and hylstr, strings and hashes. They're assembled with
    hylang and run in place in its task, so each calls the others'
    routines through FARN with the library's bank, which hylang finds as
    it starts (MODINFO's module directory, by name).
    Without hylnum, hylang says so and won't start (status 1, as now for
    no room too: returning from main was status 0); without hylstr, its
    built-ins aren't named. The hylibs and hylnum tests.
    A mo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
    [hylang.cfg]
2026-10-05 Reborn: hylang's built-ins partially applied; the library's built in
    danlang changed (its branch feature/items-as-written), and hylang
    with it:
    - A list's items are as they're written: fst, snd, thd, nth and last
    don't evaluate them, nor does what passes them on (map, elem? ...);
    cond and case run their clauses with eval.
    - A built-in given fewer arguments than it needs is partially applied
    (an OT_PBUILT: the built-in and the values given it), but a special
    form; given more than it takes, it's an error, and so is a function
    given more than its formals, unless its body names &_ or &N. What
    each built-in takes is danlang's Arity table's.
    - The library's most used functions are bu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
    [hylang.cfg]
2026-10-05 Reborn: hylang started again; phase 0, the spec
    After a full review of danlang and of the first hylang, hylang is
    being written again from scratch, to the plan "danlang: review and
    65C02 plan" (a Claude Docs document). Phase 0, the spec:
    - danlang, the reference, fixed first (its master, 11b54fe): its
    bugs and quirks, one rule for each inconsistency, a new shorthand
    (seven prefixes, [a b c], callable hashes, $name), &N the extras,
    text as bytes, one argument convention for its built-ins, and
    reference.md, its specification.
    - The first hylang deleted: modules/hylang and its library modules
    hylnum and hylstr, the heap spike's t_heap, /lib/hylang/globals.hl,
    and the hylang, hylib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
    [hylang.cfg]
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2026-10-05 Reborn: hylang's phase 4, the built-ins and lists
    Phase 4 of the plan "danlang: review and 65C02 plan": lists.dl, types.dl and
    library.dl pass but for their checks of phase 5's numbers (and of a hash and
    a stream), with danlang's library loaded from a card.
    danlang first (feature/reader-fixes): map, filter and the folds given what
    isn't a function give the evaluator's error, not a .NET exception (1,182
    checks; library.dl copied over).
    - Room: the most of the RAM code (the heap, the output, the stack, the
    machine's helpers) is now DATA4, kept in the fourth bank and copied to the
    RAM by hylang as it starts (modules/hylang/hylang.cfg: module4.cfg's, with
    DATA4). The first bank, whose DA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
    [hylang.cfg]
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2026-10-06 Reborn: hylang's phase 7, streams, I/O and the system library
    Phase 7 of the plan "danlang: review and 65C02 plan": io.dl and system.dl
    pass, and so does every file of run.dl's, run as a script: 1,198 checks.
    danlang first (feature/reader-fixes): save wrote an empty list {NIL}, which
    loads back as a list holding NIL ({} now), and made a folder that wasn't
    there (:noent now, as write-file's); library.dl's check of (dice+ 2 6 2)
    wanted 4 to 13, so it failed one time in 36 (1,197 checks; io.dl and
    library.dl copied over).
    - Modules of up to eight banks (they were four): sdk/asm/hyx2.inc (its bank
    variables, HYX2_BANKS_INIT, FARN 1-8), modules/module5.cfg ... module8.cfg,
    build.js, tools/r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
    [module5.cfg, module6.cfg, module7.cfg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]
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2026-10-06 Reborn: hylang's phase 9, the Hydra's built-ins
    The Hydra layers begin (the plan's phases 9 to 12, after parity). hylang
    has six banks: the collector moved to the sixth, and the fifth has the
    Hydra's built-ins beside the system library whose helpers they share
    (hydrabi.inc):
    - the system: sysinfo, mods, errstr (a code or its atom)
    - tasks: ps, task-info (hashes: :task :name :state :parent :cpu :group
    :args), yield, sleep-until; hold, a special form: PREEMPT_OFF round its
    body, a frame that takes errors turning it back on (and when the machine's
    stack is given up)
    - memory: peek, poke, peek-word, poke-word, banks, bank-alloc, bank-free,
    bank-read, bank-write, seg-create, seg-attach,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
    [hylang.cfg]
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2026-10-06 Reborn: hylang's bytecode machine, step 1 (vm.inc, a seventh bank)
    A function fun defines is compiled as it's defined, any other at its second
    call, to the code of a small accumulator machine in an arena of RAM banks;
    its frame is its arguments where they were pushed, so a call makes nothing on
    the heap. if, do, and, or, constants, arguments, globals, the fixnum
    operators and built-ins' calls are compiled; the other special forms, fexprs
    and functions not compiled go to the evaluator, whose value comes back
    through a K_VM frame. A scope is made only when something wants one. A
    name's built-in value is counted on only while no frame binds it
    (SF_INLINED); binding it drops the code compiled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
    [hylang.cfg]
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2026-10-07 Reborn: BASIC runs on the system (EhyBASIC as /bin/basic)
    EhyBASIC, Microsoft BASIC 2A, is a module of the paged ROM run in place
    (one bank, 9K), started by rc as basic. docs/basic.md has the conversion;
    in short:
    - its zero page into the program's $22-$7F: what it reads through, names
    as zero-page addresses or indexes as a block stay there, in Microsoft's
    order; the rest to the BSS. CHRGET in ROM, through TXTPTR.
    - the line buffer a page of its own (240 characters), with Microsoft's
    code for a buffer out of the zero page back, and the new line's link
    not looking like the program's end.
    - its I/O the system's (hyio.inc): fd 1 buffered, stdin a line at a time
    (the console's cooke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
    [basic.cfg]
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2026-10-07 Numbers, step 2 (2): the numbers library's skeleton, its bank, its first entries, and its test
    modules/numbers: the numbers library, a module of the paged ROM (HT_LIBRARY),
    run in its caller's task through XCALL. It works in a RAM bank the caller
    gives it (r13, the same for the program's life: its registers, digit and
    text pages, buffers and state, at $8000 while a call runs) and the zero
    page it borrows ($70-$7F, saved and put back). A call keeps the caller's
    bank, zero page and r0-r3, goes back from however deep with an error, reads
    the caller's numbers wherever it has them (its RAM, or its bank at $8000, a
    byte at a time) measuring them by their tags, and writes results with the
    room ch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
    [numbers.cfg]
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2026-10-08 Numbers, step 4: the math functions (the library math, hylang's built-ins)
    sqrt, exp, log, sin, cos, tan, atan, pi and pow of any real power, and digits
    (the precision, 12 at the start, 1 to 100): exact when the answer is, else a
    fixed decimal of the precision's significant digits, correctly rounded (Ziv's
    way: a bound on the error, more bits till the rounding is sure), so danlang
    (feature/numbers 8ba1680, first), numref.js and the library agree to the last
    digit.
    - modules/math: a library module of its own (spec/numbers.def's math), in the
    numbers library's RAM bank, assembling its registers and tower in its own
    bank (nmpow.inc: POW out of nmconv.inc for it); registers R24-R31 on the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
    [math.cfg]
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2026-10-08 The new BASIC: step 7 (its suite, bench.bas, documents; EhyBASIC retired)
    BASIC.md's step 7. modules/nbasic is modules/basic now (/bin/basic), and
    EhyBASIC's module, tests and documents are gone (BASIC.md's answer 1).
    tests/basic: twelve programs that check themselves (495 checks: arith,
    funcs, logic, strings, arrays, flow, procs, records, data, errors, files,
    hydra) and four scripts against their output (errors, print, prompt,
    input): the bsuite test. The basic test is the new BASIC at the console
    and as a shell; bplay's messages are its own. romfs/bench/bench.bas in
    its own style (a FUNCTION each, fib recursive): 14.8 times HyForth's time,
    4.2 times hylang's (EhyBASIC's: 44 and 12.3).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
    [basic.cfg]
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2026-10-08 Numbers' speed, steps 1-3: quick wins, the call, small numbers' own way; BASIC fixes
    Step 1: pi, log 2 and log 10 at 824 bits from the ROM (tools/apigen.js's numconst.inc, from numref.js), put in the
    cache by INIT; m_log10x by shifts; 10^(n-1) and 10^n kept in the state, m_sig's 10^s and 2^(b-1) kept through a
    rounding; the base kept parsed (f_ and w_ the state's: st_fv, st_wf); n_fix0's test of 10 without a division;
    BASIC's \ and MOD of 32-bit integers in the interpreter, an array's first index not multiplied.
    Step 2: the numbers library two banks (text in the second, with its own copies of the calls', registers' and
    tower's code: scope b2, NM_COPY; NM_CODE, NM_RODATA, NMFAR2; HYX2_LIBRARY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
    [numbers.cfg]
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2026-10-09 One disassembler: the asm library, shared by db's d, HyForth's disasm and dis
    The asm library (modules/asm, HT_LIBRARY; spec/asm.def, made by apigen.js into
    its jump table, asmlib.inc's ASMCALL and C's asmdefs.h): DIS, an instruction as
    as writes it (lower case, an address in hex or a name the caller gives, a:
    where as would take the zero page form, .byte for an opcode the W65C02S doesn't
    define), its length, its kind and the address it names; no RAM of its own. Its
    table (w65c02.inc) is as's too, so there is one.
    db calls it through asm.h's dis_insn, symbols in the operands; its tables and
    symbol table gone into the C library's symbol files (lbl.c: in order of address,
    found by halves, a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
    [asm.cfg]
2026-10-09 The assembler's core in the asm library: as a driver of it; entries for a source a line at a time
    as's core (core.s, expr.s, stmt.s: moved from modules/as) is the asm library's
    now, its first bank; the disassembler and its copy of the table its second. A
    library has no RAM: the assembler's state is in RAM its caller lends it while
    it runs (ASM_RAM, $5000-$7DFF), its zero page ($22 on) the caller's, kept and
    put back, as is the caller's RAM bank; its banks are given back as a call ends;
    its messages its own (no toollib). FILE is as's whole work; the as program
    (modules/as) is its arguments, the library found, the call. BEGIN, PASS,
    DEFINE, LINE, END, SYMBOL, IMAGE, DONE and ERROR give a so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
    [asm.cfg]
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

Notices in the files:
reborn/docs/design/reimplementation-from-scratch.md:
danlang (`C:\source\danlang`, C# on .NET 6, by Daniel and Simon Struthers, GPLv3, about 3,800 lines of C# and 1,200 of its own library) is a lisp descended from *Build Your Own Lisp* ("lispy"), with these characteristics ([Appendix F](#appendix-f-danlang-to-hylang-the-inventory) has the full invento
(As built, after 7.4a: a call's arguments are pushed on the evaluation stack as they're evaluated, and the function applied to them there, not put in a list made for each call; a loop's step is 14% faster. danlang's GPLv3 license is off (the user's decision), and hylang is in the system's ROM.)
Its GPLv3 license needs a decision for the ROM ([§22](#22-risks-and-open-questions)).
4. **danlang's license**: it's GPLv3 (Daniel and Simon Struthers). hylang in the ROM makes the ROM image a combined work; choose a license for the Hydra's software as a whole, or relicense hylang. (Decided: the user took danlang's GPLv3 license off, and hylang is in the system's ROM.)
